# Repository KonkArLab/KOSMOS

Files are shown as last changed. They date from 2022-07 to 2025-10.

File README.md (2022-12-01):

# KOSMOS
An underwater observation tool

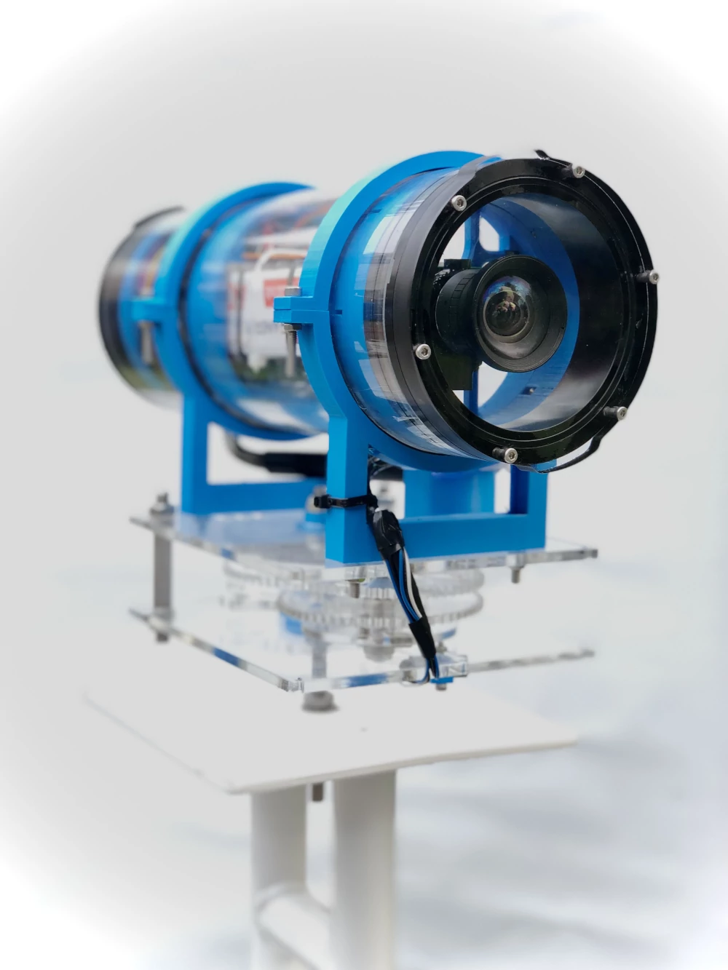
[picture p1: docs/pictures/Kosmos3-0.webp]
Kosmos
 

Cette œuvre est mise à disposition selon les termes de la [Licence Creative Commons Attribution - Pas d’Utilisation Commerciale - Partage dans les Mêmes Conditions 4.0 International.](https://creativecommons.org/licenses/by-nc-sa/4.0/) L'auteur à mentionner est Konk Ar Lab et Ifremer

Le KOSMOS est un programme de sciences participatives née du partenariat atypique
entre une institution scientifique, l’Ifremer, et un Tiers Lieu, le Konk Ar Lab, Fablab de
Concarneau. Cette caméra d’observation de la faune et de la flore sous marine côtière a
permis de réunir autour d’un projet commun, acteurs de la recherche scientifique et de la
société civile.

La fabrication du KOSMOS au Konk Ar Lab est un formidable exemple d’intelligence
collective. Bénévoles et scientifiques collaborent main dans la main afin de concevoir cet
outil en s’assurant qu’il soit reproductible par tous, peu coûteux et scientifiquement
viable, c’est à dire répondant aux exigences du protocole scientifique STAVIRO déjà validé pour l’observation
et le suivi des écosystèmes côtiers.

Ce sont ces trois enjeux qui ont motivé Dominique Pelletier, directrice de recherche
Écologie et Modèles pour l’Halieutique (EMH), à se tourner vers le Konk Ar Lab. En effet,
Dominique a d’ores et déjà développé deux caméras utilisées à travers le monde : le
STAVIRO et le MICADO. Cependant, leur mode de fabrication est limitant et ne permet
pas à tout acteur ou potentiel utilisateur (institution scientifique, parc naturel marin, citoyen) de s’emparer du
projet alors même que les besoins d’évaluation et de suivi sont croissants. Le KOSMOS
offre donc une solution à ce qui semblait être une impasse.

L’Ifremer s’est tourné vers le FabLab de Concarneau en sa qualité de lieu de facilitation
sociale par le numérique. Le Konk Ar Lab, implanté sur le territoire de Concarneau
Cornouailles Agglomération (CCA), est un lieu réunissant tout type de publics locaux
autour de projets numériques et techniques venus de divers horizons. Ce projet est donc
un moyen innovant de partager ses connaissances tant sur des aspects techniques,
mécaniques que biologiques ou écologiques.

Découvrir, partager, sensibiliser sont les thèmes centraux du projet KOSMOS. Un
programme de sciences participatives visant à réunir plaisanciers et scientifiques autour
de l’utilisation de la caméra en mer, verra le jour en 2023. L’objectif est de permettre à tout
un chacun de collecter des vidéos lors de sorties en mer et de les analyser. En offrant
ainsi de nouvelles données aux scientifiques, les observateurs développent ou
approfondissent leur connaissance du milieu côtier et offrent la possibilité de suivre son
évolution sur le long terme.

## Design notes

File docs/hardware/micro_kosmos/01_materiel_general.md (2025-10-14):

icon:material/hammer-screwdriver
# Matériel général

???+ Warning

    Tous les liens vers les sites fournisseurs sont mis à titre indicatif.  
    **Dans le but d'une démarche low tech privilégier la récupération plutôt que l'achat.**

    Certains composants tel que les vis peuvent être modifiés et ne dépendes que de ce que vous avez déjà et de ce dont vous avez besoin.
    Il faut aussi noter que certaines vis sont comprises dans certains kits, dans le tableau ci-dessous vous trouverez toutes les vis nécessaire y compris celles intégrées dans les kits proposés.

    Pour essayer de réduire les imports de produit venant de l'autre bout du monde. Nous avons réaliser un sourcing en essayant de faire attention à ce que les produits soient fabriqués et vendus en Europe. Ce n'est malheureusement pas le cas pour tous. Concernant la visserire nous avons référencer le fabriquant et fournisseur TID Inox, il réalise des ventes à l'unité et est spécialisé dans les commande pour le dIY. Ces prix ne sont intéressant que pour l'achat de petite quantité.

???+ note

    Pour désigner les spécificités d'une vis on utilise des lettres. Ici la lettre M signifie que la vis à un filetage métrique (ISO). Le chiffre qui suit le M correspond au diamètre en mm. La valeur d'après correspond à la longueur du filetage de la vis.

indice substituabilité :  
- :red_circle: : composant non modifiable  
- :orange_circle: : certains paramètres du composant non modifiables  
- :green_circle: : composant modifiable  

## Electronique :
| Partie | Visuel | Référence | Quantité | Dénomination | Usage | Substituabilité | Tips/Conseil |
|---|---|---|---|---|---|---|---|
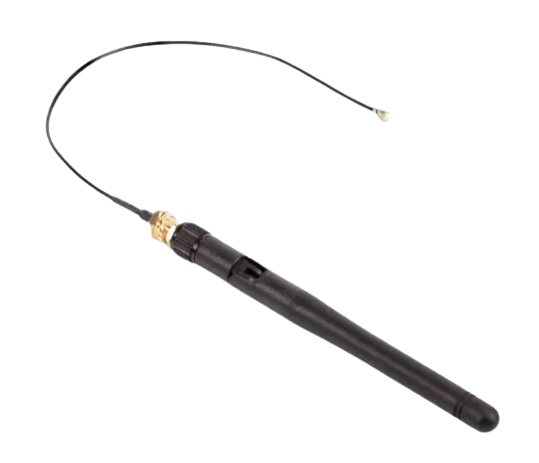
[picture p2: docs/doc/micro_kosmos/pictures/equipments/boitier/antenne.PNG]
antenne
|Boitier Electronique| |[Raspberry  SC0480](https://www.kubii.com/fr/modules-de-reseaux/3087-kit-antenne-officielle-raspberry-pi-3272496303287.html) | 1| Antenne |Permet d'augmenter la portée du signal |<blockquote> :red_circle: </blockquote><br> | |
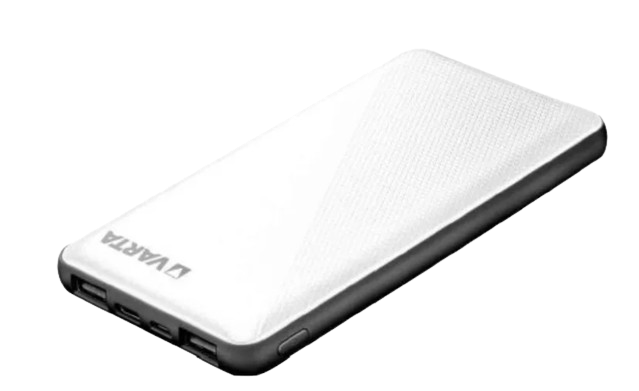
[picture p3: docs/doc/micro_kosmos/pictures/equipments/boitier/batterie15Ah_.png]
batterie
|Boitier Electronique| |[Varta 57977 101 111](https://fr.rs-online.com/web/p/batteries-externes/2309825?gb=s) | 1| batterie 15Ah |Alimente la raspberry |<blockquote> :green_circle: </blockquote><br> | |
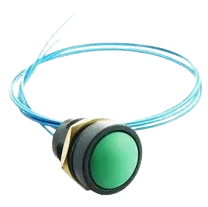
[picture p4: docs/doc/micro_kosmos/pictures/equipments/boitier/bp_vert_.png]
bp
|Boitier Electronique| |[ITW SWITCHES 49-59113](https://fr.farnell.com/itw-switches/49-59113/commutateur-rond-vert/dp/734093?ost=734093) | 1| bouton poussoir vert |"" |<blockquote> :green_circle: </blockquote><br> | |
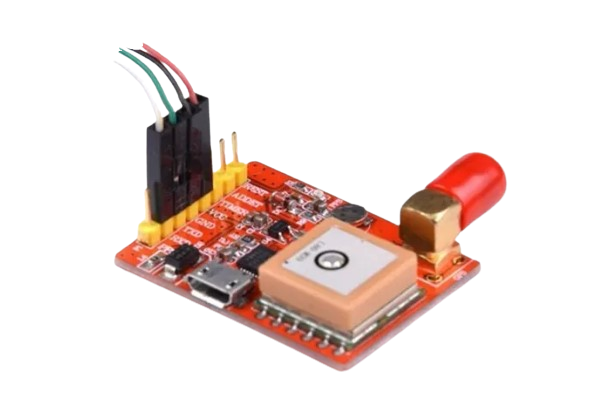
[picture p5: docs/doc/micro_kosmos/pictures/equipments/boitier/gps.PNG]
carte_gps
|Boitier Electronique| |[Raspberry RA168](https://www.kubii.com/fr/modules-de-reseaux/1922-module-gps-pour-raspberry-pi-kubii-3272496007888.html) | 1| carte gps |"" |<blockquote> :red_circle: </blockquote><br> | |
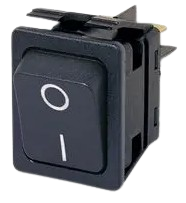
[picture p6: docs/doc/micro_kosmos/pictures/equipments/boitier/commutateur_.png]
commutateur
|Boitier Electronique| |[ARCOLECTRIC (BULGIN LIMITED) C6050ALAAC](https://fr.farnell.com/arcolectric/c6050alaac/commutateur-a-bascule-dpst-noir/dp/7674155)| 1| commutateur + cache étanche |Permet d'allumer et d'éteindre le système |<blockquote> :orange_circle: intérupteur avec auto maintient </blockquote><br> | |
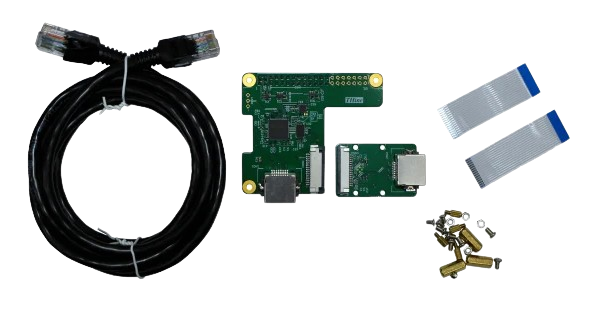
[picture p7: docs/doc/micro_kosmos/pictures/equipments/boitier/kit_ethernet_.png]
kit_ethernet
|Boitier Electronique| |[THine Solutions, Inc. THSER101](https://fr.rs-online.com/web/p/hat-et-complements-raspberry-pi/2206246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) | 1| kit d'extension ethernet |"Permettra à la camera et à la Raspberry de communiquer ensemble" |<blockquote> :red_circle: </blockquote><br> | |
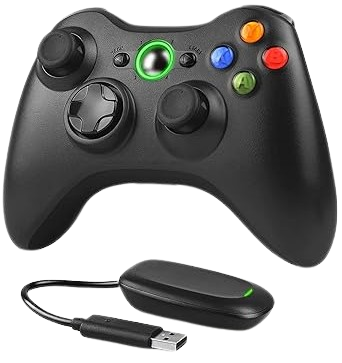
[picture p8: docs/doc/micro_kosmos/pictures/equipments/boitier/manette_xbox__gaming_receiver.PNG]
manette_Xbox
|Boitier Electronique| |[gaming_receiver](https://www.amazon.fr/Dhaose-Contr%C3%B4leur-Vibration-Bluetooth-Ergonomique/dp/B08JGMFRGC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) | 1| Manette Xbox + Wireless gaming receiver |Permet de controller kosmos (mouement, camera)  Permet de faire le lien avec la manète de Xbox et la crte raspberry |<blockquote> :red_circle: </blockquote><br> | |
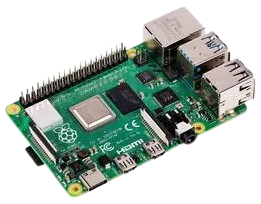
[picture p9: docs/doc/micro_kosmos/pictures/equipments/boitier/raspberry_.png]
raspberry
|Boitier Electronique| |[RASPBERRY-PI RPI4-MODBP-4GB](https://fr.farnell.com/raspberry-pi/rpi4-modbp-4gb/raspberry-pi-4-model-b-4gb/dp/3051887?st=rpi4) | 1| raspberry PI4 4GB |Contient le programme de fonctionnement du µkosmos |<blockquote> :red_circle: </blockquote><br> | |
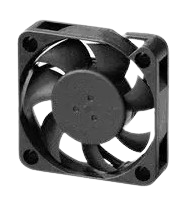
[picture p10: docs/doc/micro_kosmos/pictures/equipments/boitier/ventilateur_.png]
ventilateur
|Boitier Electronique| |[MULTICOMP MC002684](https://fr.farnell.com/multicomp/mc002684/ventilateur-40x40x10mm-5vdc/dp/3050784) | 1| ventilateur 5V |Permet de refroidir le système |<blockquote> :orange_circle: _5V_ </blockquote><br> | |
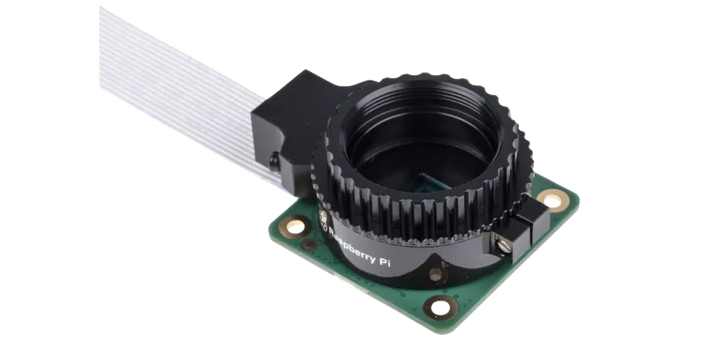
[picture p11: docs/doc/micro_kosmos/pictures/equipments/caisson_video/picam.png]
PiCam
|Caisson vidéo| |[Raspberry Pi SC0261](https://fr.rs-online.com/web/p/cameras-pour-raspberry-pi/2012852?gb=s) | 1| Camera raspberry Pi (Pi Cam) |Camera compatible avec la carte Rasberry Pi |<blockquote> :red_circle: </blockquote><br> | |
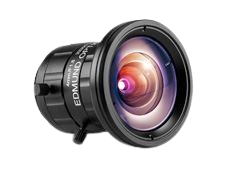
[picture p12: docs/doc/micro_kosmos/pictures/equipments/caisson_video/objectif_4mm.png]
objectif_4mm
|Caisson vidéo| |[TECHSPEC Objectif à distance focale fixe série UC 4mm](https://www.edmundoptics.fr/p/4mm-uc-series-fixed-focal-length-lens/2966/)  | 1| Objectif 4mm |Permet d'améliorer les performance de la Pi Cam |<blockquote> :red_circle: </blockquote><br> | |
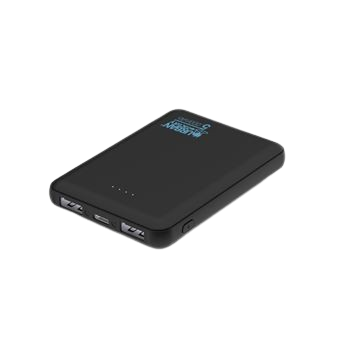
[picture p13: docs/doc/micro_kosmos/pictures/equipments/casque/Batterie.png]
batterie 5000
|Casque| |[Urban Factory UPB05UF](https://www.fnac.com/Batterie-externe-Urban-Factory-UPB05UF-Juicee-Max-Powerbank-5000-mAh-Noir/a16416729/w-4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) | 1| Batterie 500mAh |Alimente l'écran du casque de VR |<blockquote> :green_circle: </blockquote><br> | |
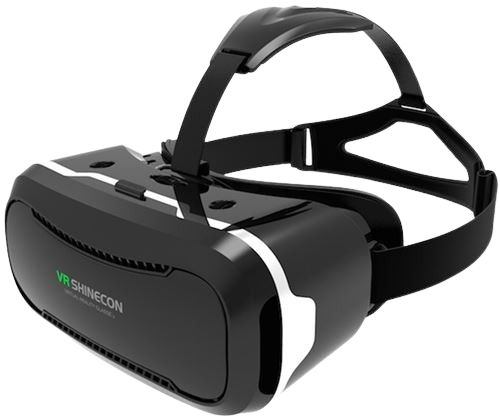
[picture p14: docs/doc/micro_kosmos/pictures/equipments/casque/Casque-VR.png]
casque VR
|Casque| |[EAN 3002637644654](https://www.fnac.com/mp33894226/Casque-VR-pour-Smartphone-Realite-Virtuelle-Lunette-Jeux-Reglage-Universel/w-4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) | 1| Casque de réalité virtuelle |permet de visualiser les image de la caméra |<blockquote> :green_circle: </blockquote><br> |Vous pouvez utiliser un simple écran, mais avec le soleil dehors les écrans sont souvent illisibles. Le casque permet de voir correctement les images; |

## Câble :
|Partie| Visuel | Référence | Quantité | Dénomination | Usage | Substituabilité | Tips/Conseil |
|---|---|---|---|---|---|---|---|
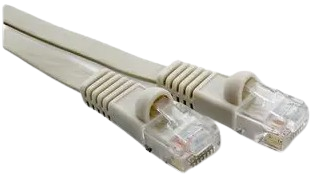
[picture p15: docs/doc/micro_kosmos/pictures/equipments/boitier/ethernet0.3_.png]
eternet0.3
|Boitier Electronique| |[VIDEK 2966-0.3F](https://fr.farnell.com/videk/2966-0-3f/lead-flat-cat6-utp-beige-0-3m/dp/1515103?ost=1515103)  | 1|ethernet 0.3m | Relie carte ethernet au raccord ethernet_externe |<blockquote> :orange_circle: _connectique ethernet_ </blockquote> <br> | |
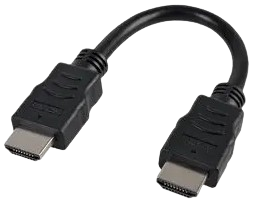
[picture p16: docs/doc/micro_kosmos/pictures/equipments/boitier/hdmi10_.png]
hdmi10
|Boitier Electronique| |[PRO SIGNAL PSG91337](https://fr.farnell.com/pro-signal/psg91337/hdmi-lead-black-0-15m/dp/3400642?ost=3400642)| 1| rallonge HDMI 10cm | Relie la raspberry au bulgin HDMI |<blockquote> :orange_circle: _connectique hdmi_ </blockquote> <br> | |
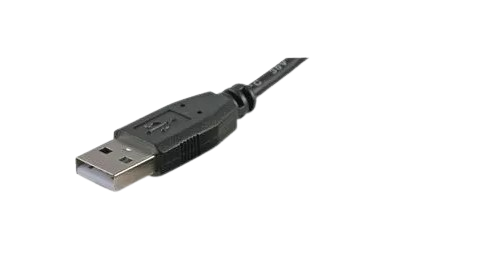
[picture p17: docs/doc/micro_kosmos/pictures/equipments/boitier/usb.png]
usb
|Boitier Electronique| |[KUB06861-NR](https://www.kubii.com/fr/alimentations/1501-1088-mini-cable-blanc-usb-micro-usb-kubii-3272496003491.html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) | 2|cable USB | Relie la batterie au commutateur <br><br> Relie le ventillateur à la carte |<blockquote> :orange_circle: _connectique usb_ </blockquote><br> |Récup <br><br> Seul le connecteur usb est important l'autre bout du cable sera coupé et relier à d'autre petit cable par une soudure |
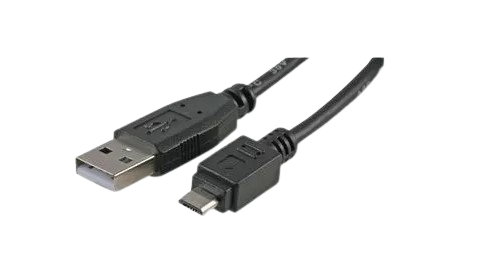
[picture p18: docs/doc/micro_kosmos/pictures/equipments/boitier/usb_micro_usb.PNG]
usb_micro_usb
|Boitier Electronique| |[KUB06861-NR](https://www.kubii.com/fr/alimentations/1501-1088-mini-cable-blanc-usb-micro-usb-kubii-3272496003491.html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) | 1|cable micro USB vers USB | Relie la raspberry à la carte gps |<blockquote> :orange_circle: _connectique usb et micro usb_ </blockquote><br> |Récup |
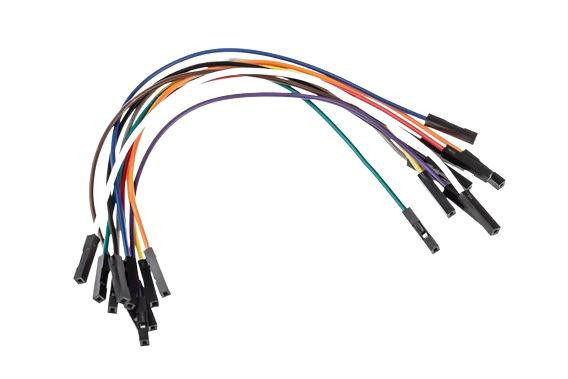
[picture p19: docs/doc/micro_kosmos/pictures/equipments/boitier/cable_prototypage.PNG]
cable_prototypage
|Boitier Electronique| |[JW008FF_DEL](https://www.kubii.com/fr/fils-cables-adaptateurs/1592-1424-kit-fils-cables-jumper-40-200-mm-3272496311220.html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) | 2|cable de prototypage | Relie des pins de la carte aux cables du bouton poussoir  |<blockquote> :green_circle: </blockquote><br> |Récup |
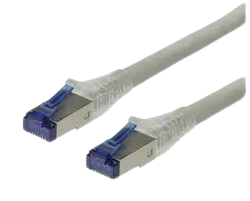
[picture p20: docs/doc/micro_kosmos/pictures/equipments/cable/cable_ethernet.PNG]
cable_ethernet
|Câble| |[ROLINE 	21.15.0871](https://fr.farnell.com/roline/21-15-0871/cordon-de-brassage-rj45-m-m-30m/dp/3003054?ost=21.15.0871) | 1| cable ethernet 15m |Permet "" |<blockquote> :orange_circle: _ethernet_ </blockquote><br> | |
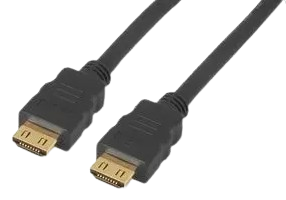
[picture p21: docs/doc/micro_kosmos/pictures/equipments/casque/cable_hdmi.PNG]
cable_hdmi
|Casque|  |[MIGRIP-HDMI-5](https://fr.farnell.com/clever-little-box/migrip-hdmi-5/cable-hdmi-male-male-verrouillage/dp/2373729) | 1|câble hdmi | Relie le casque au boitier électronique |<blockquote> :orange_circle: _connectique hdmi_</blockquote><br> | |
|Casque|usb_micro_usb  |[KUB06861-NR](https://www.kubii.com/fr/alimentations/1501-1088-mini-cable-blanc-usb-micro-usb-kubii-3272496003491.html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) | 1|câble micro usb - USB | Relie l'écran à la batterie |<blockquote> :orange_circle: _connectique usb et micro usb_</blockquote><br> | |

## Connecteur :
|Partie| Visuel | Référence | Quantité | Dénomination | Usage | Substituabilité | Tips/Conseil |
|---|---|---|---|---|---|---|---|
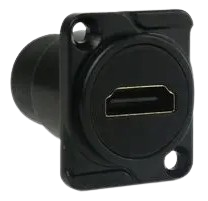
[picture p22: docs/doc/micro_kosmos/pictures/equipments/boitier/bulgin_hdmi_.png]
HDMI femelle/femelle
|Boitier Electronique| |[AMPHENOL AUDIO AC-HDMI-RRB](https://fr.farnell.com/amphenol/ac-hdmi-rrb/adaptateur-hdmi-type-d-fem-fem/dp/2951361?ost=ac-hdmi-rrb) | 1| HDMI femelle/femelle | Permet de connecter la raspberry au casque de Réalité Virtuelle (VR)|<blockquote> :orange_circle: _hdmi vers hdmi_ </blockquote><br> | |
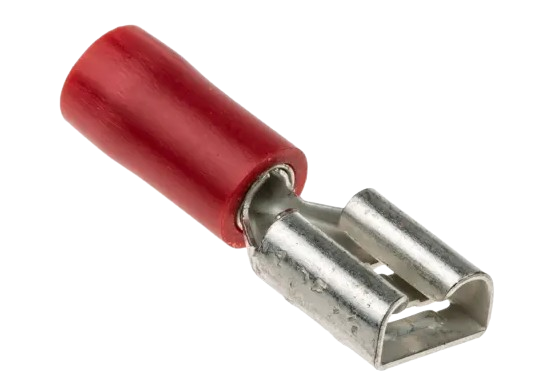
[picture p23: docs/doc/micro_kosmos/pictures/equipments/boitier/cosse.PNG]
cosse
|Boitier Electronique| |[RS PRO 534-339](https://fr.rs-online.com/web/p/cosses-faston/0534339?gb=s) | 4|connecteur cosse | Fait le lien entre les pins du commutateur et les câbles | <blockquote> :green_circle: </blockquote><br> | Les connecteurs cosses sont optionnel. Vous pouvez simplement réaliser des soudures entre les pins et les câbles |
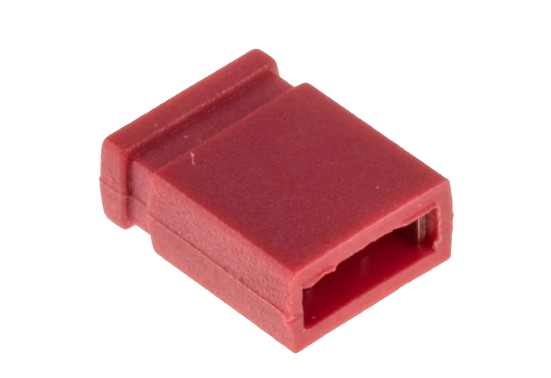
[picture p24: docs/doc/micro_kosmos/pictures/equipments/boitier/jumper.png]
jumper
|Boitier Electronique| |[jumper](https://fr.rs-online.com/web/p/cavaliers-et-shunts/2518531) | 1|jumper | Fait le lien entre deux pins de la carte ethernet pour chager le mode de fonctionnement |<blockquote> :green_circle: </blockquote><br> |Peut être remplacer par un câble de prototypage femelle/femelle |
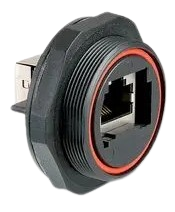
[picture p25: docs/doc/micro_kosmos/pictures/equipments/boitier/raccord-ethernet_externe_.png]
ethernet femelle/femelle
|Boitier Electronique| |[BULGIN LIMITED PX0839/90](https://fr.farnell.com/bulgin/px0839-90/connecteur-coupleur-cat5e-horizontal/dp/1687567?ost=px0839%2F90) | 1| ethernet femelle/femelle | Permet de connecter la carte ethernet au cable ethernet externe |<blockquote> :orange_circle: _ethernet vers ethernet_ </blockquote><br> | |
|Câble|dummy cap |[COB-1003](https://www.bluetrailengineering.com/product-page/cobalt-series-dummy-cap) | 1|capuchon protection cable | Permet de protéger le cable lorsqu'il n'est pas utilisé | <blockquote> :red_circle: </blockquote><br> | |
|Câble|locking sleeve |[COB-1001](https://www.bluetrailengineering.com/product-page/low-profile-locking-sleeve) | 1|fermeture capuchon protection |Permet de protéger le cable lorsqu'il n'est pas utilisé | <blockquote> :red_circle: </blockquote><br> | |
|Câble|ethernet renforcé |[BULGIN LIMITED PX0834/B](https://fr.farnell.com/bulgin/px0834-b/connecteur-precable-rj45/dp/9667733?st=bulgin%20px0834/b) | 1| connecteur ethernet | | <blockquote> :red_circle: </blockquote><br> | |
|Caisson vidéo|kit terminaison |[COB-3180-SS](https://bluerov-solutions.com/produkt/cobalt-series-cable-termination-kit-regular/) | 1|8 pin terminaison kit |Protège le connecteur lorsque le cable n'est pas branché  Une partie du kit est utiliser sur la cable |<blockquote> :red_circle: </blockquote><br> | |
|Caisson vidéo|8pin |[COB-1180-R1](https://www.bluetrailengineering.com/product-page/cobalt-series-bulkhead-connector) | 1| Connecteur 8 pin |Permet de faire le lien avec le "cable" et la carte de la PiCam |<blockquote> :red_circle: </blockquote><br> | |

## Mécanique :
|Partie| Visuel | Référence | Quantité | Dénomination | Usage | Substituabilité | Tips/Conseil |
|---|---|---|---|---|---|---|---|
|Boitier ELectroniquqe|boitier |[MULTICOMP PRO G3008](https://fr.farnell.com/multicomp/g3008/boitier-abs-240x160x90mm-ip65/dp/1526644?st=boitier%20ip65%20240%20mm)| 1| boitier 240 * 160 * 90 |Abrite les élément électroniques |<blockquote> :red_circle: </blockquote><br> | |
| | | 4| pied |Permet d'avoir la boite à plat |<blockquote> :green_circle: </blockquote><br> |Récup |
|Caisson vidéo|flange_cap |[BR-100276-002](https://bluerobotics.com/store/watertight-enclosures/locking-series/wte-end-cap-vp/) | 1| 2'' Flange Cap Aluminium 2 * M10 hole |Ferme le bas du tube, les deux ouverture permettrons de mettre la valve de pression et le connecteur 8pin |<blockquote> :red_circle: </blockquote><br> | |
|Caisson vidéo|oRing_flange |[BR-100628-998](https://bluerobotics.com/store/watertight-enclosures/2-series/wte-flange-vp/) | 1| 2'' O-Ring Flange |Ferme le haut du tube |<blockquote> :red_circle: </blockquote><br> | |
|Caisson vidéo|transparent_cap |[BR-100094](https://bluerobotics.com/store/watertight-enclosures/2-series/wte-end-cap-vp/) | 1| 2'' End Cap Acrylic |S'assemble sur O-Ring Flange pour fermer le haut du tube |<blockquote> :red_circle: </blockquote><br> | |
|Caisson vidéo|tube_etanche |[BR-100534-100](https://bluerobotics.com/store/watertight-enclosures/locking-series/wte-locking-tube-r1-vp/) | 1| tube étanche diametre: 50mm  longueur: 100mm  + 2 socles |Abrite l'installation de la camera |<blockquote> :red_circle: </blockquote><br> | |
|Caisson vidéo|connecteur pression |[BR-100804](https://bluerobotics.com/store/cables-connectors/penetrators/vent-asm-r1/) | 1| valve de pression |"Permet de purger le dispositif" |<blockquote> :red_circle: </blockquote><br> | |
|Trépied|plaque |[RS PRO 178-239](https://fr.rs-online.com/web/p/feuilles-metalliques/0178239?gb=s) | 1| plaque métalique 30mm*100mm | protège le socle supérieur pour fixer l'anneau d'attache |<blockquote> :green_circle: </blockquote><br> | |
|Trépied|plomb |[CAPERLAN 8655063](https://www.decathlon.fr/p/plomb-maquereau-long-peche-en-mer/_/R-p-335078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) | 3| plomb maquereau 600g | Ajoute du poids pour que le système coule et reste stable au fond de l'eau |<blockquote> :green_circle: </blockquote><br> | |
|Trépied|tube_alu |[3232630508800](https://www.mr-bricolage.fr/tube-rond-aluminium-16x1mm-1m-brut-cqfd.html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) | 2m| tube alu 16*1mm | Permettra de réaliser les pieds |<blockquote> :green_circle: </blockquote><br> | |

## Impression 3D :
|Partie| Visuel | Référence | Quantité | Dénomination | Usage |Substituabilité | Tips/Conseil |
|---|---:|---|---|---|---|---|---|
|Caisson vidéo|support |[support_carte](../../hardware/micro_kosmos/3Dprint_files/caisson_video/Support_carte_caisson.stl)| 1| support carte |Permet de fixer la carte ethernet |<blockquote> :red_circle: </blockquote><br> | |
|Casque|support_top_batterie |[support_top_batterie](../../hardware/micro_kosmos/3Dprint_files/casque/Support_batterie_BOT.stl)| 1| Support supérieur batterie |Partie haute de la boite dans laquelle la batterie sera maintenue |<blockquote> :red_circle: </blockquote><br> | |
|Casque|support_boy_batterie |[support_bot_batterie](../../hardware/micro_kosmos/3Dprint_files/casque/Support_batterie_TOP.stl)| 1| Support inférieur batterie |Partie basse de la boite dans laquelle la batterie sera maintenue |<blockquote> :red_circle: </blockquote><br> | |
|Casque|support_ecran |[support_ecran](../../hardware/micro_kosmos/3Dprint_files/casque/Support_ecran.stl)| 1|Support de l'écran |boite dans laquelle l'ecran sera maintenue |<blockquote> :red_circle: </blockquote><br> | |
|Trépied| Trepied_inf |[Trepied_SocleInferieur](../../hardware/micro_kosmos/3Dprint_files/trepied/Trepied_SocleInferieur.stl) | 1| partie basse |Piece dans laquel seront fixer les pieds |<blockquote> :red_circle: </blockquote><br> | |
|Trépied| Trepied_sup |[Trepied_SocleSupérieur](../../hardware/micro_kosmos/3Dprint_files/trepied/Trepied_SocleSupérieur.stl) | 1| partie haute |Piece qui permettra d'attacher l'anneau d'accroche |<blockquote> :red_circle: </blockquote><br> | |
|Trépied| Collier_inf |[Trepied_CollierInférieur](../../hardware/micro_kosmos/3Dprint_files/trepied/Trepied_CollierInférieur.stl) | 2| Ber* |Piece inférieur de maintient du tube étanche |<blockquote> :red_circle: </blockquote><br> | |
|Trépied| Collier_sup |[Trepied_CollierSupérieur](../../hardware/micro_kosmos/3Dprint_files/trepied/Trepied_CollierSupérieur.stl) | 2| fermeture du Ber |Piece suppérieur de maintient du tube étanche |<blockquote> :red_circle: </blockquote><br> | |

## Visserie :
|Partie| Visuel | Référence | Quantité | Dénomination | Usage | Substituabilité | Tips/Conseil |
|---|---|---|---|---|---|---|---|
|Boitier Electronique|ecrou_m3 |[RS PRO 189-563](https://fr.rs-online.com/web/p/ecrous-hexagonaux/0189563) | 6|écrou M3 |Permet fixer le bulgin hdmi et  le ventilateur |<blockquote> :green_circle: </blockquote><br> | |
|Boitier Electronique|vis_m2.5_5mm |[RS PRO 908-7649](https://fr.rs-online.com/web/p/vis-a-metaux/9087649) | 3|vis M2.5 * 5 mm |Permet de fixer la carte Ethernet avec la carte Raspberry |<blockquote> :orange_circle: _M2.5_ </blockquote><br> |Récup |
|Boitier Electronique|vis_m2.5_6mm |[RS PRO 526-928](https://fr.rs-online.com/web/p/vis-a-metaux/0526928) | 4|vis M2.5 * 6 mm |Permet de fixer la carte raspberry au boitier |<blockquote> :orange_circle: _M2.5_ </blockquote><br> | |
|Boitier Electronique|vis_m3_8mm |[RS PRO 914-1942](https://fr.rs-online.com/web/p/vis-a-metaux/9141942) | 2|vis M3 * 8 mm |Permet de fixer le bulgin hdmi |<blockquote>:green_circle:</blockquote><br> | |
|Boitier Electronique|vis_m3_16mm |[RS PRO 560-619](https://fr.rs-online.com/web/p/vis-a-metaux/0560619) | 4|vis M3 * 16 mm |Permet de fixer le ventilateur |<blockquote>:green_circle: </blockquote><br> | |
|Boitier Electronique|vis_m4_16mm |[RS PRO 190-513](https://fr.rs-online.com/web/p/vis-a-metaux/0190513) | 6|vis M4 * 16 mm |Permet la fermeture du boitier |<blockquote> :orange_circle: _M4_ </blockquote><br> | |
|Boitier Electronique|entretoise_filetee_15 |[RS PRO 184-286](https://fr.rs-online.com/web/p/entretoises-filetees/1842896) | 4|entretoise filetée M2.5 * 15 mm |Permet de surelever la carte raspberry |<blockquote> :orange_circle: _M2.5_ </blockquote><br> | |
|Boitier Electronique|entretoise_filetee_6  |[RS PRO 184-3014](https://fr.rs-online.com/web/p/entretoises-filetees/1843014) | 4|entretoise filetée  M2.5 * 6 mm |Permet de surelever la carte ethernet |<blockquote> :orange_circle: _M2.5_ </blockquote><br> | |
|Cable|manille |[RS PRO 124-4849](https://fr.rs-online.com/web/p/manilles/1244849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,+Stockage+et+manutention-_-1244849&matchtype=&pla-2260779340447&gad_source=1&gclid=EAIaIQobChMI7YCP0uXQhAMVzj8GAB0ZgAvmEAQYASABEgLiavD_BwE&gclsrc=aw.ds) | 3| manille |Permet d'accrocher un bout et de tirer sur le dispositif sans détériorier le cable et le connecteur | <blockquote> :green_circle: </blockquote><br> | |
|Caisson vidéo|ecrou_m1.6 |[RS PRO 179-5726](https://fr.rs-online.com/web/p/ecrous-hexagonaux/1795726) | 4|écrou M1.6 | |<blockquote> :red_circle: </blockquote><br> | |
|Caisson vidéo|ecrou_m3 |[RS PRO 189-563](https://fr.rs-online.com/web/p/ecrous-hexagonaux/0189563) | 12|écrou M3 |Permet d'assembler la carte ethernet, son support et la pi cam  |<blockquote> :red_circle: </blockquote><br> | |
|Caisson vidéo|vis_m1.6_10mm |[RS PRO 179-5696](https://fr.rs-online.com/web/p/vis-a-metaux/1795696) | 4|vis M1.6 * 10mm |Permet de fixer la carte ethernet à son support | <blockquote> :red_circle: </blockquote><br> | |
|Caisson vidéo|vis_m3_40 |[RS PRO 914-1652](https://fr.rs-online.com/web/p/vis-a-metaux/9141652) | 4|vis M3 * 40mm |Permet de fixer la Pi Cam au flange cap du tube |<blockquote> :red_circle: </blockquote><br> | |
|Casque| ecrou_m2 |RS PRO 248-4551 | 9|écrou M2 | | |
|Casque| vis_m2_4mm |[RS PRO 914-1624](https://fr.rs-online.com/web/p/vis-a-metaux/9141624) | 4|vis M2*4mm |Fixer l'ecran du casque à son support |<blockquote> :green_circle: </blockquote><br> | Récup  |
|Casque| vis_m2_6mm|[RS PRO 526-906](https://fr.rs-online.com/web/p/vis-a-metaux/0526906) | 5|vis M2*6mm |Fixer le boitier de la batterie au casque |<blockquote> :green_circle: </blockquote><br> | Récup |
|Casque|vis_m2_8mm|[RS PRO 914-1475](https://fr.rs-online.com/web/p/vis-a-metaux/9141475) | 4|vis M2*8mm |Fixer le couvercle du boitier de la batterie |<blockquote> :green_circle: </blockquote><br> | Récup |
|Trépied|anneau_m10 |[RS PRO 124-4841](https://fr.rs-online.com/web/p/anneaux-de-levage/1244841?gb=s) | 1| anneau d'accroche M10 A4 |Permet d'attacher un bout au micro kosmos |<blockquote> :green_circle: </blockquote><br> | |
|Trépied|clou |[RS PRO 177-6994](https://fr.rs-online.com/web/p/clous/1776994) | 3| clou |Permetra de crer une butée pour le socle inférieur |<blockquote> :green_circle: </blockquote><br> |peuvent être remplacé  par n'impourte quelle tige temps qu'elle est déformable |
|Trépied|ecrou_m4 |[RS PRO 521-872](https://fr.rs-online.com/web/p/ecrous-hexagonaux/0189579) | 6| écrou M4 | |<blockquote> :green_circle: </blockquote><br> | |
|Trépied|ecrou_m6 |[RS PRO 189-591](https://fr.rs-online.com/web/p/ecrous-hexagonaux/0189591) | 10| écrou M6 | |<blockquote> :green_circle: </blockquote><br> | |
|Trépied|ecrou_frein |[RS PRO 767-832](https://fr.rs-online.com/web/p/ecrous-hexagonaux/0767832) | 8| écrou frein  M6 |Evite au montage de se déserrer |<blockquote> :green_circle: </blockquote><br> |peuvent etre remplacé par un montage écrou contre écrou (auquel cas il faut ajouter 6 écrous M6) |
|Trépied|ecrou_oreilles_m6  |[RS PRO 521-872](https://fr.rs-online.com/web/p/ecrous-a-oreilles/0521872) | 12| écrou oreille M6 |Ecrou placée en bout des tiges filetées |<blockquote> :green_circle: </blockquote><br> | |
|Trépied| | | 1| fil de fer |"réduira le mouvement des pieds" |<blockquote> :green_circle: </blockquote><br> | |
|Trépied|rondelle_m6 |[RS PRO 189-658](https://fr.rs-online.com/web/p/rondelles/0189658) | 24| rondelle M6 | |<blockquote> :green_circle: </blockquote><br> | |
|Trépied|tige filetée |[RS PRO 530-321](https://fr.rs-online.com/web/p/tiges-filetees/0530321?gb=s) | 1m50| tige filletée M6 | Permet de faire le lien entre le socle inférieur et supérieur |<blockquote> :green_circle: </blockquote><br> | |
|Trépied|vis_m4_20mm |[RS PRO 187-1279](https://fr.rs-online.com/web/p/vis-a-six-pans/1871279) | 4| vis M4 * 20mm |Permet d'assembler les partie inférieur et supérieur du support du caisson vidéo |<blockquote> :green_circle: </blockquote><br> | |
|Trépied|vis_m4_35mm |[RS PRO 124-7349](https://fr.rs-online.com/web/p/vis-a-six-pans/1247349) | 2| vis M4 * 35mm |Permet de fixer le support du caisson vidéo au socle supérieur du trépied |<blockquote> :green_circle: </blockquote><br> | |
|Trépied|vis_m6_40mm |[RS PRO 187-1459](https://fr.rs-online.com/web/p/vis-a-six-pans/1871459) | 3| vis M6 * 40mm |Permet de fixer les plombs sur les pieds |<blockquote> :green_circle: </blockquote><br> | |
|Trépied|vis_m10_40mm |[RS PRO 190-383](https://fr.rs-online.com/web/p/vis-a-tete-hexagonale/0190383) | 1| vis M10 * 40mm |Permet de fixer l'anneau d'accroche |<blockquote> :green_circle: </blockquote><br> | |

## Consommable :
|Partie| Visuel | Référence | Quantité | Dénomination | Usage | Substituabilité | Tips/Conseil |
|---|---|---|---|---|---|---|---|
|Boitier Electronique| | | 10cm| gaine thermo retractable |"fait le liaison entre les différents câbles assemblés" |<blockquote> :red_circle: </blockquote><br> |Récup |
|Boitier Electronique| | | 10cm| velcro |Permet de maintenir les composants en place et de pouvoir les enlever facilement si besoin |<blockquote> :green_circle: </blockquote><br> |Récup  <br><br>  Le velcro est optionnel et peut être remplacer par un autre moyen de fixation |
|Câble|gaine dyneema |[]() | 1|gaine dyneema |Permet de créer des points d'accroche | <blockquote> :red_circle: </blockquote><br> | |
|Câble|gaine thermo |[RS PRO 700-4535](https://fr.rs-online.com/web/p/gaines-thermoretractables/7004535?gb=s) | 1|gaine thermo 6mm |Protège les connexions entre les câbles | <blockquote> :red_circle: </blockquote><br> | |
|Câble|![scotch]() |[scotch]() | 1|scotch |Protège les connexions entre les câbles |<blockquote> :green_circle: </blockquote><br> | |
|Casque|mousse_ruban |[RS-PRO 619-1786](https://fr.rs-online.com/web/p/rubans-mousse/6191786)| 1|Mousse ruban |Permet de maintenir certaines pièces et évite de les abimer |<blockquote> :green_circle: </blockquote><br> | |
|Trépied|mousse_ruban |[RS-PRO 619-1786](https://fr.rs-online.com/web/p/rubans-mousse/6191786) | 1| mousse en ruban |Permet d'avoir un contact parfait avec le tube plexy|<blockquote> :green_circle: </blockquote><br> | Peut être remplacer par un morceau de neoprene que l'on colle |
|Trépied|serre cable |[RS PRO 233-465](https://fr.rs-online.com/web/p/serre-cables/0233465?gb=s) | 3|serre cable 150mm  | Maintient les plombs maquereaux |<blockquote> :green_circle: </blockquote><br> | |

## Outils :
| Visuel | Référence | Quantité | Dénomination | Usage | Substituabilité | Tips/Conseil |
|---|---|---|---|---|---|---|
|||||||

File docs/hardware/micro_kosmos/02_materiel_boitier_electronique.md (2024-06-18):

# Materiel Boitier Electronique

## Electronique:
| Visuel | Référence | Quantité | Dénomination | Usage |Substituabilité | Tips/Conseil |
|---:|---|---|---|---|---|---|
|antenne |[Raspberry  SC0480](https://www.kubii.com/fr/modules-de-reseaux/3087-kit-antenne-officielle-raspberry-pi-3272496303287.html) | 1| Antenne |Permet d'augmenter la portée du signal |<blockquote> :red_circle: </blockquote><br> | |
|batterie |[Varta 57977 101 111](https://fr.rs-online.com/web/p/batteries-externes/2309825?gb=s) | 1| batterie 15Ah |Alimente la raspberry |<blockquote> :green_circle: </blockquote><br> | |
|bp |[ITW SWITCHES 49-59113](https://fr.farnell.com/itw-switches/49-59113/commutateur-rond-vert/dp/734093?ost=734093) | 1| bouton poussoir vert |"" |<blockquote> :green_circle: </blockquote><br> | |
|carte_gps |[Raspberry RA168](https://www.kubii.com/fr/modules-de-reseaux/1922-module-gps-pour-raspberry-pi-kubii-3272496007888.html) | 1| carte gps |"" |<blockquote> :red_circle: </blockquote><br> | |
|commutateur |[ARCOLECTRIC (BULGIN LIMITED) C6050ALAAC](https://fr.farnell.com/arcolectric/c6050alaac/commutateur-a-bascule-dpst-noir/dp/7674155)| 1| commutateur + cache étanche |Permet d'allumer et d'éteindre le système |<blockquote> :orange_circle: intérupteur avec auto maintient </blockquote><br> | |
|kit_ethernet |[THine Solutions, Inc. THSER101](https://fr.rs-online.com/web/p/hat-et-complements-raspberry-pi/2206246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) | 1| kit d'extension ethernet |"Permettra à la camera et à la Raspberry de communiquer ensemble" |<blockquote> :red_circle: </blockquote><br> | |
|manette_Xbox |[gaming_receiver](https://www.amazon.fr/Dhaose-Contr%C3%B4leur-Vibration-Bluetooth-Ergonomique/dp/B08JGMFRGC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) | 1| Manette Xbox + Wireless gaming receiver |Permet de controller kosmos (mouement, camera)  Permet de faire le lien avec la manète de Xbox et la crte raspberry |<blockquote> :red_circle: </blockquote><br> | |
|raspberry |[RASPBERRY-PI RPI4-MODBP-4GB](https://fr.farnell.com/raspberry-pi/rpi4-modbp-4gb/raspberry-pi-4-model-b-4gb/dp/3051887?st=rpi4) | 1| raspberry PI4 4GB |Contient le programme de fonctionnement du µkosmos |<blockquote> :red_circle: </blockquote><br> | |
|ventilateur |[MULTICOMP MC002684](https://fr.farnell.com/multicomp/mc002684/ventilateur-40x40x10mm-5vdc/dp/3050784) | 1| ventilateur 5V |Permet de refroidir le système |<blockquote> :orange_circle: _5V_ </blockquote><br> | |

## Cable:
| Visuel | Référence | Quantité | Dénomination | Usage | Substituabilité | Tips/Conseil |
|---:|---|---|---|---|---|---|
|eternet0.3 |[VIDEK 2966-0.3F](https://fr.farnell.com/videk/2966-0-3f/lead-flat-cat6-utp-beige-0-3m/dp/1515103?ost=1515103)  | 1|ethernet 0.3m | Relie carte ethernet au raccord ethernet_externe |<blockquote> :orange_circle: _connectique ethernet_ </blockquote> <br> | |
|hdmi10 |[PRO SIGNAL PSG91337](https://fr.farnell.com/pro-signal/psg91337/hdmi-lead-black-0-15m/dp/3400642?ost=3400642)| 1| rallonge HDMI 10cm | Relie la raspberry au bulgin HDMI |<blockquote> :orange_circle: _connectique hdmi_ </blockquote> <br> | |
|usb |[KUB06861-NR](https://www.kubii.com/fr/alimentations/1501-1088-mini-cable-blanc-usb-micro-usb-kubii-3272496003491.html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) | 2|cable USB | Relie la batterie au commutateur <br><br> Relie le ventillateur à la carte |<blockquote> :orange_circle: _connectique usb_ </blockquote><br> |Récup <br><br> Seul le connecteur usb est important l'autre bout du cable sera coupé et relier à d'autre petit cable par une soudure |
|usb_micro_usb |[KUB06861-NR](https://www.kubii.com/fr/alimentations/1501-1088-mini-cable-blanc-usb-micro-usb-kubii-3272496003491.html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) | 1|cable micro USB vers USB | Relie la raspberry à la carte gps |<blockquote> :orange_circle: _connectique usb et micro usb_ </blockquote><br> |Récup |
|cable_prototypage |[JW008FF_DEL](https://www.kubii.com/fr/fils-cables-adaptateurs/1592-1424-kit-fils-cables-jumper-40-200-mm-3272496311220.html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) | 2|cable de prototypage | Relie des pins de la carte aux cables du bouton poussoir  |<blockquote> :green_circle: </blockquote><br> |Récup |

## Connecteur:
| Visuel | Référence | Quantité | Dénomination | Usage | Substituabilité | Tips/Conseil |
|---:|---|---|---|---|---|---|
|HDMI femelle/femelle |[AMPHENOL AUDIO AC-HDMI-RRB](https://fr.farnell.com/amphenol/ac-hdmi-rrb/adaptateur-hdmi-type-d-fem-fem/dp/2951361?ost=ac-hdmi-rrb) | 1| HDMI femelle/femelle | Permet de connecter la raspberry au casque de Réalité Virtuelle (VR)|<blockquote> :orange_circle: _hdmi vers hdmi_ </blockquote><br> | |
|cosse |[RS PRO 534-339](https://fr.rs-online.com/web/p/cosses-faston/0534339?gb=s) | 4|connecteur cosse | Fait le lien entre les pins du commutateur et les câbles | <blockquote> :green_circle: </blockquote><br> | Les connecteurs cosses sont optionnel. Vous pouvez simplement réaliser des soudures entre les pins et les câbles |
|jumper |[jumper](https://fr.rs-online.com/web/p/cavaliers-et-shunts/2518531) | 1|jumper | Fait le lien entre deux pins de la carte ethernet pour chager le mode de fonctionnement |<blockquote> :green_circle: </blockquote><br> |Peut être remplacer par un câble de prototypage femelle/femelle |
|ethernet femelle/femelle |[BULGIN LIMITED PX0839/90](https://fr.farnell.com/bulgin/px0839-90/connecteur-coupleur-cat5e-horizontal/dp/1687567?ost=px0839%2F90) | 1| ethernet femelle/femelle | Permet de connecter la carte ethernet au cable ethernet externe |<blockquote> :orange_circle: _ethernet vers ethernet_ </blockquote><br> | |

## Mécanique:
| Visuel | Référence | Quantité | Dénomination | Usage |Substituabilité | Tips/Conseil |
|---:|---|---|---|---|---|---|
|boitier |[MULTICOMP PRO G3008](https://fr.farnell.com/multicomp/g3008/boitier-abs-240x160x90mm-ip65/dp/1526644?st=boitier%20ip65%20240%20mm)| 1| boitier 240 * 160 * 90 |Abrite les élément électroniques |<blockquote> :red_circle: </blockquote><br> | |
| | | 4| pied |Permet d'avoir la boite à plat |<blockquote> :green_circle: </blockquote><br> |Récup |

## Visserie:
| Visuel | Référence | Quantité | Dénomination | Usage | Substituabilité | Tips/Conseil |
|---|---|---|---|---|---|---|
|ecrou_m3 |[RS PRO 189-563](https://fr.rs-online.com/web/p/ecrous-hexagonaux/0189563) | 6|écrou M3 |Permet fixer le bulgin hdmi et  le ventilateur |<blockquote> :green_circle: </blockquote><br> | |
|vis_m2.5_5mm |[RS PRO 908-7649](https://fr.rs-online.com/web/p/vis-a-metaux/9087649) | 3|vis M2.5 * 5 mm |Permet de fixer la carte Ethernet avec la carte Raspberry |<blockquote> :orange_circle: _M2.5_ </blockquote><br> |Récup |
|vis_m2.5_6mm |[RS PRO 526-928](https://fr.rs-online.com/web/p/vis-a-metaux/0526928) | 4|vis M2.5 * 6 mm |Permet de fixer la carte raspberry au boitier |<blockquote> :orange_circle: _M2.5_ </blockquote><br> | |
|vis_m3_8mm |[RS PRO 914-1942](https://fr.rs-online.com/web/p/vis-a-metaux/9141942) | 2|vis M3 * 8 mm |Permet de fixer le bulgin hdmi |<blockquote>:green_circle:</blockquote><br> | |
|vis_m3_16mm |[RS PRO 560-619](https://fr.rs-online.com/web/p/vis-a-metaux/0560619) | 4|vis M3 * 16 mm |Permet de fixer le ventilateur |<blockquote>:green_circle: </blockquote><br> | |
|vis_m4_16mm |[RS PRO 190-513](https://fr.rs-online.com/web/p/vis-a-metaux/0190513) | 6|vis M4 * 16 mm |Permet la fermeture du boitier |<blockquote> :orange_circle: _M4_ </blockquote><br> | |
|entretoise_filetee_15 |[RS PRO 184-286](https://fr.rs-online.com/web/p/entretoises-filetees/1842896) | 4|entretoise filetée M2.5 * 15 mm |Permet de surelever la carte raspberry |<blockquote> :orange_circle: _M2.5_ </blockquote><br> | |
|entretoise_filetee_6  |[RS PRO 184-3014](https://fr.rs-online.com/web/p/entretoises-filetees/1843014) | 4|entretoise filetée  M2.5 * 6 mm |Permet de surelever la carte ethernet |<blockquote> :orange_circle: _M2.5_ </blockquote><br> | |

## Consommable:
| Visuel | Référence | Quantité | Dénomination | Usage |Substituabilité | Tips/Conseil |
|---:|---|---|---|---|---|---|
| | | 10cm| gaine thermo retractable |"fait le liaison entre les différents câbles assemblés" |<blockquote> :red_circle: </blockquote><br> |Récup |
| | | 10cm| velcro |Permet de maintenir les composants en place et de pouvoir les enlever facilement si besoin |<blockquote> :green_circle: </blockquote><br> |Récup  <br><br>  Le velcro est optionnel et peut être remplacer par un autre moyen de fixation |

## Outils:
- Tourne vis (Tête différentes en fonction des vis utilisées)
- Perçeuse
- Couronne perçeuse (permet de réaliser les trous pour les connecteurs)
- kit de soudure
- pistolet chauffant ou briquet
- cuteur

(Les images proviennent des sites fournisseurs)

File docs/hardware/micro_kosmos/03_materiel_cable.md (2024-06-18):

# Matériel Cable

## Cable:
| Visuel | Référence | Quantité | Dénomination | Usage |Substituabilité | Tips/Conseil |
|---:|---|---|---|---|---|---|
|cable_ethernet |[ROLINE 	21.15.0871](https://fr.farnell.com/roline/21-15-0871/cordon-de-brassage-rj45-m-m-30m/dp/3003054?ost=21.15.0871) | 1| cable ethernet 15m |Permet "" |<blockquote> :orange_circle: _ethernet_ </blockquote><br> | |

## Connecteur:
| Visuel | Référence | Quantité | Dénomination | Usage |Substituabilité | Tips/Conseil |
|---:|---|---|---|---|---|---|
|dummy cap |[COB-1003](https://www.bluetrailengineering.com/product-page/cobalt-series-dummy-cap) | 1|capuchon protection cable | Permet de protéger le cable lorsqu'il n'est pas utilisé | <blockquote> :red_circle: </blockquote><br> | |
|locking sleeve |[COB-1001](https://www.bluetrailengineering.com/product-page/low-profile-locking-sleeve) | 1|fermeture capuchon protection |Permet de protéger le cable lorsqu'il n'est pas utilisé | <blockquote> :red_circle: </blockquote><br> | |
|ethernet renforcé |[BULGIN LIMITED PX0834/B](https://fr.farnell.com/bulgin/px0834-b/connecteur-precable-rj45/dp/9667733?st=bulgin%20px0834/b) | 1| connecteur ethernet | | <blockquote> :red_circle: </blockquote><br> | |

## Visserie:
| Visuel | Référence | Quantité | Dénomination | Usage |Substituabilité | Tips/Conseil |
|---:|---|---|---|---|---|---|
|manille |[RS PRO 124-4849](https://fr.rs-online.com/web/p/manilles/1244849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,+Stockage+et+manutention-_-1244849&matchtype=&pla-2260779340447&gad_source=1&gclid=EAIaIQobChMI7YCP0uXQhAMVzj8GAB0ZgAvmEAQYASABEgLiavD_BwE&gclsrc=aw.ds) | 3| manille |Permet d'accrocher un bout et de tirer sur le dispositif sans détériorier le cable et le connecteur | <blockquote> :green_circle: </blockquote><br> | |

## Consommable :
| Visuel | Référence | Quantité | Dénomination | Usage |Substituabilité | Tips/Conseil |
|---:|---|---|---|---|---|---|
|gaine dyneema |[]() | 1|gaine dyneema |Permet de créer des points d'accroche | <blockquote> :red_circle: </blockquote><br> | |
|gaine thermo |[RS PRO 700-4535](https://fr.rs-online.com/web/p/gaines-thermoretractables/7004535?gb=s) | 1|gaine thermo 6mm |Protège les connexions entre les câbles | <blockquote> :red_circle: </blockquote><br> | |
|![scotch]() |[scotch]() | 1|scotch |Protège les connexions entre les câbles |<blockquote> :green_circle: </blockquote><br> | |

## Outils
| Visuel | Référence | Quantité | Dénomination | Usage |Substituabilité | Tips/Conseil |
|---:|---|---|---|---|---|---|
|![kit sertissage]() |[kit sertissage]() | 1|kit sertissage câble ethernet |Permet d'assembler le connecteur sur le câble ethernet | <blockquote> :red_circle: </blockquote><br> | |

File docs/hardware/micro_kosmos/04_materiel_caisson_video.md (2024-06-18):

# Materiel caisson vidéo

## Electronique:
| Visuel | Référence | Quantité | Dénomination | Usage |Substituabilité | Tips/Conseil |
|---:|---|---|---|---|---|---|
|PiCam |[Raspberry Pi SC0261](https://fr.rs-online.com/web/p/cameras-pour-raspberry-pi/2012852?gb=s) | 1| Camera raspberry Pi (Pi Cam) |Camera compatible avec la carte Rasberry Pi |<blockquote> :red_circle: </blockquote><br> | |
|objectif_4mm |[TECHSPEC Objectif à distance focale fixe série UC 4mm](https://www.edmundoptics.fr/p/4mm-uc-series-fixed-focal-length-lens/2966/)  | 1| Objectif 4mm |Permet d'améliorer les performance de la Pi Cam |<blockquote> :red_circle: </blockquote><br> | |

## Connecteur:
| Visuel | Référence | Quantité | Dénomination | Usage |Substituabilité | Tips/Conseil |
|---:|---|---|---|---|---|---|
|kit terminaison |[COB-3180-SS](https://bluerov-solutions.com/produkt/cobalt-series-cable-termination-kit-regular/) | 1|8 pin terminaison kit |Protège le connecteur lorsque le cable n'est pas branché  Une partie du kit est utiliser sur la cable |<blockquote> :red_circle: </blockquote><br> | |
|8pin |[COB-1180-R1](https://www.bluetrailengineering.com/product-page/cobalt-series-bulkhead-connector) | 1| Connecteur 8 pin |Permet de faire le lien avec le "cable" et la carte de la PiCam |<blockquote> :red_circle: </blockquote><br> | |

## Mécanique:
| Visuel | Référence | Quantité | Dénomination | Usage |Substituabilité | Tips/Conseil |
|---:|---|---|---|---|---|---|
|flange_cap |[BR-100276-002](https://bluerobotics.com/store/watertight-enclosures/locking-series/wte-end-cap-vp/) | 1| 2'' Flange Cap Aluminium 2 * M10 hole |Ferme le bas du tube, les deux ouverture permettrons de mettre la valve de pression et le connecteur 8pin |<blockquote> :red_circle: </blockquote><br> | |
|oRing_flange |[BR-100628-998](https://bluerobotics.com/store/watertight-enclosures/2-series/wte-flange-vp/) | 1| 2'' O-Ring Flange |Ferme le haut du tube |<blockquote> :red_circle: </blockquote><br> | |
|transparent_cap |[BR-100094](https://bluerobotics.com/store/watertight-enclosures/2-series/wte-end-cap-vp/) | 1| 2'' End Cap Acrylic |S'assemble sur O-Ring Flange pour fermer le haut du tube |<blockquote> :red_circle: </blockquote><br> | |
|tube_etanche |[BR-100534-100](https://bluerobotics.com/store/watertight-enclosures/locking-series/wte-locking-tube-r1-vp/) | 1| tube étanche diametre: 50mm  longueur: 100mm  + 2 socles |Abrite l'installation de la camera |<blockquote> :red_circle: </blockquote><br> | |
|connecteur pression |[BR-100804](https://bluerobotics.com/store/cables-connectors/penetrators/vent-asm-r1/) | 1| valve de pression |"Permet de purger le dispositif" |<blockquote> :red_circle: </blockquote><br> | |

## Impresion 3D:
| Visuel | Référence | Quantité | Dénomination | Usage |Substituabilité | Tips/Conseil |
|---:|---|---|---|---|---|---|
|support |[support_carte](../../hardware/micro_kosmos/3Dprint_files/caisson_video/Support_carte_caisson.stl)| 1| support carte |Permet de fixer la carte ethernet |<blockquote> :red_circle: </blockquote><br> | |

## Visserie:
| Visuel | Référence | Quantité | Dénomination | Usage |Substituabilité | Tips/Conseil |
|---:|---|---|---|---|---|---|
|ecrou_m1.6 |[RS PRO 179-5726](https://fr.rs-online.com/web/p/ecrous-hexagonaux/1795726) | 4|écrou M1.6 | |<blockquote> :red_circle: </blockquote><br> | |
|ecrou_m3 |[RS PRO 189-563](https://fr.rs-online.com/web/p/ecrous-hexagonaux/0189563) | 12|écrou M3 |Permet d'assembler la carte ethernet, son support et la pi cam  |<blockquote> :red_circle: </blockquote><br> | |
|vis_m1.6_10mm |[RS PRO 179-5696](https://fr.rs-online.com/web/p/vis-a-metaux/1795696) | 4|vis M1.6 * 10mm |Permet de fixer la carte ethernet à son support | <blockquote> :red_circle: </blockquote><br> | |
|vis_m3_40 |[RS PRO 914-1652](https://fr.rs-online.com/web/p/vis-a-metaux/9141652) | 4|vis M3 * 40mm |Permet de fixer la Pi Cam au flange cap du tube |<blockquote> :red_circle: </blockquote><br> | |

(Les images proviennent des sites constructeurs)

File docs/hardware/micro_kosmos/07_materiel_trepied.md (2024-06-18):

# Materiel Trépied

## Mécanique:
| Visuel | Référence | Quantité | Dénomination | Usage |Substituabilité | Tips/Conseil |
|---:|---|---|---|---|---|---|
|plaque |[RS PRO 178-239](https://fr.rs-online.com/web/p/feuilles-metalliques/0178239?gb=s) | 1| plaque métalique 30mm*100mm | protège le socle supérieur pour fixer l'anneau d'attache |<blockquote> :green_circle: </blockquote><br> | |
|plomb |[CAPERLAN 8655063](https://www.decathlon.fr/p/plomb-maquereau-long-peche-en-mer/_/R-p-335078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) | 3| plomb maquereau 600g | Ajoute du poids pour que le système coule et reste stable au fond de l'eau |<blockquote> :green_circle: </blockquote><br> | |
|tube_alu |[3232630508800](https://www.mr-bricolage.fr/tube-rond-aluminium-16x1mm-1m-brut-cqfd.html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) | 2m| tube alu 16*1mm | Permettra de réaliser les pieds |<blockquote> :green_circle: </blockquote><br> | |

## Impression 3D:
| Visuel | Référence | Quantité | Dénomination | Usage |Substituabilité | Tips/Conseil |
|---:|---|---|---|---|---|---|
| Trepied_inf |[Trepied_SocleInferieur](../../hardware/micro_kosmos/3Dprint_files/trepied/Trepied_SocleInferieur.stl) | 1| partie basse |Piece dans laquel seront fixer les pieds |<blockquote> :red_circle: </blockquote><br> | |
| Trepied_sup |[Trepied_SocleSupérieur](../../hardware/micro_kosmos/3Dprint_files/trepied/Trepied_SocleSupérieur.stl) | 1| partie haute |Piece qui permettra d'attacher l'anneau d'accroche |<blockquote> :red_circle: </blockquote><br> | |
| Collier_inf |[Trepied_CollierInférieur](../../hardware/micro_kosmos/3Dprint_files/trepied/Trepied_CollierInférieur.stl) | 2| Ber* |Piece inférieur de maintient du tube étanche |<blockquote> :red_circle: </blockquote><br> | |
| Collier_sup |[Trepied_CollierSupérieur](../../hardware/micro_kosmos/3Dprint_files/trepied/Trepied_CollierSupérieur.stl) | 2| fermeture du Ber |Piece suppérieur de maintient du tube étanche |<blockquote> :red_circle: </blockquote><br> | |
*Ber : correspont en marine à la charpente qui maintient un bateau en traveaux 

## Visserie:
| Visuel | Référence | Quantité | Dénomination | Usage |Substituabilité | Tips/Conseil |
|---:|---|---|---|---|---|---|
|anneau_m10 |[RS PRO 124-4841](https://fr.rs-online.com/web/p/anneaux-de-levage/1244841?gb=s) | 1| anneau d'accroche M10 A4 |Permet d'attacher un bout au micro kosmos |<blockquote> :green_circle: </blockquote><br> | |
|clou |[RS PRO 177-6994](https://fr.rs-online.com/web/p/clous/1776994) | 3| clou |Permetra de crer une butée pour le socle inférieur |<blockquote> :green_circle: </blockquote><br> |peuvent être remplacé  par n'impourte quelle tige temps qu'elle est déformable |
|ecrou_m4 |[RS PRO 521-872](https://fr.rs-online.com/web/p/ecrous-hexagonaux/0189579) | 6| écrou M4 | |<blockquote> :green_circle: </blockquote><br> | |
|ecrou_m6 |[RS PRO 189-591](https://fr.rs-online.com/web/p/ecrous-hexagonaux/0189591) | 10| écrou M6 | |<blockquote> :green_circle: </blockquote><br> | |
|ecrou_frein |[RS PRO 767-832](https://fr.rs-online.com/web/p/ecrous-hexagonaux/0767832) | 8| écrou frein  M6 |Evite au montage de se déserrer |<blockquote> :green_circle: </blockquote><br> |peuvent etre remplacé par un montage écrou contre écrou (auquel cas il faut ajouter 6 écrous M6) |
|ecrou_oreilles_m6  |[RS PRO 521-872](https://fr.rs-online.com/web/p/ecrous-a-oreilles/0521872) | 12| écrou oreille M6 |Ecrou placée en bout des tiges filetées |<blockquote> :green_circle: </blockquote><br> | |
| | | 1| fil de fer |"réduira le mouvement des pieds" |<blockquote> :green_circle: </blockquote><br> | |
|rondelle_m6 |[RS PRO 189-658](https://fr.rs-online.com/web/p/rondelles/0189658) | 24| rondelle M6 | |<blockquote> :green_circle: </blockquote><br> | |
|tige filetée |[RS PRO 530-321](https://fr.rs-online.com/web/p/tiges-filetees/0530321?gb=s) | 1m50| tige filletée M6 | Permet de faire le lien entre le socle inférieur et supérieur |<blockquote> :green_circle: </blockquote><br> | |
|vis_m4_20mm |[RS PRO 187-1279](https://fr.rs-online.com/web/p/vis-a-six-pans/1871279) | 4| vis M4 * 20mm |Permet d'assembler les partie inférieur et supérieur du support du caisson vidéo |<blockquote> :green_circle: </blockquote><br> | |
|vis_m4_35mm |[RS PRO 124-7349](https://fr.rs-online.com/web/p/vis-a-six-pans/1247349) | 2| vis M4 * 35mm |Permet de fixer le support du caisson vidéo au socle supérieur du trépied |<blockquote> :green_circle: </blockquote><br> | |
|vis_m6_40mm |[RS PRO 187-1459](https://fr.rs-online.com/web/p/vis-a-six-pans/1871459) | 3| vis M6 * 40mm |Permet de fixer les plombs sur les pieds |<blockquote> :green_circle: </blockquote><br> | |
|vis_m10_40mm |[RS PRO 190-383](https://fr.rs-online.com/web/p/vis-a-tete-hexagonale/0190383) | 1| vis M10 * 40mm |Permet de fixer l'anneau d'accroche |<blockquote> :green_circle: </blockquote><br> | |

## Consommable:
| Visuel | Référence | Quantité | Dénomination | Usage |Substituabilité | Tips/Conseil |
|---:|---|---|---|---|---|---|
|mousse_ruban |[RS-PRO 619-1786](https://fr.rs-online.com/web/p/rubans-mousse/6191786) | 1| mousse en ruban |Permet d'avoir un contact parfait avec le tube plexy|<blockquote> :green_circle: </blockquote><br> | Peut être remplacer par un morceau de neoprene que l'on colle |
|serre cable |[RS PRO 233-465](https://fr.rs-online.com/web/p/serre-cables/0233465?gb=s) | 3|serre cable 150mm  | Maintient les plombs maquereaux |<blockquote> :green_circle: </blockquote><br> | |

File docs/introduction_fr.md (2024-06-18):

icon:material/application-brackets-outline
# Introduction

La présente documentation cherche à permettre à des personnes où des groupes de s'approprier la méthode d'observation participative de la biodiversité sous-marine. Elle cherche à détailler les étapes d'un tel projet allant de la fabrication d'un ou plusieurs systèmes jusqu'au traitement des images en passant par le déploiement et les usages en mer. 

## 1/ Détail de la présente documentation 

La présente documentation est mise en page par [read the doc](https://readthedocs.org/) et hébergé sur [GitHub](https://github.com/). 
Si vous êtes un utilisateur, pour suivre simplement la fabrication nous vous recommandons de rester sur la version read the doc. Si vous souhaitez nous aider et contribuer au projet, rendez-vous sur github après avoir lu la partie de la documentation qui traite de la contribution. 

## 2/ Prérequis informatiques
Toute la documentation du KOSMOS est réalisée dès que cela est possible avec des outils numériques et informatiques libres. Pour pouvoir suivre et éditer cette documentation, il est nécéssaire d'avoir à disposition :

 - Pour suivre les installations et la gestion des données : Un ordinateur sur un OS Unix (Linux, Ubuntu...) ;
 - Pour utiliser la nomenclature : [Libre office](https://doc.ubuntu-fr.org/libreoffice) ;
 - Pour progammer la découpe des engrenages avec la CNC : Se créer un compte sur le logiciel en ligne [Easel](https://www.inventables.com/technologies/easel) ;
 - Pour éditer la documentation : Editeur de texte classique ([gedit](https://doc.ubuntu-fr.org/gedit)) ou pour markdown ([Ghostwriter](https://ghostwriter.kde.org/)) ;
 - Si besoin de modifier les modèles 3D ou visuels : [Fusion 360 (Autodesk) (sur windows ou mac uniquement)la version gratuite pour un usage personnelle suffit](https://www.autodesk.fr/products/fusion-360/personal) ;
 - Pour modifier le dessin du circuit imprimé : [Kicad](https://www.kicad.org/download/ubuntu/);
 - Pour installer la Raspberry pi : [Raspberry pi Imager](https://www.raspberrypi.com/software/) ;
 - Pour les graphismes et le dessin vectoriel nous utilisons [Inkscape](https://doc.ubuntu-fr.org/inkscape) ;

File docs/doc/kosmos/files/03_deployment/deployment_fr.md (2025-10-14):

icon:material/waves
# Déploiement de Kosmos

## 1- Démarage

## 2- Remise en route
Cette partie explique les étapes de remise en route du système KOSMOS après un temps d'unitilisation.

### 2.1- Mise à jour du software
### Vérification de l'OS
- Vérifier la version de l'OS sur la carte SD de la Raspeberry Pi.
La dernière version de l'OS est Debian 12, (si la version est différente de la dernière version, réinstaller l'OS)
- Taper dans un terminal
```
cat /ect/os-release
```

### Vérification du programme
- Vérifier ensuite que le code est à jour
Toujours dans le terminal, vérifier que vous êtes bien sur la branche `dev_stereo` et récupérer la dernière version du code
```
git checkout dev_stereo //Vérifier la branche sur laquelle on se trouve
git pull //Récupérer la dernière version du code
```
- Vérifier que les dossiers CSV et Vidéo de la clé USB sont bien vides pour ne pas avoir de porblème de stockage

### 2.2- Vérification de la partie hardware
### Vérification des engrenages moteur
- Ouvrer le caisson des engrenages du moteur
- Faire tourner les engrenages manuellement pour s'assurer que rien ne bloque

### Mise au point de la caméra

???+ Note

        Pour être optimal, les réglages doivent s'effectuer dans une atmosphère lumineuse

- La première étape consiste à oter le filtre IR présent sur le capteur de la picam afin de maximiser le nombre de photons incidents. Pour cela on peut suivre le [guide](https://www.raspberrypi.com/documentation/accessories/camera.html#filter-removal) proposé par Raspberry.
- Cette étape réalisée, on nettoiera toutes les surfaces avec un chiffon microfibre puis on remontera l'objectif Edmund sur le capteur. Ré-assembler enfin ce module optique sur le système.
- Pour faire la mise au point de la caméra, le système ne sera pas placé dans le caisson. On branchera par ailleurs un écran à la Raspberry pour visualiser ce que filme la caméra.
- Une fois l'écran branché, on allumera le système et on attendra que le système KOSMOS soit en STAND BY.
- Dans l'interface WEB, modifier le paramètre `05_SYSTEM_shutdown` pour le mettre à 0 et effectuer un `Reboot`. Aller ensuite dans l'onglet `Camera` et éteindre arrêter le système KOSMOS en appuyant sur `Shutdown`. (Cette manipulation permet d'arrêter le script KOSMOS sans éteindre la Rpi. La caméra peut ainsi être utilisée.)
- Dans le terminal, taper ```rpicam-hello --timeout 0 ``` Cette instruction permet d'afficher le preview. Pour le quitter il suffira de taper ```Ctrl + C ```
- Ouvrir à fond l'objectif (le petit point blanc devant 1.8) pour avoir une profondeur de champ minimale. Réaliser le focus sur l'infini (par exemple sur les feuilles d'un arbre au loin) avec la bague puis la bloquer solidement. Fermer enfin l'objectif, le petit point blanc sur 6, pour augmenter la profondeur de champ. Bloquer la bague d'ouverture dans cette position. Vérifier que le focus est toujours bon (le fait de serrer les bagues peut parfois les faire bouger.)
- Sortir du preview puis redémarrer la Raspberry Pi. Le soft kosmos va se remettre en route. Dans l'interface web, remettre le paramètre  `05_SYSTEM_shutdown` sur 1. Effectuer un `Reboot` puis éteindre le système avec un `Shutdown`.

### Lubrification des joints

???+ Warning

        Cette étape est indispensable et est à réaliser avec soin, elle assure l'étanchéité du système

- Déviser les connecteurs des caps  
  joints
- Vérifier qu'il n'y ait pas de cheveux sur vos joints  
- Graisser chaque joint (la couche de graisse doit être fine et homogène)  
  graisse
- Reviser les connecteurs sans oublier les joints  
  joints_valve
- Serrer pour assurer l'étanchéité  
  serrage_exte
  serrage_inte

- Déviser les caps des extrémitées (hublot transparent, et caps noir)
- Répéter les opérations ci dessus  
  joint_top

- Enlever les joints autour des "entretoises"
- Répéter les opérations ci dessus  
  joint_entretoise

### Encapsulation
- Fermer le caisson de kosmos  
   

### Vérification du fonctionnement géneral de Kosmos
- Démarrer la caméra
- Connectez vous à l'interface web (10.42.0.1)
- Vérifier les paramètres dans l'onglet config:
   - 00_system_mode :
   - 01_system_record_button_gpio :
   - 02_system_stop_button_gpio :
   - 03_system_led_b :
   - 04_system_led_r :
   - 05_system_shutdown :
   - 06_system_moteur :
   - 10_motor_esc_gpio :
   - 11_motor_power_gpio :
   - 12_motor_button_gpio :
   - 13_motor_vitesse_min : 
   - 14_motor_vitesse_favorite : 
   - 15_motor_pause_time : 
   - 20_csv_step_time : 
   - 21_csc_file_name : 
   - 30_picam_file_name : 
   - 31_picam_resolution_x : 
   - 32_picam_resolution_y : 
   - 33_picam_preview :
   - 34_picam_framérate : 
   - 35_picam_record_time :
   - 36_picam_conversion_mp4 :
   - 37_picam_awb :
     
- Vérifier avec le live que la caméra est positionnée de façon à ce que l'image soit droite
- Démarer une vidéo
- Observer si le moteur tourne correctement
- Arreter la video et vérifier que l'enregistrement c'est bien passé (création d'un fichier cvs et conversion du fichier vidéo h264 en mp4)

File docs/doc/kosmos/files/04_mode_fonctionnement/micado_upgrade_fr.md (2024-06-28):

icon:fontawesome/regular/hourglass-half
# Upgrade au mode Automatique

## 1/ Principe

Le principe du mode MICADO est de pouvoir laisser le KOSMOS en position pendant plusieurs jours. L'objectif n'est pas de le faire tourner pendant toute la durée d'immersion comme pour le mode STAVIRO. Le but du mode MICADO est d'activer le système sur des horaires bien précis rentré par l'utilisateur auparavant et de faire tourner le KOSMOS pendant une durée rentrée au préalable par l'utilisateur ( en général 15 minutes ).  Ce système permet de faire plusieurs prélèvements de vidéos au même endroit sur des plages horaires précises sans à avoir à remonter le KOSMOS entre chaque prise.
Pour réaliser ceci, nous utilisons une carte Adafruit Trinket 1501 reliée à un module RTC. Celle-ci permettra de contrôler l’alimentation du système grâce à un relais. Elle allumera la carte RaspBerry sur les plages horaires rentréesconso par l’utilisateur. Nous sommes obligé d'utiliser une carte auxiliaire car le mode veille de la carte Raspberry consomme énormément. Le gros avantage de cette carte est sa très faible consommation.
Un autre avantage de cette carte est sa toute petite taille : elle mesure 31mm x 15.5mm x 5mm. Elle dispose des ports I2C nécessaires pout être connectée au module RTC et d’une sortie GPIO permettant de contrôler le relais.

## 2/ Réalisation

Pour commencer, un relai brancher en série sur l'alimentation 5v de la raspberry. Ce relai sera piloté par l'arduino. 
Voici le montage entre le module RTC, l’Adafruit et le relais :

MU2-1

La carte Adafruit est assez particulière à programmer. Elle n'est pas 100% compatible avec l'IDE Arduino : Il faut donc opérer quelques astuces. Nous avons rencontré quelques difficultés pour la programmer ; programmer avec Arduino, lancer le téléversement. Vous retrouverez un TUTO très détaillé de ces étapes dans "docs/files/micado_upgrade/TUTO ADAFRUIT 1501.pdf" du git.

A l'emplacement "/docs/files/micado_upgrade" se trouve aussi le code Arduino expliqué permettant de programmer la carte Adafruit sur des plages horaires précises. Ces horaires devant être rentrer par l'utilisateur.

Une fois ces horaires rentrer, l'utilsateur n'a qu'à activer l'alimentation du KOSMOS et le poser au fond. Le KOSMOS va ainsi filmer pendant une période définie par l'utilisateur aux mêmes heures pendant quelques jours. Cela permettra d'avoir une analyse plus étendue d'un même endroit.

## 3/ Notes et pistes d'évolution
 - Cette documentation est une relique et date de l'été 2021. Il constitue une réflexion de base pour construire le mode MICADO final. 
 - Noter que ce système permet d'économiser de l'énergie. En effet, la raspberry même en veille peu consommer 500mA. 
 - Le mode MICADO est déjà activé au software KOSMOS. Il doit démarrer le process immédiatement après démarrage. Pour passer en mode MICADO modifier le variable correspondante dans le fichier "kosmos_config.ini" se trouvant sur la clé usb.

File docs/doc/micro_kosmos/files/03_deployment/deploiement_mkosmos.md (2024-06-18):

icon:material/waves
# Déploiement de µKosmos
    
## 1- Démarage
- Vérifier le position du jumper (mode VR ou mode écran)
- Brancher et Allumer les batteries
- Appuyer sur l'intérupteur du boitier
- Allumer la manette de Xbox
- Appuyer sur le bouton central pour connecter la manette au gaming receiver

## 2- Fonctionnement de la manette de Xbox
#### Vidéo  

- **`Start`** : démarage de la caméra
- **`Back`**: Extinction de la caméra
- **`Guide`**: arrêt du script

#### Réglage AWB  

- **`A`** + :material-arrow-up-down: : Augmente ou diminue le canal rouge
- **`A`** + :octicons-arrow-both-16: : Augmente ou diminue le canal bleu
- **`RightBumper`** : Ajuste automatiquement les canaux rgb (red, green, blue)
- **`LeftBumper`** : Quitte l'auto ajustement
- **`RightTrigger`** : Retour aux gains de référence

#### Réglage de la luminosité et de la saturation 

-  **`X`** + :material-arrow-up-down: : Augmente ou diminue la luminosité
-  **`X`** + :octicons-arrow-both-16:  : Augmente ou diminue le contrast
- **`RightTrigger`** : Retour à luminosité et contraste de référence

#### Réglage compensation de l'exposition, affichage TpsPose, AnalogGain, DigitalGain 

- **`B`** + :material-arrow-up-down: : Augmente ou diminue l'exposition (attention ce n'est pas instantané)
- **`RightTrigger`** : Retour à la référence
- **`LeftTrigger`** : Capture une image
- **`LeftBumper`** : Analyse histo et ratio R/G et B/G (effectué sur la dernière image prise)

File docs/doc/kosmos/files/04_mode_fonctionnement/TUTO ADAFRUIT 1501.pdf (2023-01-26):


TUTO pour se servir de la ADAFRUIT TRINKET 5V :

1) Installer les drivers nécessaire :
- Télécharger l’exécutable d’installation : https://learn.adafruit.com/adafruit-arduino-ide-setup/windows-driver-installation
- Lancer l’exécutable :

Cliquez sur « I Agree ».

Cochez les deux drivers à installer comme ci-dessus.
Cliquez sur installez.
Les drivers sont installés !
Désormais on peut voir dans le « Gestionnaire des périphériques » notre Adafruit :


- Lancez ensuite l’IDE Arduino :
- Allez dans « Fichier > Préférence » :

Ajoutez dans « URL de gestionnaire de cartes supplémentaires » l’URL pour ajouter les cartes Adafruit : https://www.adafruit.com/package_adafruit_index.json
- Cliquez sur « OK »
- Sélectionnez la bonne carte :

- Sélectionnez le bon programmateur :


- Branchez la carte Adafruit au PC :

Lorsque vous téléversez le programme assurez vous que la LED rouge est bien en mode pulsation.

Pour ce faire il suffit d’appuyer sur le bouton poussoir juste avant de téléverser.

Vous pouvez faire un essais avec un programmes très simple pour faire clignoter la LED rouge toutes les 0.5 secondes :


int led = 1; // blink 'digital' pin 1 - AKA the built in red LED

// the setup routine runs once when you press reset:

void setup() {

// initialize the digital pin as an output.

pinMode(led, OUTPUT);

}

// the loop routine runs over and over again forever:

void loop() {

digitalWrite(led, HIGH);

delay(500);

digitalWrite(led, LOW);

delay(500);

}

Si cela fonctionne, votre carte est donc opérationnelle !

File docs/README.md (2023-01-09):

# KOSMOS 3.0

PhotoKOSMOS30

Le KOSMOS est un programme de sciences participatives née du partenariat atypique
entre une institution scientifique, l’Ifremer, et un Tiers Lieu, le Konk Ar Lab, Fablab de
Concarneau. Cette caméra d’observation de la faune et de la flore sous marine côtière a
permis de réunir autour d’un projet commun, acteurs de la recherche scientifique et de la
société civile.

La fabrication du KOSMOS au Konk Ar Lab est un formidable exemple d’intelligence
collective. Bénévoles et scientifiques collaborent main dans la main afin de concevoir cet
outil en s’assurant qu’il soit reproductible par tous, peu coûteux et scientifiquement
viable, c’est à dire répondant au protocole scientifique déjà en vigueur pour l’observation
et le suivi des écosystèmes côtiers.

Ce sont ces trois enjeux qui ont motivé Dominique Pelletier, directrice de recherche
Écologie et Modèles pour l’Halieutique (EMH), à se tourner vers le Konk Ar Lab. En effet,
Dominique a d’ores et déjà développé deux caméras utilisées à travers le monde : le
STAVIRO et le MICADO. Cependant, leur mode de fabrication est limitant et ne permet
pas à tout acteur (institution scientifique, parc naturel marin, citoyen) de s’emparer du
projet alors même que nos besoins d’évaluation et de suivis sont croissant. Le KOSMOS
offre donc une solution non négligeable a ce qui semblait être une impasse.

L’Ifremer s’est tourné vers le FabLab de Concarneau en sa qualité de lieu de facilitation
sociale par le numérique. Le Konk Ar Lab, implanté sur le territoire de Concarneau
Cornouailles Agglomération (CCA), est un lieu réunissant tout type de publics locaux
autour de projets numériques et techniques venus de divers horizons. Ce projet est donc
un moyen innovant de partager ses connaissances tant sur des aspects techniques,
mécaniques que biologiques ou écologiques.

Découvrir, partager, sensibiliser sont les thèmes centraux du projet KOSMOS. Un
programme de sciences participatives visant à réunir plaisanciers et scientifiques autour
de l’utilisation de la caméra en mer, verra le jour en 2023. L’objectif est de permettre à tout un chacun de collecter des vidéos lors de sorties en mer et de les analyser. En offrant ainsi de nouvelles données aux scientifiques, les observateurs développent ou approfondissent leur connaissances du milieu côtier et offrent la possibilité de suivre son évolution sur le long terme.

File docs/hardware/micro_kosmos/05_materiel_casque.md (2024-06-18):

# Materiel Casque

## Electronique:
| Visuel | Référence | Quantité | Dénomination | Usage |Substituabilité | Tips/Conseil |
|---:|---|---|---|---|---|---|
|batterie 5000 |[Urban Factory UPB05UF](https://www.fnac.com/Batterie-externe-Urban-Factory-UPB05UF-Juicee-Max-Powerbank-5000-mAh-Noir/a16416729/w-4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) | 1| Batterie 500mAh |Alimente l'écran du casque de VR |<blockquote> :green_circle: </blockquote><br> | |
|casque VR |[EAN 3002637644654](https://www.fnac.com/mp33894226/Casque-VR-pour-Smartphone-Realite-Virtuelle-Lunette-Jeux-Reglage-Universel/w-4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) | 1| Casque de réalité virtuelle |permet de visualiser les image de la caméra |<blockquote> :green_circle: </blockquote><br> |Vous pouvez utiliser un simple écran, mais avec le soleil dehors les écrans sont souvent illisibles. Le casque permet de voir correctement les images; |

## Cable:
| Visuel | Référence | Quantité | Dénomination | Usage |Substituabilité | Tips/Conseil |
|---:|---|---|---|---|---|---|
| cable_hdmi |[MIGRIP-HDMI-5](https://fr.farnell.com/clever-little-box/migrip-hdmi-5/cable-hdmi-male-male-verrouillage/dp/2373729) | 1|câble hdmi | Relie le casque au boitier électronique |<blockquote> :orange_circle: _connectique hdmi_</blockquote><br> | |
|usb_micro_usb  |[KUB06861-NR](https://www.kubii.com/fr/alimentations/1501-1088-mini-cable-blanc-usb-micro-usb-kubii-3272496003491.html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) | 1|câble micro usb - USB | Relie l'écran à la batterie |<blockquote> :orange_circle: _connectique usb et micro usb_</blockquote><br> | |

## Impresion 3D:
| Visuel | Référence | Quantité | Dénomination | Usage |Substituabilité | Tips/Conseil |
|---:|---|---|---|---|---|---|
|support_top_batterie |[support_top_batterie](../../hardware/micro_kosmos/3Dprint_files/casque/Support_batterie_BOT.stl)| 1| Support supérieur batterie |Partie haute de la boite dans laquelle la batterie sera maintenue |<blockquote> :red_circle: </blockquote><br> | |
|support_boy_batterie |[support_bot_batterie](../../hardware/micro_kosmos/3Dprint_files/casque/Support_batterie_TOP.stl)| 1| Support inférieur batterie |Partie basse de la boite dans laquelle la batterie sera maintenue |<blockquote> :red_circle: </blockquote><br> | |
|support_ecran |[support_ecran](../../hardware/micro_kosmos/3Dprint_files/casque/Support_ecran.stl)| 1|Support de l'écran |boite dans laquelle l'ecran sera maintenue |<blockquote> :red_circle: </blockquote><br> | |

## Visserie:
| Visuel | Référence | Quantité | Dénomination | Usage |Substituabilité | Tips/Conseil |
|---:|---|---|---|---|---|---|
| ecrou_m2 |RS PRO 248-4551 | 9|écrou M2 | | |
| vis_m2_4mm |[RS PRO 914-1624](https://fr.rs-online.com/web/p/vis-a-metaux/9141624) | 4|vis M2*4mm |Fixer l'ecran du casque à son support |<blockquote> :green_circle: </blockquote><br> | Récup  |
| vis_m2_6mm|[RS PRO 526-906](https://fr.rs-online.com/web/p/vis-a-metaux/0526906) | 5|vis M2*6mm |Fixer le boitier de la batterie au casque |<blockquote> :green_circle: </blockquote><br> | Récup |
|vis_m2_8mm|[RS PRO 914-1475](https://fr.rs-online.com/web/p/vis-a-metaux/9141475) | 4|vis M2*8mm |Fixer le couvercle du boitier de la batterie |<blockquote> :green_circle: </blockquote><br> | Récup |

## Consommable:
| Visuel | Référence | Quantité | Dénomination | Usage |Substituabilité | Tips/Conseil |
|---:|---|---|---|---|---|---|
|mousse_ruban |[RS-PRO 619-1786](https://fr.rs-online.com/web/p/rubans-mousse/6191786)| 1|Mousse ruban |Permet de maintenir certaines pièces et évite de les abimer |<blockquote> :green_circle: </blockquote><br> | |

(Les images proviennent des sites fournisseurs)

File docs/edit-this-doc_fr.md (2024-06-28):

icon:material/application-edit-outline
# Éditer cette documentation

## 1/ Introduction
|||
|-|-|
|Cette documentation est mise en page par ReadTheDocs.org et [lisible à l'adresse ci attaché](https://kosmos30.readthedocs.io). En aucun cas, cette adresse permet d'éditer la documentation.|ED1-1|
|Afin de pouvoir contribuer à cette documentation, vous pouvez contribuer directement au [repository GitHub](https://github.com/KonkArLab/KOSMOS).|ED1-2|

C'est sur GitHub que sont déposés les fichiers sources. On y retrouve l'arborescence suivante : 

 - **docs :** Est le dossier qui contient les documents qui pourront être affichés sur le read the doc. Dans ce dossier sont entreposés :

   - A la racine les fichiers marckdown qui sont les textes de la documentation. Pour chaque onglet sur read the doc nous ajouterons un fichier séparé avec un titre en Anglais sans espaces terminé par "_fr" pour la version française ou "_en" pour le version anglaise. L'extention sera toujours ".md".
   - Le dossier "pictures" : Qui contient plusieurs dossiers dont chacun porte un nom en rapport avec le fichier marckdown auquel il se rapporte. Ainsi pour un fichier de doccumentation "test1_fr.md" on prendra le soin d'entreposer les images dans un dossier "/docs/pictures/test1".

 - **Hardware :** Qui est le dossier qui contient les fichiers d'impressions 3D, de découpe laser...  

Avant de faire une proposition de contribution, il est bienvenue d'éditer le repository depuis votre compte en effectuant un forke de la présente documentation. Une fois que vous aurez une version prête à être publiée il suffira de faire une pull request au "main project" soit celui du konkarlab/KOSMOS.
C'est un administrateur KOSMOS qui étudiera votre proposition pour en intégrer tout ou partie sur le projet. 

## 2/ Édition (généralités)

### 2.1 Écriture en Marckdown
Le Marckdown est un langage de mise en forme de texte très simplifié. On peut éditer un fichier ".md" directement via gitHub ou en local de son ordinateur avec n'importe quel éditeur de texte. Cependant nous recommandons [Ghostwriter](https://wereturtle.github.io/ghostwriter/) qui présente l'avantage proposer une vue en direct du rendu (aperçu HTML).

[Pour ce qui est de la syntaxe, consulter ce guide](https://www.markdownguide.org/basic-syntax/)

### 2.2 Ajout et mise à jour d'une image

#### 2.2.1 Ajout
Les images que l'on souhaite faire apparaître dans la documentation ne doivent pas être collées dans le document. 

 - Créer un nouveau dossier du même nom que la documentation dans "/docs/pictures/" en créant un fichier vide que l'on suprimera par la suite.
 - Importer les images désirées que l'on aura préalablement réduites en taille chacune en dessous de 200Ko et renommées de manière à être facilement identifiables. 
 - On pourra par la suite supprimer le fichier vide qui nous aura servi à créer le dossier.
 - Dans le fichier de documentation corespondant à la ligne où l'on souhaite faire apparaître l'image, ajouter la ligne suivante : 
 ```Legende_Image``` 

#### 2.2.2 Mise à jour 
Pour mettre à jour une image, il suffit de supprimer du git l'image en question et d'uploader la nouvelle image en prenant soin de renommer cette nouvelle image avec le nom exact de l'ancienne. 

## 3/ Édition du dépôt en locale (Intermédiaire)
Cette méthode permet de cloner l'archive disponible sur github sur un disque dure. Ainsi on pourra facilement modifier les différents fichiers mais aussi l'arborescence sans nécéssiter de connexion internet mais surtout cela va permettre de préparer une version qui pourra par la suite faire l'objet d'un pull request. 
Toute la démarche décrite ci-dessous est valable uniquement pour un usage depuis un ordinateur sous Linux. Il existe nécéssairement des équvalent pour les autres OS mais que je nous ne connaissons pas).

### 2.1 Installer Git et préparer le terrain
 - Sur votre disque dure, définir l'espace où sera stocké le dépôt. Sachez qu'un dépôt GitHub peut peser jusq'à 500Mo. De préférence définir un dossier vide. **Attention* A ce qu'aucun dossier ou sous-dossier du chemin ne comporte de caractères spéciaux ou d'espaces. Remplacer tous les espaces par des underscore "_". 
 - Ouvrir un terminal ('Ctrl + Alt + t' sur Unbuntu).
 - Dans le cas où le paquet "git" n'est pas déjà installé sur votre PC, lancez l'installation de git :  ```sudo apt install git``` (Cette action nécessite une connexion internet).

### 2.2 Cloner le dépôt sur son disque dure
 - Ouvrir une page web avec le git que l'on souhaite cloner
 - Y copier le code "https" que l'on trouvera dans l'onglet déroulant "code" en haut à droite. Pas besoin de le chercher pour le repository KOSMOS, le lien est : https://github.com/KonkArLab/KOSMOS.git
 - Dans un terminal se diriger vers l'espace prévu pour coller le dépôt. Utiliser la commande ```cd puis_chemin/de_votre_dossier```
 - Cloner le dépôt git en utilisant la commande ```git clone https://github.com/KonkArLab/KOSMOS.git``` Prendre soin de remplacer l'url par celui du dépôt désiré si il est différent du notre. 
 - Le clonage va prendre quelques minutes et va coller tous les fichiers et l'arborescence dans votre répertoire.

### 2.3 Modifier le dépôt
 - Sur votre poste de travail, modifiez tous les fichiers nécessaires, déposer des fichiers, suprimez en...
 - Avant de commencer à travailler peut-être que le dépôt en ligne a été modifié depuis votre dernière mise à jour. Pour mettre à jour votre dépôt en local. Se positionner tout d'abord dans le dépôt ```cd NomduDepot``` Puis effectuer un "Pull" ```git pull```
 
### 2.4 Proposer des modifications
Si vous avez effectué des modifications, il peut-être utile de les proposer en modification au projet. Mais avant cela il peut-être utile de créer une nouvelle branche ou de faire cela depuis votre fork. 
 - Pour ajouter l'ensemble des fichiers à la liste des fichiers à commiter : ```git add *```
 - Commiter ```git commit -m "commentaire associé au commit" git@git.cru.fr:nom_projet.git nom_branche (par défaut master représentant la branche principale)```
 - Enfin pousser votre travail ```git push```

## Liens connexes
 - [Documentation Git](https://git-scm.com/about)
 - [Formation vidéo à Git](https://youtube.com/playlist?list=PLjwdMgw5TTLXuY5i7RW0QqGdW0NZntqiP)

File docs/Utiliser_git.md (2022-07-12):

## Formation Git 

### Initier un git

 - git init est une commande qui permet d'initier un git
 - A la base le dépôt est vide
 - Écrire des choses dans un fichier. (Modifier ce qui est dans le dossier de GIT)
 - git add permet d'indiquer une modification de sauvegarde. "Maintenant j'observe les fichiers à observer"

### Sauvegarder le Git
 - git commit : sauvegarder les modifications apportées. "Va aller dans les fichiers à observer et va enregistrer les modifications qui ont été faites"
 - Sauvegarder une version (git tag). Nomme un nom de commit en nom de version

### Travail en parallèle

 - git branch, sauvegarder plusieurs modifications à partir d'une version. 
 - git checkout pour changer de branche (ajouter argument branche ou master).
 - git merge : remettre le contenu d'une branche se remet dans la branche principale. La branche continue à exister 
 - On ne fait pas de commit sur la branche master (en général en informatique)
 - Chaque contributeur travail indépendamment sur une branche
 - le merge fait comme un commit (ce qui fait qu'il peut demander de résoudre des conflits)
 - Ce qui veut dire qu'il faut tout de même se coordonner et ne pas travailler sur le même fichier. 

### Préparer un répertoire en ligne

 - git remote configurer une destination à distance (remote) pour le git
 - git push envoie la version actuelle vers le répertoire distant. On peut faire cela par branche (se positionner (checkout) et pousser juste une branche)
 - git pull tirer ce qui est en ligne (mais il faut déjà un git en local)
 - git clone pour copier un répertoire sur un git en ligne
 
`

### Setup
 - git config --global user?name "[firstname lastname]"

### Liens connexes
 - les commandes de git : https://education.github.com/git-cheat-sheet-education.pdf

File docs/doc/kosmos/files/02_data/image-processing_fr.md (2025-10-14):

icon:material/image-sync
# Traitement des vidéos issues du système KOSMOS image kosmos

Le but de cet algorithme est d'améliorer les vidéos sous-marines en traitant la turbidité et en corrigeant les couleurs (en python) 

## I/ Prérequis 

Python : 
  Librairies: 
    - OpenCV
    - Numpy
    - Math
    - moviepy
    - Pathlib
    - Imageio 
    - OS
    - multiprocessing & concurrent.futures
    
 Pour installer les librairies, tapez dans la console spyder : pip install *nom de la librairie*
 
 Les besoins en ressources requis (à préciser)
 
## II/ Lancer l'algorithme 

L'arborescence de fichier doit se présenter comme celui-ci : 

Avec les vidéos à traiter dans le dossier "Videos" et les vidéos traitées dans le dossier "Videos traitées". Le dossier "Frames" contiendra toutes les images
des videos et ces images seront traitées directement dans ce dossier. ⚠️ Pensez à vérifier que les chemins des différents dossiers, présents dans le code, sont exacts.

- Processing.py : contient le code qui va traiter une vidéo/image avec les méthodes d’égalisation d’histogramme, de débrumage et le rétinex.

Dans le fichier python il y a une partie pour modifier certains paramètres (ligne 335): 

``` 
### PARAMETRES A RENSEIGNER ### 
filename_video = './Vidéos/kosmos_2022-07-19-19-09-16.mp4'

db_min = 13
db_s =44

fin_min = 13
fin_s= 54

method = "HE"

filename_video_a_traiter = "./Vidéos/video.mp4"
###############################
```
C'est ici que l'on rentre la durée (db_min, db_s, fin_min, fin_s) de la vidéo que l'on souhaite traiter avec un temps de début et de fin. 
Il est également possible de ne traiter qu'une frame en définissant fin_min et fin_s à 0. 

La variable "method" va indiquer quelle méthode de traitement on souhaite utiliser, il est possible de rentrer soit "HE" ou  "retinex" ou "UDCP".

## III/ Exemples d'une image traitée avec les deux méthodes

Image originale: 

 

Image traitée avec HE et le débrumage : 

 

Image traitée avec le rétinex : 

 

## Sources : Algorithmes/articles utilisés :
- Single Image Haze Removal Using Dark Channel Prior, Kaiming He, Jian Sun, and Xiaoou Tang", in CVPR 2009 
- Guided Image Filtering, Kaiming He, Jian Sun, and Xiaoou Tang", in ECCV 2010.
- Properties and Performance of a Center/Surround Retinex, Daniel J. Jobson, Zia-ur Rahman, 1997 
- A Retinex-Based Enhancing Approach for Single Underwater Image, Xueyang Fu, Peixian Zhuang, Yue Huang, Yinghao Liao, Xiao-Ping Zhang, Xinghao Ding, 2014 

## Auteur 

***Zoë DAHERON*** - *stage technique* - IFREMER

Permission is hereby granted, free of charge, to any person obtaining a copy of this software and associated documentation files (the "Software"), to deal in the Software without restriction, including without limitation the rights to use, copy, modify, merge, publish, distribute, sub license, and/or sell copies of the Software, and to permit persons to whom the Software is furnished to do so.

THE SOFTWARE IS PROVIDED "AS IS", WITHOUT WARRANTY OF ANY KIND, EXPRESS OR IMPLIED, INCLUDING BUT NOT LIMITED TO THE WARRANTIES OF MERCHANTABILITY, FITNESS FOR A PARTICULAR PURPOSE AND NON INFRINGEMENT. IN NO EVENT SHALL THE AUTHORS OR COPYRIGHT HOLDERS BE LIABLE FOR ANY CLAIM, DAMAGES OR OTHER LIABILITY, WHETHER IN AN ACTION OF CONTRACT, TORT OR OTHERWISE, ARISING FROM, OUT OF OR IN CONNECTION WITH THE SOFTWARE OR THE USE OR OTHER DEALINGS IN THE SOFTWARE.

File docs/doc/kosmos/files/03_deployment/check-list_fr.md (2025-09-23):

icon:fontawesome/solid/list-check

# Check-list PRÉPARATION

| **À faire** | **OK** |
|---|:--:|
| Recharger la batterie de la KOSMOS | |
| Vider la clé USB et l'initialiser avec les fichiers de config | |
| Vérifier la propreté du hublot de la caméra | |
| Vérifier que les deux joints des côtés ne sortent pas de leurs gorges et sont en contact continu avec la paroi du caisson | |
| Fermer le caisson caméra | |
| Faire un test d’étanchéité avec la pompe à vide | |
| Visser le bouchon d'étanchéité Vent | |
| Faire un test vidéo et de rotation | |
| Préparer les points d’échantillonnage et leurs points GPS | |

# Check-list MATÉRIEL

| **À prendre** | **Quantité** | **OK** |
|:---|:---:|:--:|
| Caméra KOSMOS montée sur son pied | x1 | |
| Bouchon d'étanchéité Vent | x1 | |
| Aimants de démarrage | x1 | |
| Plombs de plongée 1kg | x6 | |
| Mousquetons pour attacher les plombs | x6 | |
| Ligne de bout 5m ou 10m + petit flotteur à casier + bouée | x1 | |
| Lunette de calfat | x1 | |
| Gaffe | x1 | |
| Profondimètre de plongée ? | x1 | |
| Clé plate de 13 | x2 | |
| Serviettes & tissus microfibre pour essuyer et protéger les systèmes du soleil, et pour s’essuyer les mains | x1 | |
| Ardoise, feutre véléda, sopalin ou chiffon | x1 | |
| Cartes, feuilles de terrain vierge, feuilles terrain des jours précédents, plaque pour accrocher les feuilles, crayon, gomme, taille-crayon | x1 | |
| Bouteilles d’eau douce pour rinçage des systèmes  | x3 | |
| Si besoin, GPS avec ses 2 piles de rechange | x1 | |
| Crème solaire, chapeau, eau à boire, lunettes de soleil, appareil photos... | x1 | |

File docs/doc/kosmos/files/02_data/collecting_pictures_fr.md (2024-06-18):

icon:material/video-vintage
## 1/ Extraire les vidéos du KOSMOS. 

Toutes les données du KOSMOS sont stockés sur l'unique clé USB cnnecté à la Raspberry pi. On prendra soint de n'extraire cette clé que lorsque le KOSMOS est hors tension. A défaut cela pourait entrainer des problèmes de montage de la clé sur la raspberry et par conséquent entrainer une perte de données.

 - Pour accéder à la clés USB, ouvrir la flange côté cablage en dévissant le bouchon vent (appel d'air).
 - Extraire la clés USB puis l'insérer dans un ordinateur.
 - Se diriger dans le dossier vidéos de la clés USB. Copier tous les fichiers qui y sont stockés. Les archiver dans un dossier locale au choix.
 - Ces fichiers en ".h264" doivent rester Archivés dans un dossier différent de celui que l'on utilisera pour la manipulation. Attention les manipulations suivantes si elles conduisent à une erreur peuvent entrainer la perte de données. 
 - Une fois les données sauvés on pourra suprimer celles présentent dans la clés USB pour libérer le stokage du KOSMOS et ainsi éviter de mauvaises surprises au retour de campagnes en mer. 

## 2/ Transformation des viéos au format MP4
le format h264 des vidéos est exploitable, mais présente la difficulté de ne pas être borné ce qui rend difficile d'avancer la vidéos ou de revenir en arrière. Il est également impossible avec ce format de noter des times codes. Pour faciliter la lecture des nos vidéos nous allons donc les convertir en MP4. 
Pour y parvenir on utilisera une simple invit de commande linux. 
 - Ouvrir un terminal de commandes,
 - Se diriger dans le dossier où se trouvent les vidéos que l'on souhaite transformer en utilisant par exemple la commande : <pre>cd /Chemin/du/dossier</pre>
 - Utiliser la commande suivantes pour chaque fichier en remplaçant "input" et "output" par le nom du fichier en question. Veiller à bien conserver cependant les bonnes extentions à savoir ".h264" poyur l'input et ".mp4" pour l'output : <pre>ffmpeg -framerate 24 -i input.h264 -c copy output.mp4</pre>
 - Pour éviter de mélanger dans le même dossier les h264 et mp4 on pourra aussi créer un dossier différent pour l'entrée et la sortie. Dans ce cas spécifier le chemin directement à la commande ffmpeg vue ci-dessus. 

## Liens connexes
 - [Forum d'où vien la ligne de commande capable de faire la transformation H264 en MP4](https://askubuntu.com/questions/690015/how-can-i-convert-264-file-to-mp4)

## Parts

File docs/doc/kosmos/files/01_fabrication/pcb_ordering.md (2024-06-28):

icon:material/hand-coin
# Faire fabriquer un PCB

## 1/ A partir de notre archive (facile) 

 - [Télécharger l'archive des fichiers gerbers et de perçages](https://github.com/KonkArLab/KOSMOS/blob/main/hardware/electronics/kosmos_V4_PCB.zip)
 - Conserver cette archive sous format .zip
 - [Se rendre sur le site de euro circuit](https://www.eurocircuits.com/)
 - Se créer un compte sur le site d'euro circuit
 - Sur la page d'accueil, cliquer sur "Drop PCB Data Here"
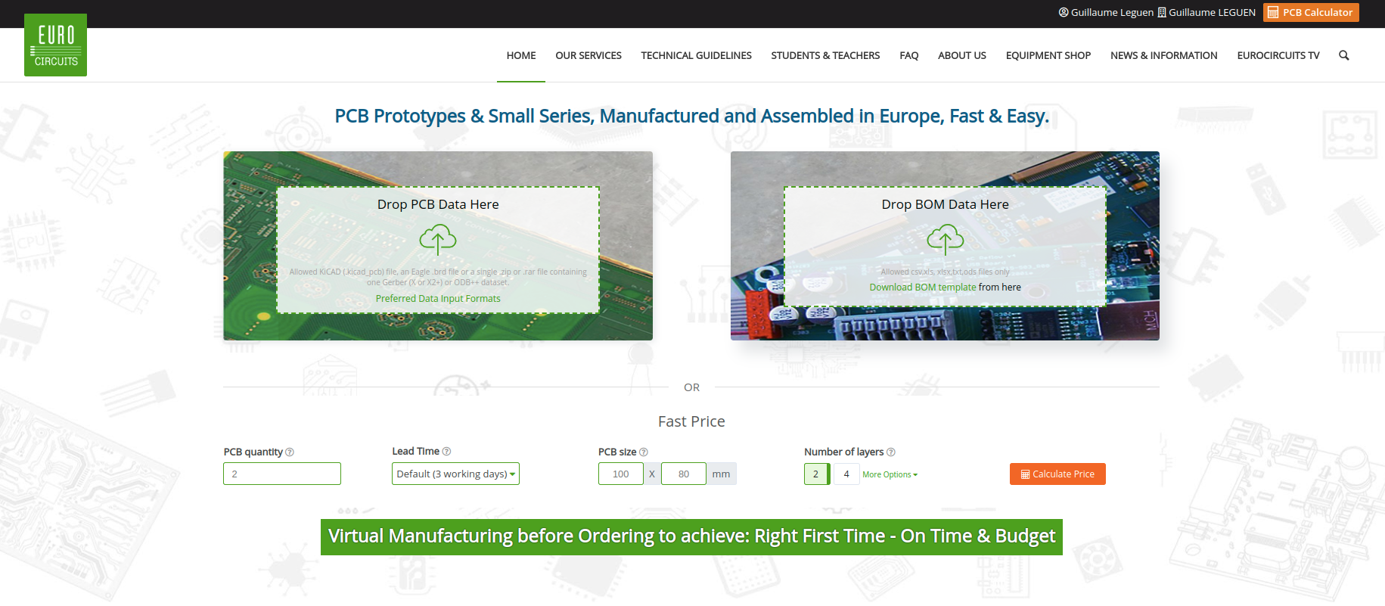
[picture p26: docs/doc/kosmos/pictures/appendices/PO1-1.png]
PO1-1


 - Une fenêtre d'exploration s'ouvre, sélectionner l'archive précédemment téléchargée. 
 - Passer les étapes d'assemblage. En effet, nous allons commander un PCB seul sans les composants soudés. 
 - Sélectionner "Basic analyse".
 - Puis entrer le nombre de PCB à commander. Il est recommandé d'en commander 10 minimum. En dessous le prix ne sera pas avantageux. 
 - Si tout s'est bien passé, le PCB devrait apparaître. Sous l'aperçu du PCB, vous pouvez lire si l'analyse basique a fonctionné. 
 - Les paramètres qui suivent sont renseignés automatiquement par la lecture des fichiers gerbers. Il est recommandé de ne pas modifier ces paramètres. Il est possible de changer la couleur du PCB dans l'onglet "Définition CI".
 - Sur la droite, on peut lire la coût de fabrication d'une unité ainsi que le coût total du projet. 
 - Cliquer sur le bouton orange (au sommet de la colonne de droite) "proceed to sommaire".
 - Une analyse plus posée va s'effectuer. Ceci prend généralement moins d'un quart d'heure.
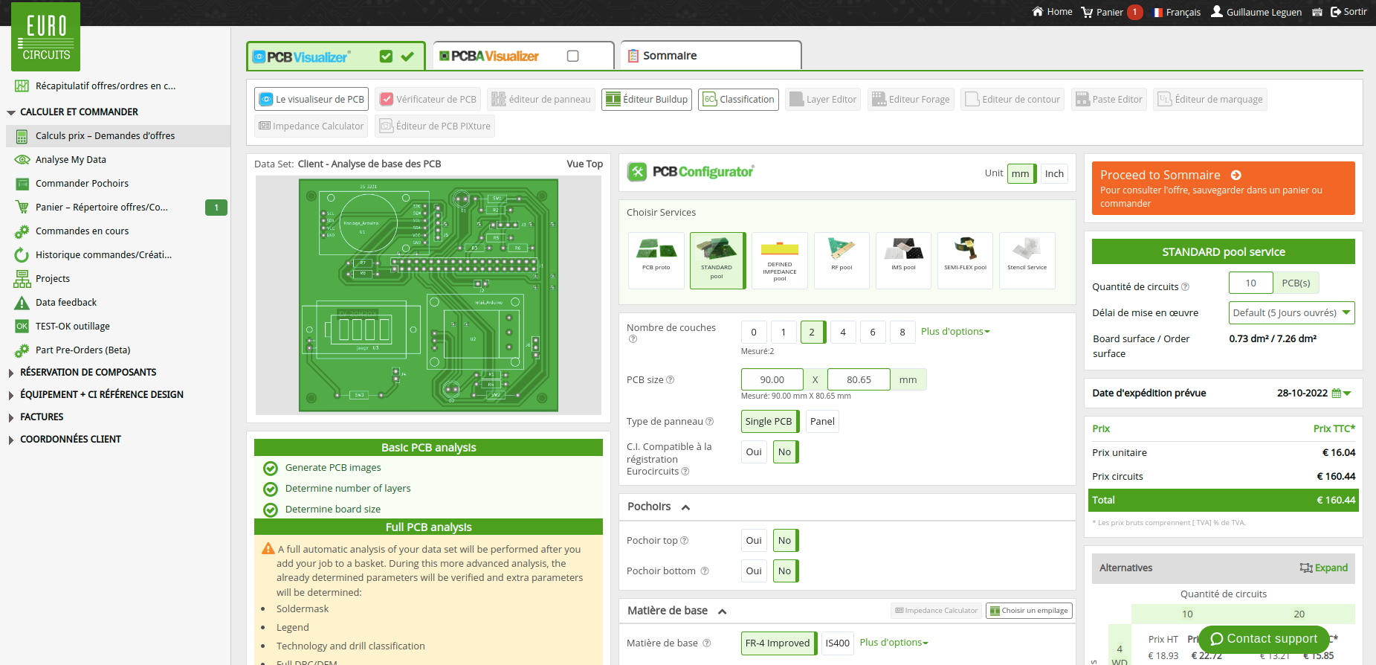
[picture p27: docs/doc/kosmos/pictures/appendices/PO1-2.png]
PO1-2


 - Si l'analyse est validée, procéder à la commande. 

**note :**
 - [Le site de nextPCB](https://www.nextpcb.com/) propose des fabrications gratuites de prototypes à hauteur de 10 exemplaires maximum par commande.

## 2/ Ou à partir des fichiers PCB (Expert)
Cette étape sera utile si vous avez besoin de modifier quelque-chose dans le tracé du PCB pour l'adapter. 

 - Télécharger les fichiers ".kicad_pcb" ".kicad_pro" et ".kicad_sch" présents depuis la racine du dépôt git en suivant le chemin suivant : /hardware/electronics/ .
 - Ouvrir ces fichiers au moyen du [logiciel kicad](https://www.kicad.org/).
 - Effectuer les modifications nécessaires. 
 - Générer les fichiers gerber (fichier ; Tracer), sélectionner les couches utiles. Cocher la vérification des plans de masses et "Utiliser extensions Gerber Protel". Diriger cet export dans un dossier de préférence vide.
 - Cliquer sur "Tracer". Le logiciel va créer plusieurs fichiers. 
 - Ne pas oublier depuis la même fenêtre de générer les fichiers de perçage en cliquant sur le bouton "Créer Fichiers de Perçages...".
 - Enfin compresser en .zip le dossier contenant les fichiers gerbers et le fichier de perçage. 
 - Le dossier ainsi compressé pourra être déposé sur euro cricuit ou next PCB (cf. chapitre précédent)

## Liens connexes 

 - Tutoriel YouTube pour exporter les fichiers gerber : https://youtu.be/I6-BzFYGuvg

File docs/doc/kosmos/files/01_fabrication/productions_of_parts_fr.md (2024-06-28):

icon:material/cube
## 1/ Impression des pièces en 3D

Imprimer toutes les pièces nécessaires en veillant à respecter les recommandations de remplissage des pièces extérieurs (cf. chapitre 1.2). [Les fichiers STL sont disponibles ici](https://github.com/KonkArLab/KOSMOS/tree/main/hardware/3Dprint_files/) .

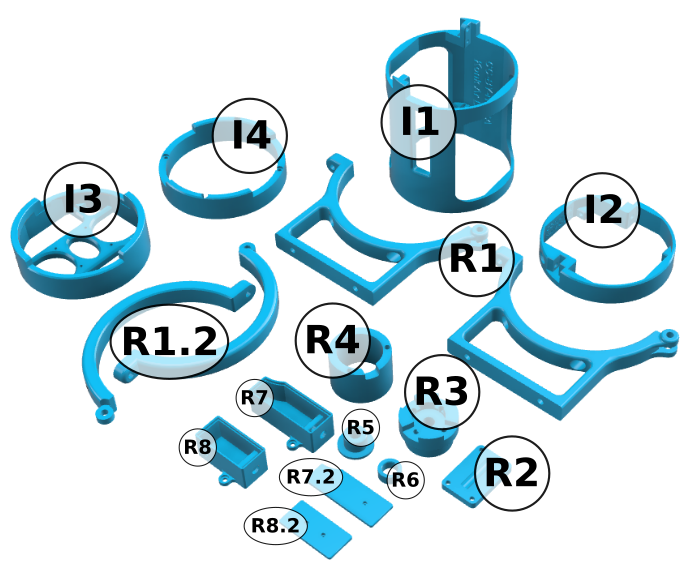
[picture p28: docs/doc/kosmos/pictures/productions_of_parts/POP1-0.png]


**1.1 Pour l'intérieur du caisson :**

Il n'y a pas d'obligation quand au matériau d'impression de ces pièces. Le PET est le matériau que nous avons utilisé du fait qu’il est très facilement accessible dans le commerce. Le PLA parait à écarter tant parfois il arrive au KOSMOS d'être stocké au soleil. La température si elle atteint 60° pourrait déformer des pièces en PLA. 

Le remplissage pourra être alvéolé de manière à économiser de la matière. Nous utilisons régulièrement un remplissage à 20% et une résolution de 0,2mm.

| Visuel |Référence|Quantité|Dénomination|Usage|Conseils d'impression|
|---|---|---|---|---|---|
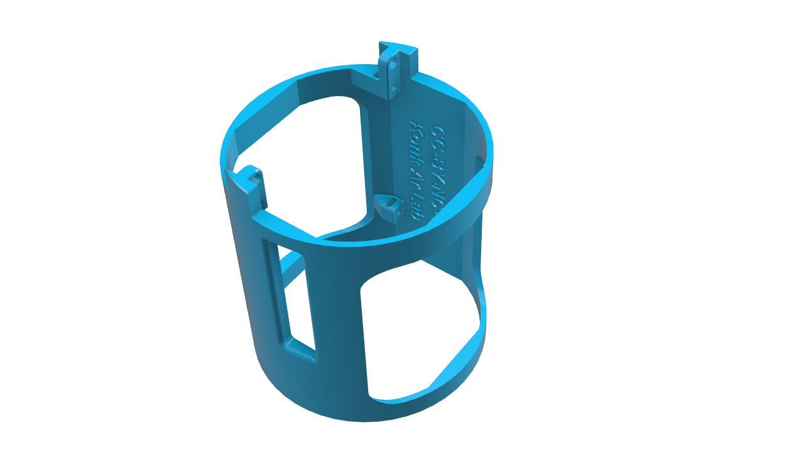
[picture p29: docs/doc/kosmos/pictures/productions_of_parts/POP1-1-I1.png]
POP1-1-I1
||[I1](https://github.com/KonkArLab/KOSMOS/tree/main/hardware/3Dprint_files/I1_KOSMOS_V3-0.stl)|1|Section de la raspberry|Cette pièce est la section qui s'insérera dans le tube étanche, c'est le support de la carte raspberry et de divers autres composants.|Positionner des générateurs de supports pour supporter la partie en porte à faux|
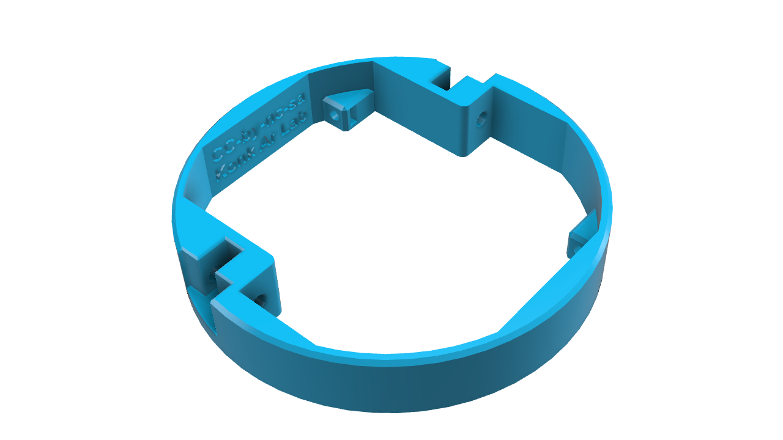
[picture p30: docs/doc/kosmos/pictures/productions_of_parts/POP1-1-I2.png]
POP1-1-I2
||[I2](https://github.com/KonkArLab/KOSMOS/tree/main/hardware/3Dprint_files/I2_KOSMOS_V3-0.stl)|1|Section batterie|I2 est la section qui va faire le lien entre la structure Raspberry et la plaque sur laquelle va se positionner les batteries|/|
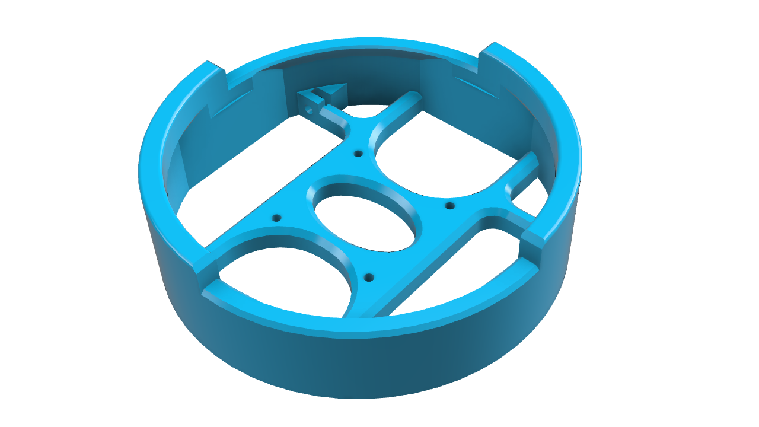
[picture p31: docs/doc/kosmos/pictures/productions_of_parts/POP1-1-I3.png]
POP1-1-I3
||[I3](https://github.com/KonkArLab/KOSMOS/tree/main/hardware/3Dprint_files/I3_KOSMOS_V3-0.stl)|1|Section de support de la caméra|Cette section s'insère dans le tube et vient admettre la caméra qui pour s'y visser|/|
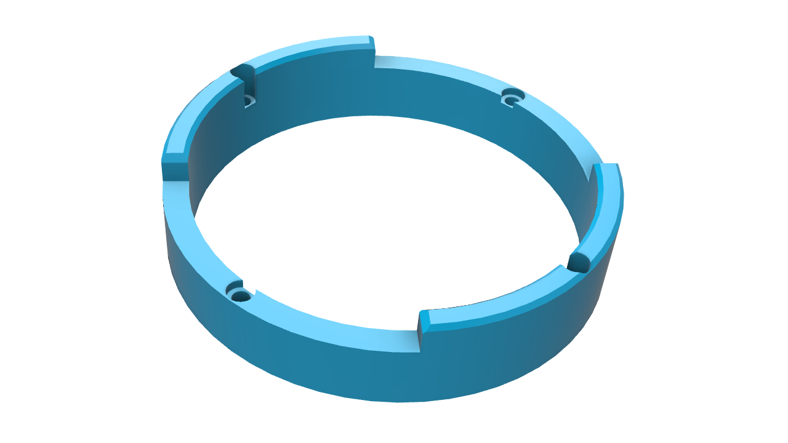
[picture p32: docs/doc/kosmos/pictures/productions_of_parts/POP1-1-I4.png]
POP1-1-I4
||[I4](https://github.com/KonkArLab/KOSMOS/tree/main/hardware/3Dprint_files/I4_KOSMOS_V3-0.stl)|1|Détrompeur|Fixé à la flange du hublot, il permettra de contraindre les structures internes en rotation et d'éviter que le KOSMOS ne puisse filmer de travers.|/|

**1.2 Pour l'extérieur du caisson :**

Toutes ces pièces doivent êtres impérativement imprimés en PET. En effet, cette matière est la plus résistante à l'eau de mer parmi les matériaux disponibles en impression 3D FDM. Si vous disposez d'autres technologies, ne pas hésiter à essayer et nous faire part du résultat. Cependant, nous savons que la résine par SLA ne convient pas pour une raison de dureté. Il peut-être intéressant également de travailler à un réducteur sans impression 3D à la fraiseuse uniquement pour rendre la plongée possible à de plus grandes profondeurs.

Nous recommandons un taux de remplissage des pièces qui ne soit pas inférieur à 30%. Toutes nos pièces destinées à l'extérieur du caisson ont un taux de remplissage à 100%.

| Visuel |Référence|Quantité|Dénomination|Usage|Conseils d'impression|
|---|---|---|---|---|---|
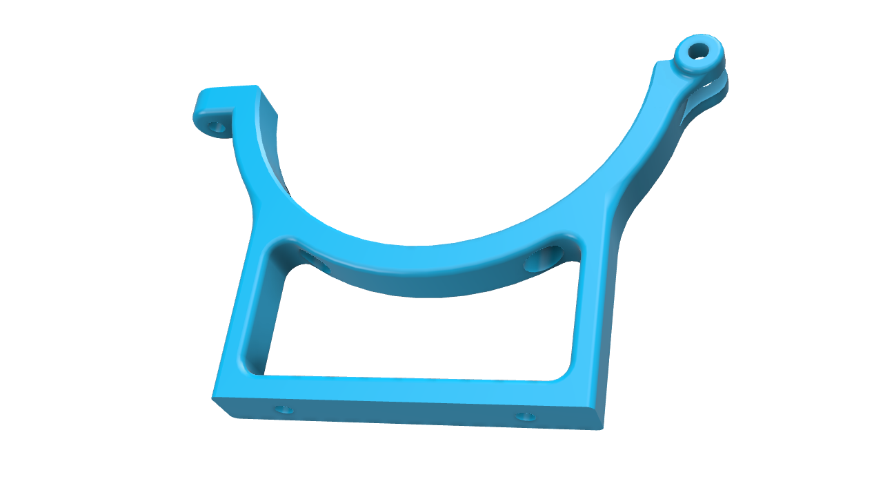
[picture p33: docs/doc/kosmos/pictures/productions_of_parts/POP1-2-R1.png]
POP1-2-R1
||[R1](https://github.com/KonkArLab/KOSMOS/tree/main/hardware/3Dprint_files/R1_KOSMOS_V3-0.stl)|2|Ber|Supporte le tube étanche. Il permet avec R1.2 de soutenir le tube|Positionner un générateur de support pour supporter la partie en porte à faux|
|POP1-2-R1-2|[R1.2](https://github.com/KonkArLab/KOSMOS/blob/main/hardware/3Dprint_files/R1-2_KOSMOS_V3-0.stl)|2|Fermeture du Ber|Levier pouvant se refermer sur R1 pour bloquer le tube étanche au moyen de vis.|Positionner un générateur de support pour supporter la partie en porte à faux|
|POP1-2-R2|[R2](https://github.com/KonkArLab/KOSMOS/tree/main/hardware/3Dprint_files/R2_KOSMOS_V3-0.stl)|1|Support du capteur de positionnement|Réceptacle du capteur de positionnement|/|
|POP1-2-R3|[R3](https://github.com/KonkArLab/KOSMOS/tree/main/hardware/3Dprint_files/R3_KOSMOS_V3-0.stl)|1|Embout de croix de Malte|Cette pièce reprend l'effort de la croix de Malte pour la retransmettre à l'arbre qui lui est solidaire au trèpied et donc au sol|Utiliser du support pour maintenir la périphérie en porte à faux ainsi que les alésages.|
|POP1-2-R4|[R4](https://github.com/KonkArLab/KOSMOS/tree/main/hardware/3Dprint_files/R4_KOSMOS_V3-0.stl)|1|Entretoise du moteur|Le moteur sera positionné dans ce tube. La hauteur de ce dernier peut-être à modifier pour faire coïncider parfaitement l'alignement du pignon moteur et du premier pignon méné.|/|
|POP1-2-R5|[R5](https://github.com/KonkArLab/KOSMOS/tree/main/hardware/3Dprint_files/R5_KOSMOS_V3-0.stl)|1|Bague d'arbre secondaire|R5 permet l'assemblage de l'arbre secondaire (contenant la croix de Malte) avec la boite du réducteur. Elle reprend le serrage de la croix de Malte sans contraindre le reste des pignons|/|
|POP1-2-R6|[R6](https://github.com/KonkArLab/KOSMOS/tree/main/hardware/3Dprint_files/R6_KOSMOS_V3-0.stl)|1|Entretoise d'abre primaire|Cette rondelle permet de contraindre les pignons de l'arbre primaire en translation. Sa hauteur doit être ajustée pour ne pas en empécher la rotation libre.|/|
|POP1-2-R7|[R7](https://github.com/KonkArLab/KOSMOS/tree/main/hardware/3Dprint_files/R7_KOSMOS_V3-0.stl)|1|Raccord de connectiques étanches du moteur|R7 est l'emplacement où l'on va connecter les câbles du moteur au câble noir cobalt. L'étanchéité sera effectuée en coulant de la résine dans le contenant.|/|
|POP1-2-R7-2|[R7.2](https://github.com/KonkArLab/KOSMOS/tree/main/hardware/3Dprint_files/R7-2_KOSMOS_V3-0.stl)|1|Couvercle pour le raccord de connectiques étanches du moteur|Permet de fermer R7|/|
|POP1-2-R8|[R8](https://github.com/KonkArLab/KOSMOS/tree/main/hardware/3Dprint_files/R8_KOSMOS_V3-0.stl)|1|Raccord de connectiques étanches du capteur de positionnement|R8 est l'emplacement où l'on va connecter les câbles du capteur ILS au câble noir cobalt. L'étanchéité sera effectuée en coulant de la résine dans le contenant.|/|
|POP1-2-R8-2|[R8.2](https://github.com/KonkArLab/KOSMOS/tree/main/hardware/3Dprint_files/R8-2_KOSMOS_V3-0.stl)|1|Couvercle pour le raccord de connectiques étanches du capteur de positionnement|Permet de fermer R8|/|

_Note  : Toutes les pièces devront être nettoyées de leurs supports et au cours du montage, elles nécessiteront peut-être d'être limées \(papier de verre ou lime à main\) afin de supprimer toutes traces de fils d'anges._

## 2/ Découpe des pièces planes au laser

Le KOSMOS est composé en plus de pièces imprimées en 3D et de visserie Inox de pièces à découper au laser dans des plaques de PMMA et de POM. Ainsi on peut immerger ces pièces dans l'eau sans craindre la pression. Les pièces de l'intérieur du caisson peuvent être aussi imprimées en 3D.  [Les trois fichiers vectoriels évoqués ci-dessous sont disponibles ici. ](https://github.com/KonkArLab/KOSMOS/tree/main/hardware/Laser_cut/)

**2.1 Pour l'intérieur du caisson :**

* [Télécharger le fichier de découpe](https://github.com/KonkArLab/KOSMOS/tree/main/hardware/Laser_cut/PMMA-5mm_A5_laser-cut.svg )
* Découper les pièces S1 S2 dans du PMMA de 5mm d'épaisseur \(prévoir l'équivalent de la surface d'une feuille A5\) ;

POP2-1

**2.2 Pour l'extérieur du caisson :**

Ces pièces constituent l'enveloppe du réducteur du KOSMOS. On peut les réaliser en PMMA 5mm si on veut voir à travers ou un autre plastique de 5mm comme des plaques de plastique recyclé.

* Il est nécéssaire de sélectionner une plaque de PMMA bien plane de 5mm d'épaisseur \(prévoir l'équivalent de la surface d'une feuille A3\) ;
* [Télécharger le fichier de découpes](https://github.com/KonkArLab/KOSMOS/tree/main/hardware/Laser_cut/PMMA-5mm_A3_Laser-cut.svg) pour lancer une découpe au laser ou à la fraiseuse numérique ;
* Toutes les pièces sont disposées ici de manière à rentrer dans un format A3 \(42\*29,7 cm\).

POP2-2

**2.3 Les pièces en mouvements \(engrenages...\) seront usinés de préférence en POM.**

Ces pièces sont les plus délicates à produire. Il est nécessaire de de s'armer de patience pour réaliser le plus proprement possible ces engrrnages à la fraiseuse à commande numérique dans un matériau comme le POM. Nous avons également fait l'essai avec du PMMA translucide. Ce dernier matériau à l'avantage de pouvoir s'usiner au laser. Ce qui n'est pas la cas du POM.

/!\ ATTENTION : Le POM ne peut être découpé au laser si cette dernière n'est équipé d'une hotte aspirante. Le gaz produit par le POM au passage d'un laser n'est autre que du formaldéhyde (formol). 

* Pour réaliser les découpes au laser, utiliser le fichier présent dans cette archive (hardware/laser_cut/A4_laser-cut.svg). 
* Pour usiner le POM ou un autre matrériau à la fraiseus numérique, utiliser le projet easel présent sur la plateforme inventables : https://www.inventables.com/projects/kosmos_gears

**Recommandatons**
* Il est nécessaire de sélectionner une plaque de POM bien plane de 5mm d'épaisseur ;
* Toutes les pièces sont disposées ici de manière à rentrer dans un format A4 \(21\*29,7 cm\) dans le fichier easel les pièces dépassent légérement de ce format ;
* Utiliser une fraise de 2mm à 2 dents adapté au plastique PP et POM ;
* Paramétrez les vitesses de progressions aux besoins de votre machine ;

POP2-3

## 3/ Fabrication du PCB
### 3.1 Stratégie pour le circuit

La fabrication du KOSMOS 3.0 requiert un circuit imprimé (ou PCB). Ce dernier permettra de relier à la carte raspberry les composants et capteurs utiles au fonctionnement. On y retrouvera notamment :
 - Des résistances pour les LED mais aussi pour l'I2C,
 - Les ILS,
 - Un voyant de niveau de batterie,
 - Une horloge (RTC) permettant de mettre la raspberry à l'heure à chaque démarrage,
 - Une série de connectiques qui permettront de se connecter aux alimentations mais aussi de raccorder les différents services. 

**Il existe trois possibilités pour obtenir le PCB (Le détail pour les deux premières méthodes sont disponibles dans les annexes):**

| **Méthode** | **Avantages** | **Inconvénients** | **coût totale** |
|---|---|---|---|
| **Fabrication maison** |  - Fabrication d'un seul PCB  - Droit à l'erreur  - Peu coûteux |  - Processus long  - Nombreuses erreurs possibles  - Nécessite du matériel spécifique |  - 10 à 30 € |
| **Commande à un prestataire spécialisé** |  - Qualité maximale  - Economie de temps à la fabrication et au perçage |  - Obligation de commande groupée (5 ou 10 min)  - Pas de droit à l'erreur |  - Environ 150 à 200€ pour une dizaine de circuits |
| **Commande au Konk Ar Lab** |  - Le circuit est issu d'une série testée et validée par l'équipe KOSMOS  |  - Pas de disponibilité certaine |  - Environ 20€ par circuit |

### 3.2 Soudure des composants
 - Souder deux résistances 100ohm sur R1 et R2
 - Souder 6 résistances de 1kohm sur R3,R4,R5,R6,R7,R8
 
POP3-1

 - Utiliser les chutes de pattes de résistances pour fabriquer les six ponts de masses.

POP3-2

 - Souder une LED Rouge sur D1 et une LED verte su D2. Attention à la polarité que l'on peut retrouver avec la forme de la LED.

 - Souder trois ils sur SW1, SW2 et SW3 ;

POP3-3

 - Souder le relai, le témoin de charge et le RTC aux emplacements prédéfinis ; 

POP3-4

 - Souder 40 broches dupponts ;

POP3-5
 
 - Souder deux connecteurs JST Male 2 broches sur J2 et J4 en veillant à respecter le sens visible sur les photos ci dessous. 
 - Souder un connecteur JST Male 4 broches  sur J3
 - Souder un connecteur JST Male 5 broches  sur J5

POP3-6

 - Souder une broches de 3 pins dupont coudés sur J6
 
POP3-7

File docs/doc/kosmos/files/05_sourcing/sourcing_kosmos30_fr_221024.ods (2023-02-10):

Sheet: NT_Aladecoupe
 | Note de traçabilité
 | Qui | Quand
Etabli |  | 09/02/23
Approuvé
1/ Objet de la demande
Nom du projet : | KOSMOS
Détail de la demande : | Fabrication de KOSMOS
Nombre de système fabriqué : | 4
2/ Demande
Fournisseur | - multiple -
Désignation | Reste à commander | Somme - Prix commande
Frais de ports | 1 | 16,58 €
Plaque de PMMA incolore 5mm 450* 350mm | 0 | 0,00 €
(vide) | (vide)
Total Résultat |  | 16,58 €

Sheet: NT_Acieraudetail
 | Note de traçabilité
 | Qui | Quand
Etabli |  | 09/02/23
Approuvé
1/ Objet de la demande
Nom du projet : | KOSMOS
Détail de la demande : | Fabrication de KOSMOS
Nombre de système fabriqué : | 4
2/ Demande
Fournisseur | - multiple -
Désignation | Reste à commander | Somme - Prix commande
Frais de ports | 1 | 13,14 €
Tube Inox A4 10mm*1 | 4 | 71,76 €
(vide) | (vide)
Total Résultat |  | 84,90 €

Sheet: NT_Amazon
 | Note de traçabilité
 | Qui | Quand
Etabli |  | 09/02/23
Approuvé
1/ Objet de la demande
Nom du projet : | KOSMOS
Détail de la demande : | Fabrication de KOSMOS
Nombre de système fabriqué : | 4
2/ Demande
Fournisseur | Amazon
Désignation | Reste à commander | Somme - Prix commande
Aimants néodymes carrée | 0 | 0,00 €
Convertisseur de tension de voiture 12v vers 5v | 0 | 0,00 €
Frais de ports | 1 | 0,00 €
Indicateur de niveau de batterie 3S | 0 | 0,00 €
Jeu de connecteurs banannes | 0 | 0,00 €
Jeu de gaines thermo-rétractable | 0 | 0,00 €
Jeu de rilsans | 0 | 0,00 €
Jeu de sertissage de connecteurs jst et dupont | 0 | 0,00 €
Kit de plots raspberry | 4 | 57,07 €
Moteur Brushless de F2838 | 0 | 0,00 €
Nappe Raspberry 40 broches | 4 | 29,44 €
Total Résultat |  | 86,51 €

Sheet: NT_Arianeplast
 | Note de traçabilité
 | Qui | Quand
Etabli |  | 09/02/23
Approuvé
1/ Objet de la demande
Nom du projet : | KOSMOS
Détail de la demande : | Fabrication de KOSMOS
Nombre de système fabriqué : | 4
2/ Demande
Fournisseur | - multiple -
Désignation | Reste à commander | Somme - Prix commande
Bobine de PETG pour imprimante 3D 1Kg | 0 | 0,00 €
Frais de ports | 1 | 10,00 €
(vide) | (vide)
Total Résultat |  | 10,00 €

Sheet: NT_Bricovis
 | Note de traçabilité
 | Qui | Quand
Etabli |  | 09/02/23
Approuvé
1/ Objet de la demande
Nom du projet : | KOSMOS
Détail de la demande : | Fabrication de KOSMOS
Nombre de système fabriqué : | 4
2/ Demande
Fournisseur | - multiple -
Désignation | Reste à commander | Somme - Prix commande
Ecrous freins M5 | 8 | 0,67 €
Ecrous freins M8 | 24 | 5,18 €
Ecrous M3 | 112 | 5,38 €
Ecrous M4 | 8 | 0,38 €
Ecrous M8 | 8 | 1,44 €
Frais de ports | 1 | 7,73 €
Rondelle M3 | 4 | 0,10 €
Rondelles M10*22mm | 16 | 3,07 €
Rondelles M2,5 | 32 | 0,77 €
Rondelles M8*18mm | 24 | 2,30 €
Rondelles M8*22mm | 4 | 0,62 €
Tige Inox M8 | 4 | 23,52 €
Vis TCHC M2,5*12mm | 36 | 5,18 €
Vis TCHC M2,5*18mm | 12 | 2,16 €
Vis TCHC M2,5*5mm | 16 | 1,73 €
Vis TCHC M2,5*6mm | 32 | 3,46 €
Vis TCHC M3*10mm | 24 | 2,02 €
Vis TCHC M3*14mm | 76 | 10,03 €
Vis TCHC M3*16mm | 8 | 0,86 €
Vis TCHC M3*18mm | 16 | 2,69 €
Vis TCHC M3*40mm | 12 | 2,30 €
Vis TCHC M3*5mm | 8 | 0,77 €
Vis TCHC M3*8mm | 24 | 2,02 €
Vis TCHC M4*30mm | 8 | 1,34 €
Vis TCHC M5*30mm | 8 | 2,11 €
Vis TF M3*20mm | 16 | 1,34 €
Vis TFHC M5*20mm | 16 | 2,69 €
Vis TH M5*20mm | 8 | 1,44 €
(vide) | (vide)
Total Résultat |  | 93,31 €

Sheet: NT_Conrad
 | Note de traçabilité
 | Qui | Quand
Etabli |  | 09/02/23
Approuvé
1/ Objet de la demande
Nom du projet : | KOSMOS
Détail de la demande : | Fabrication de KOSMOS
Nombre de système fabriqué : | 4
2/ Demande
Fournisseur | - multiple -
Désignation | Reste à commander | Somme - Prix commande
Carte micro SD 32Go | 0 | 0,00 €
Clé USB Ultra Fit 128Go | 0 | 0,00 €
Connecteurs XT60 femelle | 0 | 0,00 €
Connecteurs XT60 mâles | 0 | 0,00 €
Frais de ports | 1 | 9,59 €
ILS (contact reed) | 0 | 0,00 €
ILS (contact reed) étanche | 0 | 0,00 €
LED 5mm | 0 | 0,00 €
Module Relai Arduino | 0 | 0,00 €
Module RTC DS3231 | 0 | 0,00 €
Résistances 1kohm | 0 | 0,00 €
Résistances 220ohm | 0 | 0,00 €
(vide) | (vide)
Total Résultat |  | 9,59 €

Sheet: NT_Edmundoptics
 | Note de traçabilité
 | Qui | Quand
Etabli |  | 09/02/23
Approuvé
1/ Objet de la demande
Nom du projet : | KOSMOS
Détail de la demande : | Fabrication de KOSMOS
Nombre de système fabriqué : | 4
2/ Demande
Fournisseur | - multiple -
Désignation | Reste à commander | Somme - Prix commande
Frais de ports | 1 | 26,00 €
Objectif 4mm de focale | 0 | 0,00 €
(vide) | (vide)
Total Résultat |  | 26,00 €

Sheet: NT_Intermodel
 | Note de traçabilité
 | Qui | Quand
Etabli |  | 09/02/23
Approuvé
1/ Objet de la demande
Nom du projet : | KOSMOS
Détail de la demande : | Fabrication de KOSMOS
Nombre de système fabriqué : | 4
2/ Demande
Fournisseur | - multiple -
Désignation | Reste à commander | Somme - Prix commande
Batterie Lipo 3s | 0 | 0,00 €
Câbles silicone 14 AWG | 0 | 0,00 €
ESC BLHeli 30A | 0 | 0,00 €
Frais de ports | 1 | 6,75 €
Rallonge de charge de batterie Lipo 3S | 0 | 0,00 €
(vide) | (vide)
Total Résultat |  | 6,75 €

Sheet: NT_Kubii
 | Note de traçabilité
 | Qui | Quand
Etabli |  | 09/02/23
Approuvé
1/ Objet de la demande
Nom du projet : | KOSMOS
Détail de la demande : | Fabrication de KOSMOS
Nombre de système fabriqué : | 4
2/ Demande
Fournisseur | - multiple -
Désignation | Reste à commander | Somme - Prix commande
Caméra HQ officielle | 0 | 0,00 €
Frais de ports | 1 | 0,00 €
Nappe de caméra 30cm | 0 | 0,00 €
Raspberry Pi 4 | 0 | 0,00 €
(vide) | (vide)
Total Résultat |  | 0,00 €

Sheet: NT_Plastiquesurmesure
 | Note de traçabilité
 | Qui | Quand
Etabli |  | 09/02/23
Approuvé
1/ Objet de la demande
Nom du projet : | KOSMOS
Détail de la demande : | Fabrication de KOSMOS
Nombre de système fabriqué : | 4
2/ Demande
Fournisseur | - multiple -
Désignation | Reste à commander | Somme - Prix commande
Frais de ports | 1 | 10,00 €
Plaque de POM 5mm | 2 | 82,40 €
(vide) | (vide)
Total Résultat |  | 92,40 €

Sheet: NT_ROVexpert
 | Note de traçabilité
 | Qui | Quand
Etabli |  | 09/02/23
Approuvé
1/ Objet de la demande
Nom du projet : | KOSMOS
Détail de la demande : | Fabrication de KOSMOS
Nombre de système fabriqué : | 4
2/ Demande
Fournisseur | - multiple -
Désignation | Reste à commander | Somme - Prix commande
Bouchon de purge | 4 | 43,20 €
Bouton rotatif étanche | 4 | 96,00 €
Brides de tube 4’’ | 8 | 412,80 €
Capteur de pression Bar30 | 4 | 408,00 €
Connecteur câblé cobalt | 8 | 441,60 €
Connecteur de cloison Cobalt M0 | 8 | 441,60 €
Frais de ports | 1 | 25,00 €
Tape acrylique transparente 4’’ | 4 | 96,00 €
Tape Aluminium 5 trous 4’’ | 4 | 105,60 €
Tube acrylique 4’’ de 298mm de longueur | 4 | 1 036,80 €
(vide) | (vide)
Total Résultat |  | 3 106,60 €

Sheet: Liste_Materiel
 | Liste des éléments du KOSMOS 3.0
 | Dernière mise à jour : | 9 février 2023
 |  | Nombre de KOSMOS désirés | 4
Catégorie | Désignation | Détails | Qt / K | Qt | Fournisseur | Lien | Prix unitaire | Prix / K | Prix totale | Sous totaux par K | Sous totaux | Stocks | Reste à commander | Prix commande | Etat de la commande
Électronique | Caméra HQ officielle | S’assurer que la bague C-CS soit fourni avec | 1 | 4 | Kubii | https://www.kubii.fr/cameras-capteurs/2950-camera-hq-officielle-633696492738.html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 | 59,90 € | 59,90 € | 239,60 € |  |  | 4 | 0 | 0,00 € | A commander
 | Raspberry Pi 4 | Choisir la raspberry à 2Go de ram | 1 | 4 | Kubii | https://www.kubii.fr/cartes-raspberry-pi/2771-nouveau-raspberry-pi-4-modele-b-2gb-0765756931175.html | 69,90 € | 69,90 € | 279,60 € |  |  | 4 | 0 | 0,00 € | A commander
 | Nappe de caméra 30cm | La caméra a beau être livré avec une nappe, celle-ci reste un peu courte pour notre application | 1 | 4 | Kubii | https://www.kubii.fr/cables-adaptateurs-convertisseurs/432-nappe-cable-pour-raspberry-pi-camera-kubii-3272496001411.html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 | 0,96 € | 0,96 € | 3,84 € |  |  | 4 | 0 | 0,00 € | A commander
 | Carte micro SD 32Go | S’assurer que la vitesse d’écriture est à minima de 10 | 1 | 4 | Conrad | https://www.conrad.fr/fr/p/carte-microsdhc-sandisk-extreme-pro-32-gb-class-10-uhs-i-uhs-class-3-v30-video-speed-class-avec-adaptateur-sd-stand-1553728.html | 19,99 | 19,99 € | 79,96 € |  |  | 4 | 0 | 0,00 € | A commander
 | Clé USB Ultra Fit 128Go | Minimum 32Go, Attrention s’assurer qu’il s’agit d’une clé ultra fit | 1 | 4 | Conrad | https://www.conrad.fr/fr/p/sandisk-cruzer-ultra-fit-cle-usb-128-gb-noir-sdcz430-128g-g46-usb-3-1-gen-1-1650714.html | 41,39 | 41,39 € | 165,56 € |  |  | 4 | 0 | 0,00 € | A commander
 | Module RTC DS3231 |  | 1 | 4 | Conrad | https://www.conrad.fr/fr/p/whadda-wpm352-carte-de-developpement-1-pc-s-2481900.html | 9,49 | 9,49 € | 37,96 € |  |  | 4 | 0 | 0,00 € | A commander
 | Module Relai Arduino |  | 1 | 4 | Conrad | https://www.conrad.fr/fr/p/makerfactory-mf-6402384-module-relais-1-pc-s-convient-pour-kits-de-developpement-arduino-2134128.html | 3,97 € | 3,97 € | 15,88 € |  |  | 4 | 0 | 0,00 € | A commander
 | Indicateur de niveau de batterie 3S | S’assurer qe l’indicateur est dimensionné pour une batterie de 12v soit 3s en Lipo | 1 | 4 | Amazon | https://www.amazon.fr/TECNOIOT-Capacit%C3%A9-Indicateur-batteries-lithium-ion/dp/B09MS69PDJ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 | 16,84 € | 16,84 € | 67,36 € |  |  | 4 | 0 | 0,00 € | A commander
 | Résistances 220ohm |  | 2 | 8 | Conrad | https://www.conrad.fr/fr/p/resistance-a-couche-carbone-yageo-cfr25j220rh-220-sortie-axiale-0207-0-25-w-1-pc-s-1417693.html | 0,08 € | 0,16 € | 0,64 € |  |  | 8 | 0 | 0,00 € | A commander
 | Résistances 1kohm |  | 6 | 24 | Conrad | https://www.conrad.fr/fr/p/yageo-mf0207fte52-1k-resistance-a-couche-metallique-1-k-sortie-axiale-0207-0-6-w-1-1-pc-s-1417606.html | 0,14 € | 0,84 € | 3,36 € |  |  | 24 | 0 | 0,00 € | A commander
 | LED 5mm | On peut sélectionner 2 couleurs (1 verte et 1 rouge) Mais faire attention à la puissance pour la visibilité au soleil | 2 | 8 | Conrad | https://www.conrad.fr/fr/p/huiyuan-5034g3c-bua-b-led-vert-rond-5-mm-18000-mcd-15-20-ma-3-2-v-1526861.html | 0,94 € | 1,88 € | 7,52 € |  |  | 8 | 0 | 0,00 € | A commander
 | ILS (contact reed) |  | 3 | 12 | Conrad | https://www.conrad.fr/fr/p/contact-reed-hamlin-mdcg-4-mdcg-4-1-no-t-200-v-dc-0-5-a-10-w-1-pc-s-506217.html | 1,90 € | 5,70 € | 22,80 € |  |  | 12 | 0 | 0,00 € | A commander
 | ILS (contact reed) étanche |  | 1 | 4 | Conrad | https://www.conrad.fr/fr/p/contact-reed-hamlin-59025-3-t-02-a-59025-3-t-02-a-1-inverseur-rt-175-v-dc-0-25-a-5-w-1-pc-s-503645.html | 6,99 € | 6,99 € | 27,96 € |  |  | 4 | 0 | 0,00 € | A commander
 | Nappe Raspberry 40 broches |  | 1 | 4 | Amazon | https://www.amazon.fr/Diyeeni-Adaptateur-Flexible-qualit%C3%A9-Raspberry/dp/B07RSRCFHN | 7,36 € | 7,36 € | 29,44 € |  |  | 0 | 4 | 29,44 € | A commander
 | Objectif 4mm de focale |  | 1 | 4 | Edmund Optics | edmundoptics.fr/p/4mm-uc-series-fixed-focal-length-lens/2966/ | 220,00 € | 220,00 € | 880,00 € | 465,37 € | 1 861,48 € | 4 | 0 | 0,00 € | A commander
Connectiques et câbles | Jeu de sertissage de connecteurs jst et dupont |  | 1 | 4 | Amazon | https://www.amazon.fr/Preciva-Sertissage-Sertisseuse-Connecteurs-Connecteur/dp/B07QY7K5SW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 | 43,99 € | 43,99 € | 175,96 € |  |  | 4 | 0 | 0,00 € | A commander
 | Câbles silicone 14 AWG |  | 1 | 4 | Intermodel | https://www.intermodel.fr/rallonges-fils/2620-fil-silicone-14-awg-212mm-rougenoir-2x1m-intermodel-fil-prise-rallonge-a2pro-cable-fil-silicone-cable-silicone-s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 | 3,5 | 3,50 € | 14,00 € |  |  | 4 | 0 | 0,00 € | A commander
 | Connecteurs XT60 mâles |  | 2 | 8 | Conrad | https://www.conrad.fr/fr/p/reely-re-6586515-fiche-male-pour-batterie-xt60-3-5-mm-a-souder-1-pc-s-2195505.html | 1,34 | 2,68 € | 10,72 € |  |  | 8 | 0 | 0,00 € | A commander
 | Connecteurs XT60 femelle |  | 1 | 4 | Conrad | https://www.conrad.fr/fr/p/reely-re-6618948-prise-femelle-deluxe-pour-batterie-xt60h-3-5-mm-dore-e-a-souder-1-pc-s-2206316.html | 1,34 | 1,34 € | 5,36 € |  |  | 4 | 0 | 0,00 € | A commander
 | Jeu de gaines thermo-rétractable |  | 1 | 4 | Amazon | https://www.amazon.fr/LIBERRWAR-Gaine-Thermor%C3%A9tractable-Tailles-Ratio/dp/B076KL5K1V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 | 9,99 | 9,99 € | 39,96 € |  |  | 4 | 0 | 0,00 € | A commander
 | Jeu de connecteurs banannes |  | 1 | 4 | Amazon | https://www.amazon.fr/GTIWUNG-Connecteur-Remplacement-Connecteurs-Batterie/dp/B083FNTK5R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 | 17,99 | 17,99 € | 71,96 € | 79,49 € |  | 4 | 0 | 0,00 € | A commander
Energie | Batterie Lipo 3s | Pour une plus grande autonomie on peut prévoir de mettre jusqu’à 4 batterie dans un KOSMOS. Le cas échéant, il faudra prévoir un connecteur en parallèle. | 2 | 8 | Intermodel | https://www.intermodel.fr/accus-batteries/4366-accu-lipo-brainergy-2200mah-3s-30c-rc-plus-lipo-accu-mah-2200.html | 17,90 € | 35,80 € | 143,20 € |  |  | 8 | 0 | 0,00 € | A commander
 | Convertisseur de tension de voiture 12v vers 5v |  | 1 | 4 | Amazon | https://www.amazon.fr/riorand-voiture-Alimentation-convertisseur-module/dp/B00G890MIC | 16,43 € | 16,43 € | 65,72 € |  |  | 4 | 0 | 0,00 € | A commander
 | ESC BLHeli 30A | S’assurer qu’il convient à une batterie 3s | 2 | 8 | Intermodel | https://www.intermodel.fr/controleurs-variateurs/4848-esc-30a-blheli-emax-emax-controleur-6a-30a-emax-20a-12a-blheli-25a.html | 23,60 € | 47,20 € | 188,80 € |  |  | 8 | 0 | 0,00 € | A commander
 | Rallonge de charge de batterie Lipo 3S | Acheter autant de rallonge qu’il y aura de batteries | 1 | 4 | Intermodel | https://www.intermodel.fr/cordons-et-prises-de-charge/549-rallonge-pour-prise-equilibrage-3s-intermodel-rallonge-3s-rallonge-prise-equilibrage-3s.html | 1,10 € | 1,10 € | 4,40 € |  |  | 4 | 0 | 0,00 € | A commander
 | Moteur Brushless de F2838 | S’assurer qu’il soit vendu câblé | 1 | 4 | Amazon | https://www.amazon.fr/dp/B07ZXCQHLX?s=toys&sp_csd=d2lkZ2V0TmFtZT1zcF9kZXRhaWw | 52,37 € | 52,37 € | 209,48 € | 152,90 € | 611,60 € | 4 | 0 | 0,00 € | A commander
Etanchéité | Bouton rotatif étanche |  | 1 | 4 | Rov Expert | https://rov-expert.fr/blue-robotics/101-Interrupteur.html | 24,00 € | 24,00 € | 96,00 € |  |  | 0 | 4 | 96,00 € | A commander
 | Bouchon de purge |  | 1 | 4 | Rov Expert | https://rov-expert.fr/blue-robotics/38-aeration-et-bouchon.html | 10,80 € | 10,80 € | 43,20 € |  |  | 0 | 4 | 43,20 € | A commander
 | Capteur de pression Bar30 |  | 1 | 4 | Rov Expert | https://rov-expert.fr/blue-robotics/8-bar30-capteur-de-pression-haute-resolution-300m.html | 102,00 € | 102,00 € | 408,00 € |  |  | 0 | 4 | 408,00 € | A commander
 | Connecteur de cloison Cobalt M0 | Sélectionner le connecteur à 3 contacts | 2 | 8 | Rov Expert | https://rov-expert.fr/blue-trail-engineering/140-132-connecteur-de-cloison-cobalt-m10.html | 55,20 € | 110,40 € | 441,60 € |  |  | 0 | 8 | 441,60 € | A commander
 | Connecteur câblé cobalt | Sélectionner le connecteur à 3 contacts | 2 | 8 | Rov Expert | https://rov-expert.fr/blue-trail-engineering/141-136-connecteur-cobalt.html | 55,20 € | 110,40 € | 441,60 € |  |  | 0 | 8 | 441,60 € | A commander
 | Tape Aluminium 5 trous 4’’ | Cette pièce est généralement fournie avec 6 vis de bonne longueur | 1 | 4 | Rov Expert | https://rov-expert.fr/blue-robotics/4-6-tape-aluminium.html#/6-declinaison-5_trous_4_ | 26,40 € | 26,40 € | 105,60 € |  |  | 0 | 4 | 105,60 € | A commander
 | Tape acrylique transparente 4’’ | Cette pièce est généralement fournie avec 6 vis de bonne longueur | 1 | 4 | Rov Expert | https://rov-expert.fr/blue-robotics/30-tape-acrylique-transparente.html | 24,00 € | 24,00 € | 96,00 € |  |  | 0 | 4 | 96,00 € | A commander
 | Brides de tube 4’’ |  | 2 | 8 | Rov Expert | https://bluerobotics.com/store/watertight- | 51,60 € | 103,20 € | 412,80 € |  |  | 0 | 8 | 412,80 € | A commander
 | Tube acrylique 4’’ de 298mm de longueur |  | 1 | 4 | Rov Expert | enclosures/locking-series/wte-flange-vp/ | 259,20 € | 259,20 € | 1 036,80 € | 770,40 € | 3 081,60 € | 0 | 4 | 1 036,80 € | A commander
 |  |  |  |  |  | enclosures/locking-series/wte-locking-tube-
Visserie | Tube Inox A4 10mm*1 | s’assurer que le diamètre interne soit bien de 8mm au minimum. 1 mètre de longueur suffira | 1 | 4 | Acier au Détail | r1-vp/ | 17,94 € | 17,94 € | 71,76 € |  |  | 0 | 4 | 71,76 € | A commander
 | Tige Inox M8 |  | 1 | 4 | Bricovis | https://www.bricovis.fr/produit-tige-filetee-inox-a4-din-975-tigea4/#TIGE08A4 | 5,88 € | 5,88 € | 23,52 € |  |  | 0 | 4 | 23,52 € | A commander
 | Vis TCHC M2,5*5mm |  | 4 | 16 | Bricovis | https://www.bricovis.fr/produit-vis-a-tete-cylindrique-hexagonale-creuse-inox-a4-filetage-total-din-912-tchca4ef/ | 0,11 € | 0,43 € | 1,73 € |  |  | 0 | 16 | 1,73 € | A commander
 | Vis TCHC M2,5*6mm |  | 8 | 32 | Bricovis | https://www.bricovis.fr/produit-vis-a-tete-cylindrique-hexagonale-creuse-inox-a4-filetage-total-din-912-tchca4ef/ | 0,11 € | 0,86 € | 3,46 € |  |  | 0 | 32 | 3,46 € | A commander
 | Vis TCHC M2,5*12mm |  | 9 | 36 | Bricovis | https://www.bricovis.fr/produit-vis-a-tete-cylindrique-hexagonale-creuse-inox-a4-filetage-total-din-912-tchca4ef/ | 0,14 € | 1,30 € | 5,18 € |  |  | 0 | 36 | 5,18 € | A commander
 | Vis TCHC M2,5*18mm |  | 3 | 12 | Bricovis | https://www.bricovis.fr/produit-vis-a-tete-cylindrique-hexagonale-creuse-inox-a4-filetage-total-din-912-tchca4ef/ | 0,18 € | 0,54 € | 2,16 € |  |  | 0 | 12 | 2,16 € | A commander
 | Vis TCHC M3*5mm |  | 2 | 8 | Bricovis | https://www.bricovis.fr/produit-vis-a-tete-cylindrique-hexagonale-creuse-inox-a4-filetage-total-din-912-tchca4ef/ | 0,10 € | 0,19 € | 0,77 € |  |  | 0 | 8 | 0,77 € | A commander
 | Vis TCHC M3*8mm |  | 6 | 24 | Bricovis | https://www.bricovis.fr/produit-vis-a-tete-cylindrique-hexagonale-creuse-inox-a4-filetage-total-din-912-tchca4ef/ | 0,08 € | 0,50 € | 2,02 € |  |  | 0 | 24 | 2,02 € | A commander
 | Vis TCHC M3*10mm |  | 6 | 24 | Bricovis | https://www.bricovis.fr/produit-vis-a-tete-cylindrique-hexagonale-creuse-inox-a4-filetage-total-din-912-tchca4ef/ | 0,08 € | 0,50 € | 2,02 € |  |  | 0 | 24 | 2,02 € | A commander
 | Vis TCHC M3*14mm |  | 19 | 76 | Bricovis | https://www.bricovis.fr/produit-vis-a-tete-cylindrique-hexagonale-creuse-inox-a4-filetage-total-din-912-tchca4ef/ | 0,13 € | 2,51 € | 10,03 € |  |  | 0 | 76 | 10,03 € | A commander
 | Vis TCHC M3*16mm |  | 2 | 8 | Bricovis | https://www.bricovis.fr/produit-vis-a-tete-cylindrique-hexagonale-creuse-inox-a4-filetage-total-din-912-tchca4ef/ | 0,11 € | 0,22 € | 0,86 € |  |  | 0 | 8 | 0,86 € | A commander
 | Vis TCHC M3*18mm |  | 4 | 16 | Bricovis | https://www.bricovis.fr/produit-vis-a-tete-cylindrique-hexagonale-creuse-inox-a4-filetage-total-din-912-tchca4ef/ | 0,17 € | 0,67 € | 2,69 € |  |  | 0 | 16 | 2,69 € | A commander
 | Vis TCHC M3*40mm |  | 3 | 12 | Bricovis | https://www.bricovis.fr/produit-vis-a-tete-cylindrique-hexagonale-creuse-inox-a4-filetage-partiel-din-912-tchca4pf/ | 0,19 € | 0,58 € | 2,30 € |  |  | 0 | 12 | 2,30 € | A commander
 | Vis TCHC M4*30mm |  | 2 | 8 | Bricovis | https://www.bricovis.fr/produit-vis-a-tete-cylindrique-hexagonale-creuse-inox-a4-filetage-partiel-din-912-tchca4pf/ | 0,17 € | 0,34 € | 1,34 € |  |  | 0 | 8 | 1,34 € | A commander
 | Vis TCHC M5*30mm |  | 2 | 8 | Bricovis | https://www.bricovis.fr/produit-vis-a-tete-cylindrique-hexagonale-creuse-inox-a4-filetage-partiel-din-912-tchca4pf/ | 0,26 € | 0,53 € | 2,11 € |  |  | 0 | 8 | 2,11 € | A commander
 | Vis TF M3*20mm |  | 4 | 16 | Bricovis | https://www.bricovis.fr/produit-vis-a-tete-fraisee-inox-a4-din-963-tffa4/#TF03/020A4 | 0,08 € | 0,34 € | 1,34 € |  |  | 0 | 16 | 1,34 € | A commander
 | Vis TH M5*20mm |  | 2 | 8 | Bricovis | https://www.bricovis.fr/produit-vis-a-tete-hexagonale-inox-a4-filetage-total-din-933-tha4ef/ | 0,18 € | 0,36 € | 1,44 € |  |  | 0 | 8 | 1,44 € | A commander
 | Vis TFHC M5*20mm |  | 4 | 16 | Bricovis | https://www.bricovis.fr/produit-vis-a-tete-fraisee-hexagonale-creuse-filetage-total-inox-a4-din-7991-tfhca4/ | 0,17 € | 0,67 € | 2,69 € |  |  | 0 | 16 | 2,69 € | A commander
 | Ecrous M3 |  | 28 | 112 | Bricovis | https://www.bricovis.fr/produit-ecrou-hu-inox-a4-din-934-ecrhua4/#ECRHU03A4 | 0,05 € | 1,34 € | 5,38 € |  |  | 0 | 112 | 5,38 € | A commander
 | Ecrous freins M5 |  | 2 | 8 | Bricovis | https://www.bricovis.fr/produit-ecrou-nylstop-inox-a4-din-985-ecrnyla4/#ECRNYL05A4 | 0,08 € | 0,17 € | 0,67 € |  |  | 0 | 8 | 0,67 € | A commander
 | Ecrous M4 |  | 2 | 8 | Bricovis | https://www.bricovis.fr/produit-ecrou-hu-inox-a4-din-934-ecrhua4/#ECRHU04A4 | 0,05 € | 0,10 € | 0,38 € |  |  | 0 | 8 | 0,38 € | A commander
 | Ecrous M8 |  | 2 | 8 | Bricovis | https://www.bricovis.fr/produit-ecrou-hu-inox-a4-din-934-ecrhua4/#ECRHU08A4 | 0,18 € | 0,36 € | 1,44 € |  |  | 0 | 8 | 1,44 € | A commander
 | Ecrous freins M8 |  | 6 | 24 | Bricovis | https://www.bricovis.fr/produit-ecrou-nylstop-inox-a4-din-985-ecrnyla4/#ECRNYL08A4 | 0,22 € | 1,30 € | 5,18 € |  |  | 0 | 24 | 5,18 € | A commander
 | Rondelles M2,5 |  | 8 | 32 | Bricovis | https://www.bricovis.fr/produit-rondelle-m-inox-a4-nfe-25513-ronma4/#RONM02.5A4 | 0,02 € | 0,19 € | 0,77 € |  |  | 0 | 32 | 0,77 € | A commander
 | Rondelle M3 |  | 1 | 4 | Bricovis | https://www.bricovis.fr/produit-rondelle-m-inox-a4-nfe-25513-ronma4/#RONM03A4 | 0,02 € | 0,02 € | 0,10 € |  |  | 0 | 4 | 0,10 € | A commander
 | Rondelles M8*22mm |  | 1 | 4 | Bricovis | https://www.bricovis.fr/produit-rondelle-l-inox-a4-nfe-25513-ronla4/#RONL08A4 | 0,16 € | 0,16 € | 0,62 € |  |  | 0 | 4 | 0,62 € | A commander
 | Rondelles M8*18mm |  | 6 | 24 | Bricovis | https://www.bricovis.fr/produit-rondelle-m-inox-a4-nfe-25513-ronma4/#RONM08A4 | 0,10 € | 0,58 € | 2,30 € |  |  | 0 | 24 | 2,30 € | A commander
 | Rondelles M10*22mm |  | 4 | 16 | Bricovis | https://www.bricovis.fr/produit-rondelle-m-inox-a4-nfe-25513-ronma4/#RONM10A4 | 0,19 € | 0,77 € | 3,07 € |  |  | 0 | 16 | 3,07 € | A commander
 | Kit de plots raspberry |  | 1 | 4 | Amazon | https://www.amazon.fr/Geekworm-Raspberry-Installation-Hexagonale-Accessoires/dp/B07MN2GY6Y | 14,27 € | 14,27 € | 57,07 € | 53,60 € | 214,42 € | 0 | 4 | 57,07 € | A commander
Matériaux | Bobine de PETG pour imprimante 3D 1Kg | S’assurer que le diamètre et la marque convienne pour l’imprimante 3D qui sera utilisé. Choisir une couleur qui distinguera vos KOSMOS | 1 | 4 | Arianeplast | https://www.arianeplast.com/218-3d-filament-petg | 24,00 € | 24,00 € | 96,00 € |  |  | 4 | 0 | 0,00 € | A commander
 | Plaque de PMMA incolore 5mm 450* 350mm | Pour une découpe au laser, assurez-vous qu’il s’agit d’un matériau sans chlore. Choisir les dimensions convenants au plateau du laser. | 1 | 4 | A la decoupe | https://www.aladecoupe.com/fr/pmma-transparent-plexi/13-pmma-extrude-transparent-5-mm.html | 12,35 € | 12,35 € | 49,40 € |  |  | 4 | 0 | 0,00 € | A commander
 | Plaque de POM 5mm | Choisir les dimensions convenants au plateau du laser. | 1 | 4 | Plastique sur mesure | https://plastiquesurmesure.com/plaque-pom-sur-mesure-delrin/477-plaque-pom-delrin-blanc-opaque-satine-ep-5-mm.html | 41,20 € | 41,20 € | 164,80 € | 77,55 € | 310,20 € | 2 | 2 | 82,40 € | A commander
Autres | Jeu de rilsans | Divers rilsans pour des petites pièces | 1 | 4 | Amazon | https://www.amazon.fr/intervisio-Collier-Serrage-Colliers-Serre-Cable/dp/B0894YPC93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 | 7,95 € | 7,95 € | 31,80 € |  |  | 4 | 0 | 0,00 € | A commander
 | PCB | Le PCB sera a fabriquer soit même ou à commander à un fabriquant | 1 | 4 | Konk Ar Lab |  | 20,00 € | 20,00 € | 80,00 € |  |  | 4 | 0 | 0,00 € | A commander
 | Aimants néodymes carrée | S’assurer des dimensions : 10*10*4mm | 1 | 4 | Amazon | https://www.amazon.fr/Yizhet-Puissant-Bricolage-r%C3%A9frig%C3%A9rateur-10X10X4mm/dp/B07H2BVXDL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 | 12,46 € | 12,46 € | 49,84 € | 40,41 € | 161,64 € | 4 | 0 | 0,00 € | A commander
Frais de ports | Frais de ports |  | 1 | 1 | Amazon |  | 0 | 0,00 € | 0,00 € |  |  | 0 | 1 | 0,00 €
 | Frais de ports |  | 1 | 1 | Conrad |  | 9,59 | 9,59 € | 9,59 € |  |  | 0 | 1 | 9,59 €
 | Frais de ports |  | 1 | 1 | Bricovis |  | 7,73 | 7,73 € | 7,73 € |  |  | 0 | 1 | 7,73 €
 | Frais de ports |  | 1 | 1 | Konk Ar Lab |  | 0 | 0,00 € | 0,00 € |  |  | 0 | 1 | 0,00 €
 | Frais de ports |  | 1 | 1 | Plastique sur mesure |  | 10 | 10,00 € | 10,00 € |  |  | 0 | 1 | 10,00 €
 | Frais de ports |  | 1 | 1 | A la decoupe |  | 16,58 | 16,58 € | 16,58 € |  |  | 0 | 1 | 16,58 €
 | Frais de ports |  | 1 | 1 | Arianeplast |  | 10 | 10,00 € | 10,00 € |  |  | 0 | 1 | 10,00 €
 | Frais de ports |  | 1 | 1 | ROV expert |  | 25 | 25,00 € | 25,00 € |  |  | 0 | 1 | 25,00 €
 | Frais de ports |  | 1 | 1 | Intermodel |  | 6,75 | 6,75 € | 6,75 € |  |  | 0 | 1 | 6,75 €
 | Frais de ports |  | 1 | 1 | Edmund Optics |  | 26 | 26,00 € | 26,00 € |  |  | 0 | 1 | 26,00 €
 | Frais de ports |  | 1 | 1 | Kubii |  | 0 | 0,00 € | 0,00 € |  |  | 0 | 1 | 0,00 €
 | Frais de ports |  | 1 | 1 | Acier au Détail |  | 13,14 | 13,14 € | 13,14 € | 124,79 € | 124,79 € | 0 | 1 | 13,14 €
 |  |  |  |  |  |  |  | Total (Hors frais de ports) |  | 1 639,72 € | 6 240,94 €
 |  |  |  |  |  |  |  | Total (TTC) |  | 1 764,51 € | 6 365,73 € | Totale des commandes |  | 3 532,65 €
 |  |  |  |  | Etat
 |  |  |  |  | A commander
 |  |  |  |  | En attente de réception
 |  |  |  |  | Reçu
 |  |  |  |  | Colis perdu

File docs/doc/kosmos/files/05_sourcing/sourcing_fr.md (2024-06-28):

icon:fontawesome/solid/list
# Nomenclature / Le sourcing

Le sourcing est la première étape du projet et souvent la plus fastidieuse. Sourcer désigne le fait de rassembler tout ce qui sera nécéssaire pour fabriquer un KOSMOS. Ce projet demande des composants que l'on trouvera chez un grand-nombre de fournisseurs différents. De plus, ces fournisseurs peuvent différer en fonction du lieu et du moment où l'on va construire un KOSMOS.

**Attention :** Veiller à effectuer ce travail préparatoire bien avant la fabrication. En effet, certaines commandes peuvent avoir de long délais. Et cela sans compter le temps nécessaire pour le travail du sourcing lui-même. 

## 1. Présentation du fichier de sourcing

 - [Télécharger le fichier de sourcing](sourcing_kosmos30_fr_221024.ods), ou chercher dans le [dossier "doc/files/05_sourcing"]('../05_sourcing/') un tableur qui conviendrait d'avantage à votre région ou plus proche en temps de votre date d'achat. 
 - Ouvrir le fichier de sourcing au moyen d'un tableur. Ce fichier a été créé au moyen du logiciel libre [Libre office calc](https://fr.libreoffice.org/download/telecharger-libreoffice/) mais pourra très bien être ouvert par d'autres logiciels de tableurs.

 - Ce fichier se compose d'un onglet listant tous les composants et plusieurs autres onglets dont chacun permettra au moyen d'un tableau croisé dynamique de réaliser des notes de tracabilités (ceci permettra de faciliter le travail de validation par votre administration avant l'achat):

### 1.1 Détails du tableau "Liste des éléments du KOSMOS 3.0"

SG1-1

 - **Catégorie :** Catégorie de composants (ex : Electronique, Visserie...)
 - **Désignation :** Appellation du composant
 - **Détails :** Information complémentaire, souvent des détails auquel faire attention.
 - **Qt / K :** Quantité pour un KOSMOS,
 - **Qt :** Quantité nécessaire totale pour tous les KOSMOS que l'on souhaite fabriquer,
 - **Fournisseur :** Nom du fournisseur,
 - **Lien :** Lien d'achat,
 - **Prix unitaire :** Prix d'un seul composant,
 - **Prix /K :** Prix des composants de même nom pour un seul KOSMOS,
 - **Prix totale :** Prix des composants de même nom pour tous les KOSMOS que l'on souhaite fabriquer,
 - **Stocks :** Nombre de pièces déjà en stock,
 - **Reste à commander :** Nombre de pièces qu'il reste à commander,
 - **Prix commande :** Prix total de chacun des groupes de composants qu'il reste à commander,
 - **Etat de la commande :** Cette colonne permet de sélectionner l'état de l'approvisionnement pour chacun des composant listé. Il existe 4 états : "A commander", "En attente de réception", "Reçu" et "Colis perdu"

### 1.2 Détails d'une table "note de traçabilité"

SG1-2

 - Dans la seconde partie on pourra modifier au moyen d'un menu déroulant le nom du fournisseur. 
 - Le nombre de composants et les prix affichés correspondent aux quantités après déduction du stock (cf. 1.1 Détails...)
 - Noter que si la valeur renseignée dans la colonne "stocks" de la table "Liste_Materiel" est supérieure ou égale à la quantité totale nécéssaire, la quantité restante à acheter sera de 0. 

## 2. Utilisation du tableur pour sourcer

### 2.1 Mettre à jour les informations des composants

 - Se rendre dans l'onglet "Liste_Matériel"
 - Toutes les cases colorés en jaune sont à éditer en priorité : Changer le nombre de KOSMOS désirés et remplir la colonne des stocks (colonne"N"). Renseigner "0" si aucun composant en stock.
 - Consulter chaque lien un par un (colonne"H"), vérifier que le fournisseur convient, que le prix unitaire correspond bien à celui indiqué dans le tableau. Dans le cas contraire modifier la valeur dans la colonne "I".
 - Si le fournisseur ne distribue plus ce composant, ou que le fournisseur ne convient pas, chercher le composant ailleurs puis mettre à jour les colonnes "G" "H" et "I" avec les informations du nouveau fournisseur.
 - Surveiller ainsi ces éléments pour chacune des lignes de l'onglet "Liste_Materiel".

### 2.2 Actualiser les notes de traçabilités

 - Éditer l'entête et la partie "1/" comme désiré,
 - Pour mettre à jour la table croisée, cliquer droit sur "fournisseur" puis "actualiser",
 - Créer un onglet pour chaque fournisseur listé. 

## 3. Contribuer

Dans le cas où vous avez modifié le tableur avec des fournisseurs différents ce due au fait que vous ne résidez pas dans la même région ou pour toute autre raison, vos informations pourraient bénéficier par la suite à d'autres personnes.

**Pour contribuer**, déposez votre fichier dans le git à [l'emplacement suivant doc/files/05_sourcing]('../05_sourcing/').

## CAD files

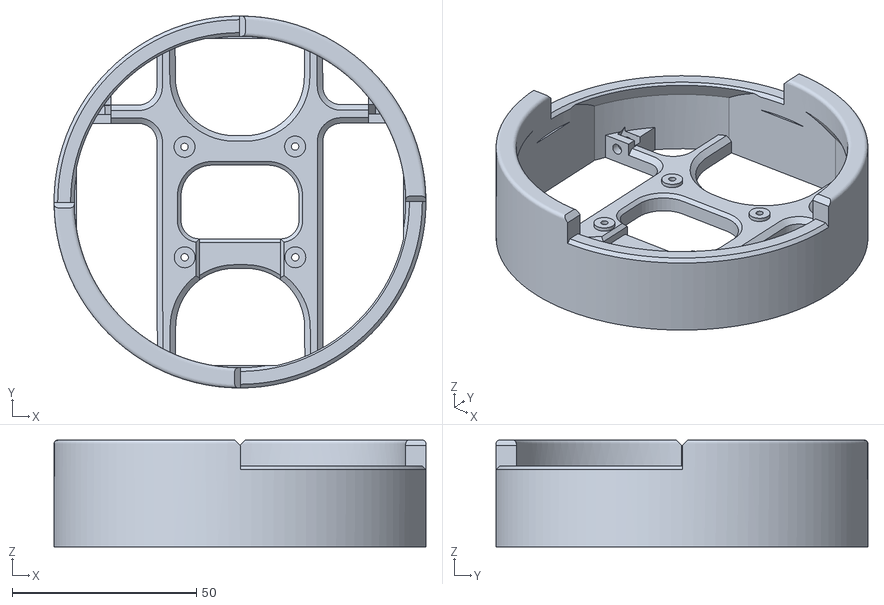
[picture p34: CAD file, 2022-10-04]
docs/hardware/kosmos/3Dprint_files/I3_KOSMOS_V3-0.stl
100.9 x 100.9 x 29.0

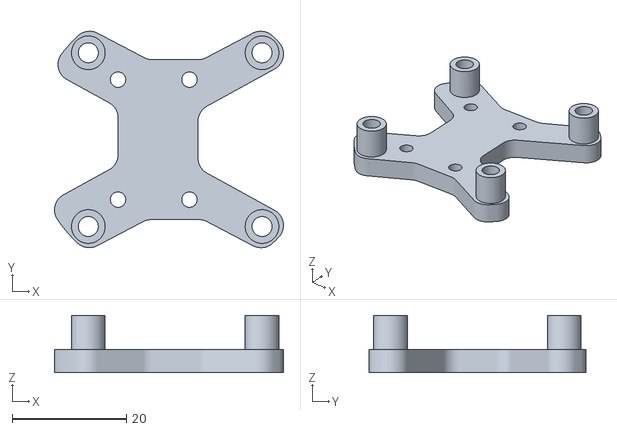
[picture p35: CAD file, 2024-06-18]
docs/hardware/micro_kosmos/3Dprint_files/caisson_video/Support_carte_caisson.stl
40.1 x 37.9 x 10.0

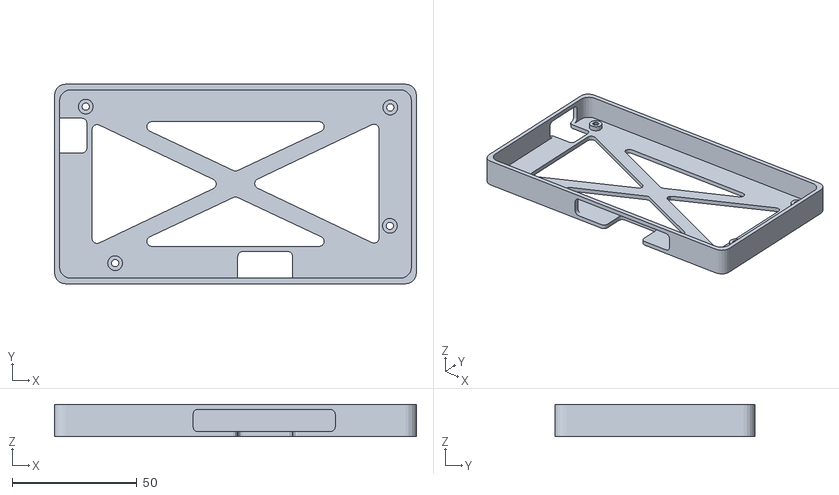
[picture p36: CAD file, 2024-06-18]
docs/hardware/micro_kosmos/3Dprint_files/casque/Support_ecran.stl
145.0 x 80.0 x 13.0

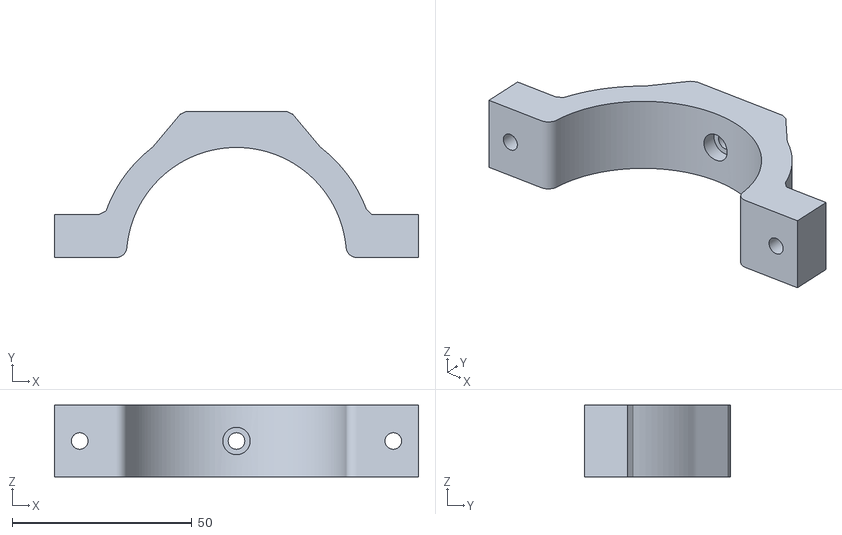
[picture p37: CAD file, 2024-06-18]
docs/hardware/micro_kosmos/3Dprint_files/trepied/Trepied_CollierSupérieur.stl
101.2 x 40.6 x 20.0

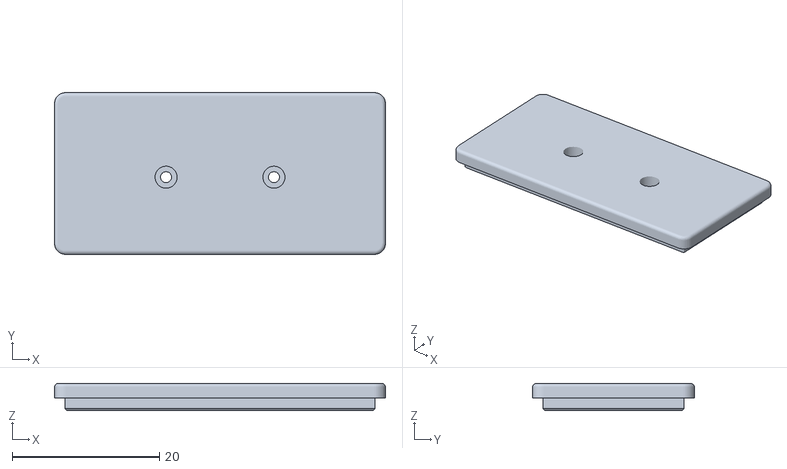
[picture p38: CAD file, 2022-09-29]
docs/hardware/kosmos/3Dprint_files/R8-2_KOSMOS_V3-0.stl
45.0 x 22.0 x 3.70

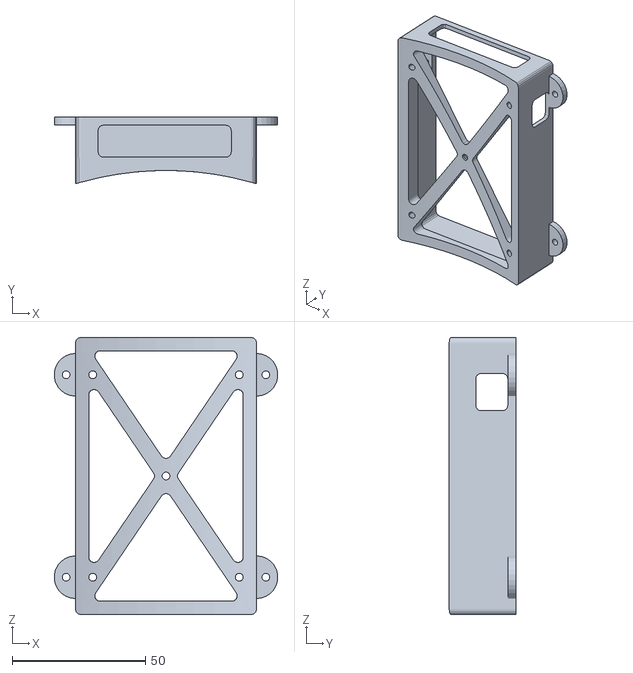
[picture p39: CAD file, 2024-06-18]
docs/hardware/micro_kosmos/3Dprint_files/casque/Support_batterie_BOT.stl
83.9 x 25.0 x 104.0

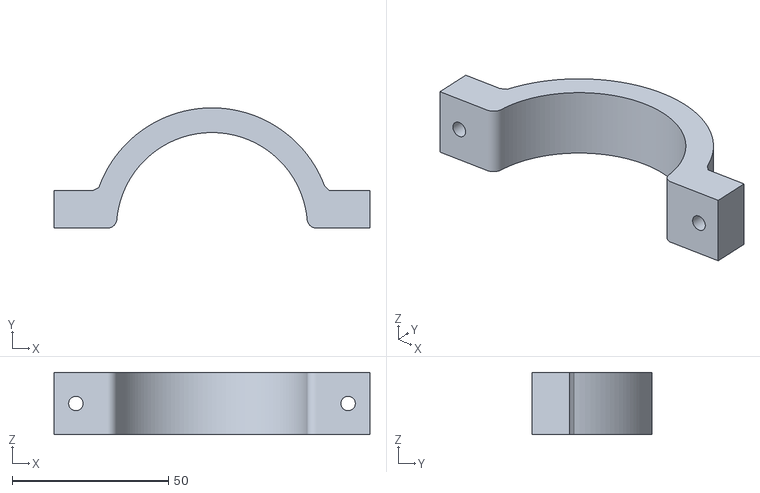
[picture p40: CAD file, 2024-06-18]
docs/hardware/micro_kosmos/3Dprint_files/trepied/Trepied_CollierInférieur.stl
101.2 x 38.5 x 20.0

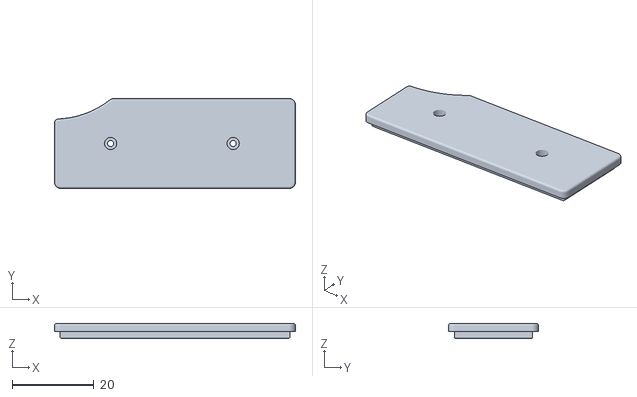
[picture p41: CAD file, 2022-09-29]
docs/hardware/kosmos/3Dprint_files/R7-2_KOSMOS_V3-0.stl
59.0 x 22.0 x 3.70

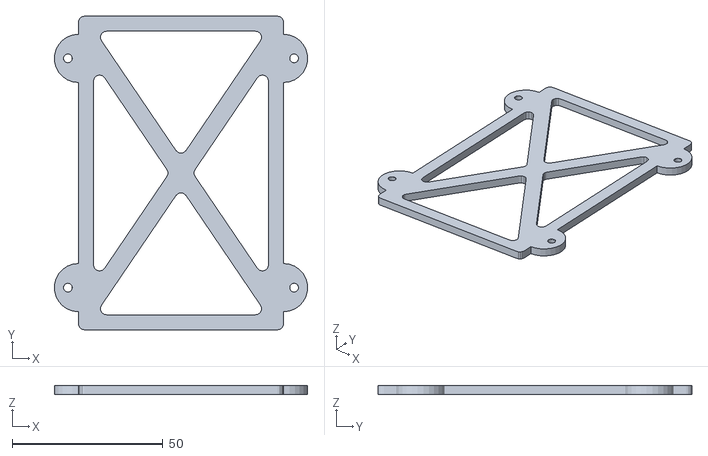
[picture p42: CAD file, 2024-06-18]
docs/hardware/micro_kosmos/3Dprint_files/casque/Support_batterie_TOP.stl
83.9 x 104.0 x 3.00

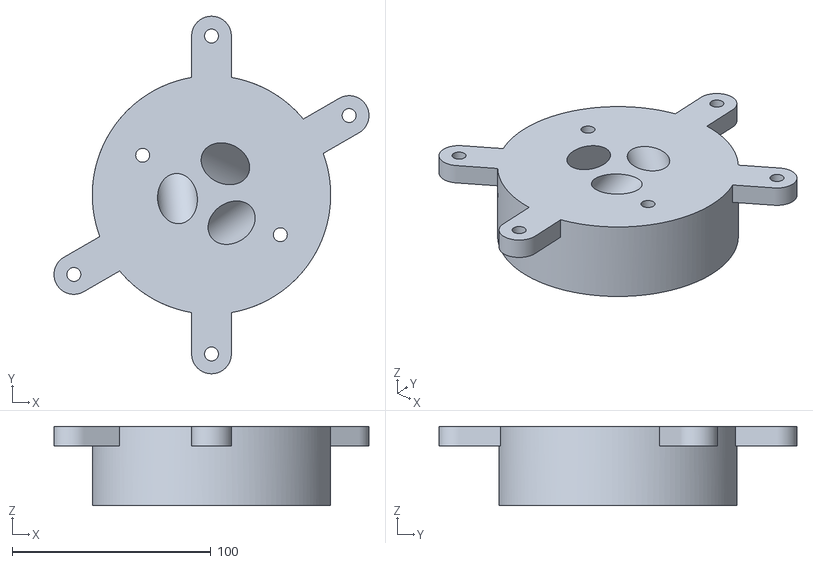
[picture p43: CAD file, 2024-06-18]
docs/hardware/micro_kosmos/3Dprint_files/trepied/Trepied_SocleInferieur.stl
158.6 x 180.0 x 40.0

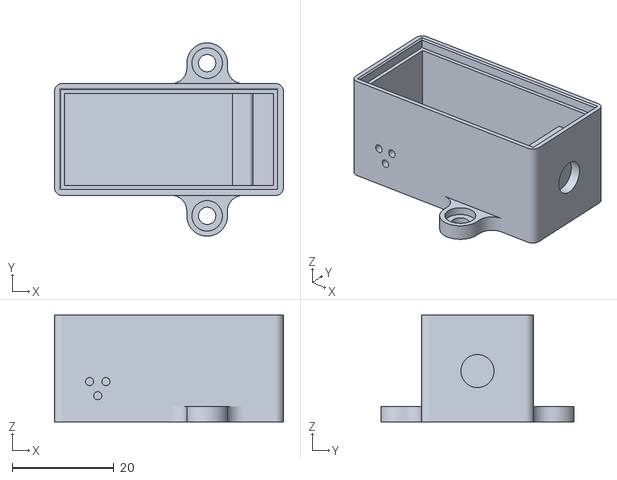
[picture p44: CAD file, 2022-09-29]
docs/hardware/kosmos/3Dprint_files/R8_KOSMOS_V3-0.stl
45.0 x 38.0 x 21.0

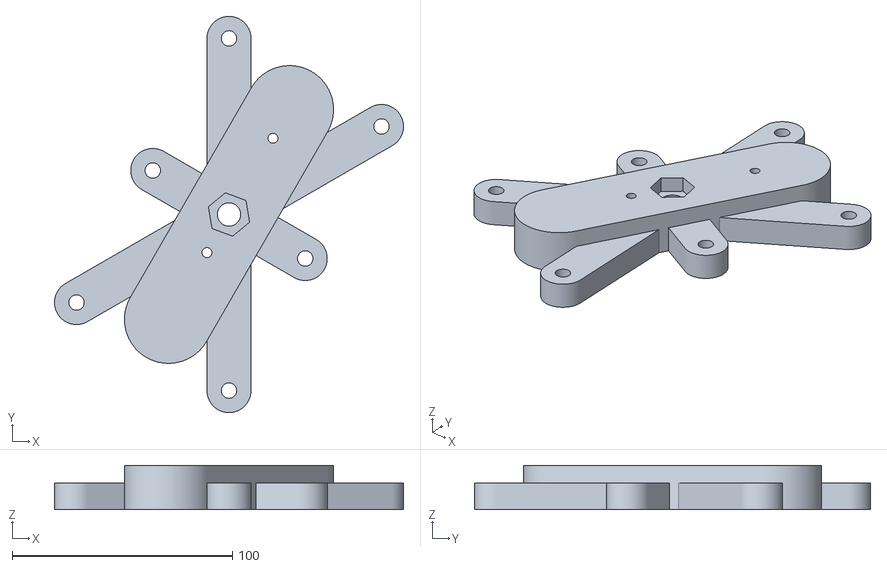
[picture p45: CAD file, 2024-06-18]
docs/hardware/micro_kosmos/3Dprint_files/trepied/Trepied_SocleSupérieur.stl
158.6 x 180.0 x 20.0

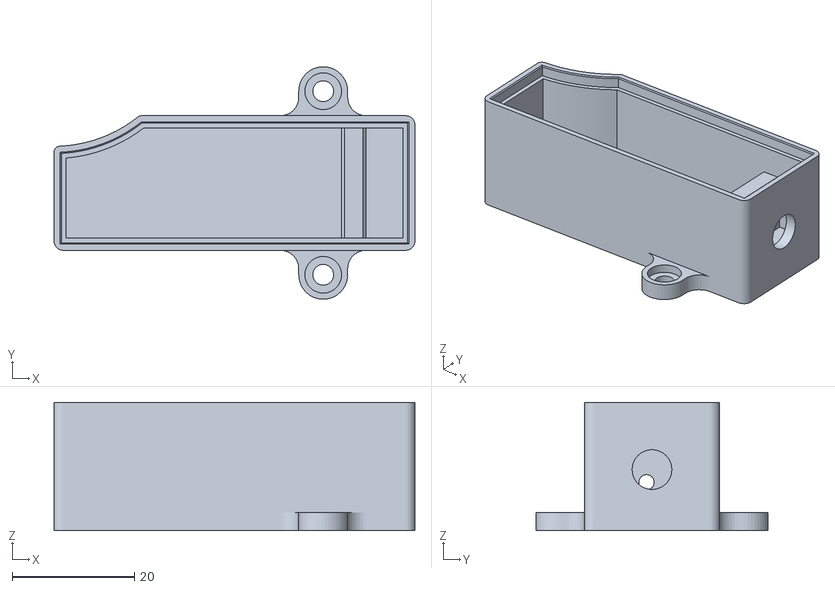
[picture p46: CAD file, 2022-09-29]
docs/hardware/kosmos/3Dprint_files/R7_KOSMOS_V3-0.stl
59.0 x 38.0 x 21.0

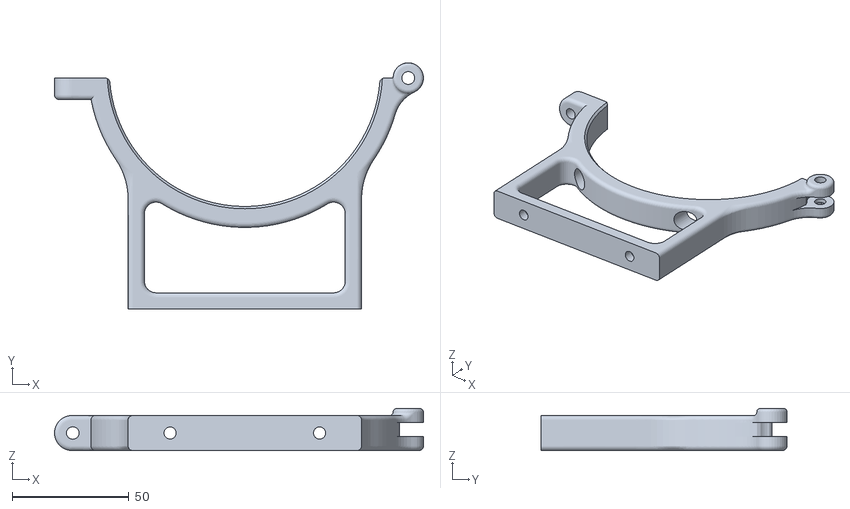
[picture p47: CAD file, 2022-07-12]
docs/hardware/kosmos/3Dprint_files/R1_KOSMOS_V3-0.stl
158.0 x 105.5 x 18.0

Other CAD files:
docs/hardware/kosmos/3Dprint_files/R3_KOSMOS_V3-0.stl
docs/hardware/kosmos/3Dprint_files/I2_KOSMOS_V3-0.stl
docs/hardware/kosmos/3Dprint_files/R6_KOSMOS_V3-0.stl
docs/hardware/kosmos/3Dprint_files/I4_KOSMOS_V3-0.stl
docs/hardware/kosmos/3Dmodels_editable/Assembly/Assemblage_ber_KOSMOS3-0.f3z
docs/hardware/kosmos/3Dmodels_editable/Assembly/Assemblage_croix_de_malte_KOSMOS3-0.f3z
docs/hardware/kosmos/3Dmodels_editable/Assembly/Assemblage_moteur_KOSMOS3-0.f3z
docs/hardware/kosmos/3Dmodels_editable/Inside/Structure_batterie_KOSMOS3-0.f3d
docs/hardware/kosmos/3Dmodels_editable/Inside/Structure_camera_KOSMOS3-0.f3d
docs/hardware/kosmos/3Dmodels_editable/Inside/Structure_hublot_KOSMOS3-0.f3d
docs/hardware/kosmos/3Dmodels_editable/Inside/Structure_raspberry_KOSMOS3-0.f3d
docs/hardware/kosmos/3Dmodels_editable/Inside/Support_batteries_PCB_KOSMOS3-0.f3d
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

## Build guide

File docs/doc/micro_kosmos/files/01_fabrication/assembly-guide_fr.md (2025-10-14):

icon:material/cog
## 1. Assemblage du boitier électronique

### Etape 1 - Réalisation les raccordements entre les câbles et les connecteurs

??? Matériel

    [Matériel boitier électronique](../../../../hardware/micro_kosmos/02_materiel_boitier_electronique.md)

#### Relier un câble USB à un câble micro USB en passant par le commutateur 

???+ info

    Ce câble fera le lien entre la batterie et la Raspberry et permetta d'alimenter la carte. Le commutateur permet de couper le courant sans débrancher les câbles.

- couper le câble USB à une trentaine de centimètre du branchement USB  
- enfiler la gaine thermo sur le câble (elle sera chauffée à la fin)  
- utiliser les connecteurs cosses pour faire le lien entre les pins du commutateur et le câble USB, brancher le fil noir et le fil rouge  
- chauffer la gaine thermo pour recouvrir tous les fils  
- répéter les mêmes étapes avec le câble micro USB et le commutateur  

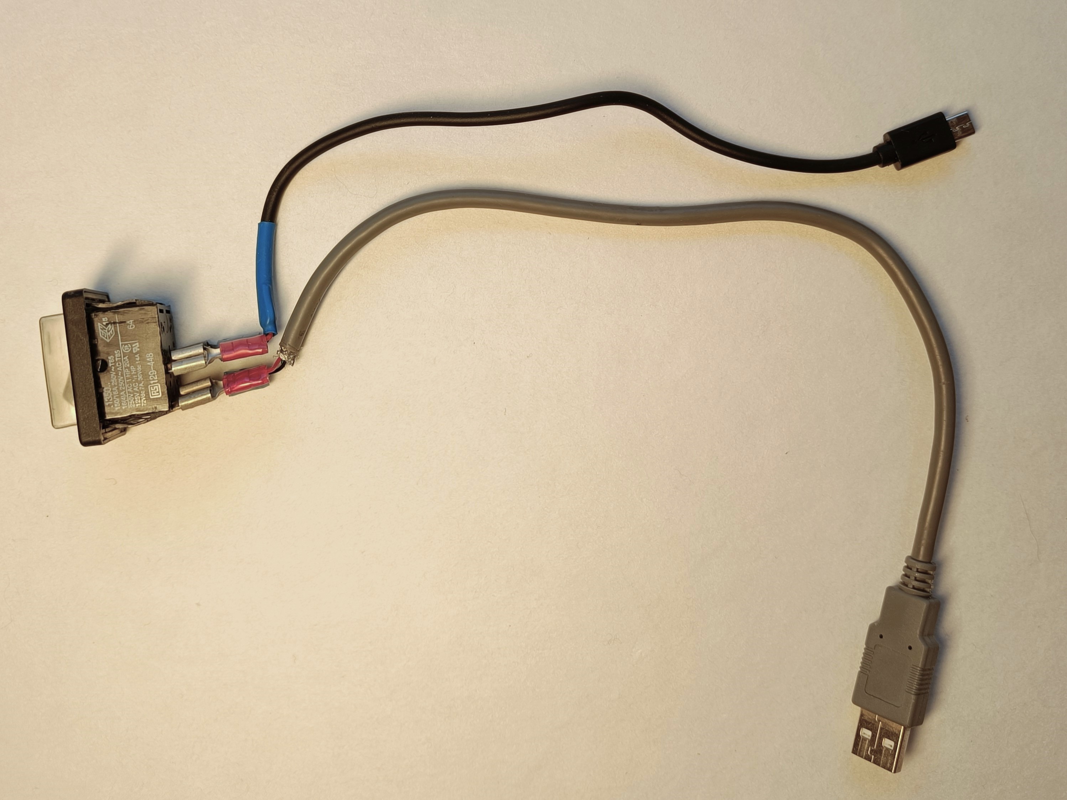
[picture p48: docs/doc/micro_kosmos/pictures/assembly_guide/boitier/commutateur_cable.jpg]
commutateur_cable
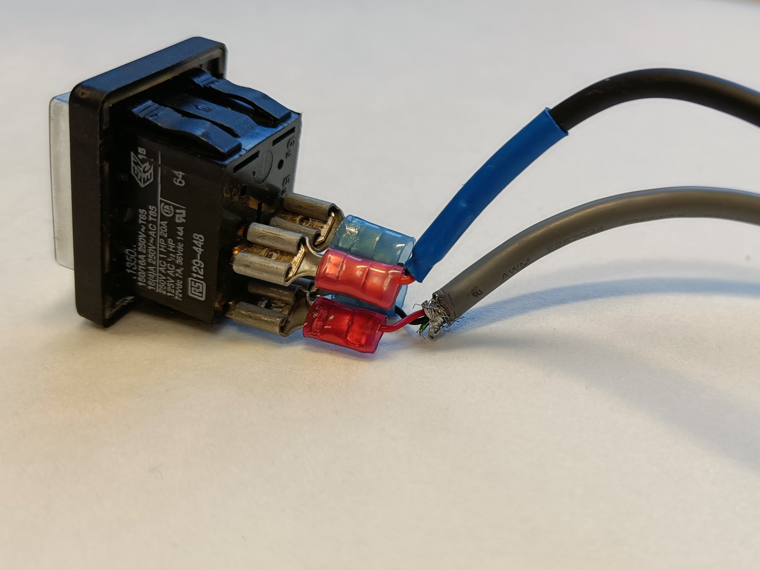
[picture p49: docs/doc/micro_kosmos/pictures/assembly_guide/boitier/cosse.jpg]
cosse
    

#### Relier un câble USB au ventilateur

???+ info

    Ce câble fera le lien entre le ventilateur et la raspberry. Brancher le ventilateur sur la carte pemet de l'alimenter et de le faire fonctionner.

- couper le câble USB à une trentaine de centimètre du branchement USB  
- enfiler la gaine thermo sur le câble (elle sera chauffée à la fin)   
- souder les câbles rouges ensemble et les câbles noirs ensemble  

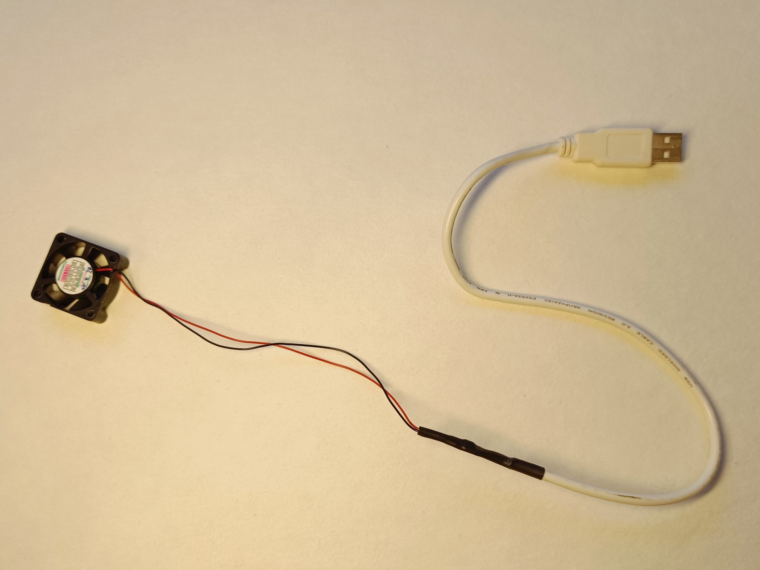
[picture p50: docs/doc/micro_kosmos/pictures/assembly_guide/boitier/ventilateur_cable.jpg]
ventilateur_cable
 

#### Relier des câbles de prototypage au bouton poussoir  

???+ info

    Ces câbles feront le lien entre le bouton poussoir et la raspberry.

- répéter les mêmes étapes que pour le câble USB et le ventilateur  

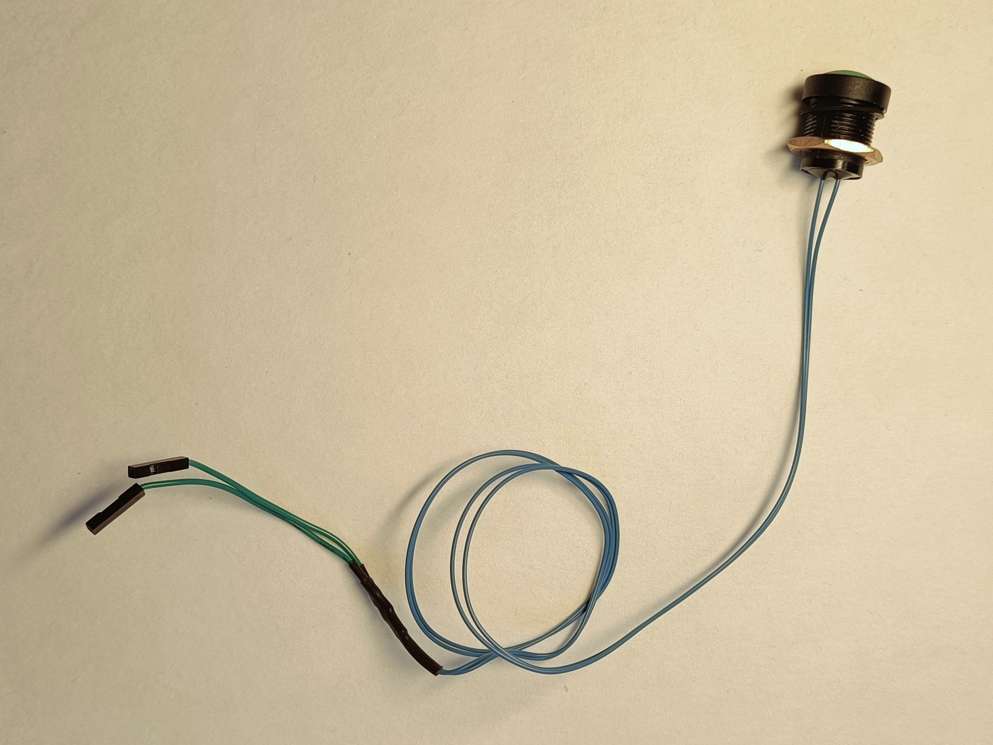
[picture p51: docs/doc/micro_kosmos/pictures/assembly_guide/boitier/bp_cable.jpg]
bp_cable


### Etape 2 - assemblage de la carte ethernet et de la carte raspberry  

???+ info

    La carte Ethernet permet de communiquer avec le caisson vidéo

- monter les supports sur la raspberry
- souder la barette noire sur la carte ethernet
- brancher carte ethernet sur la raspberry
- connecter la nappes sur l'éthernet et sur la raspberry  

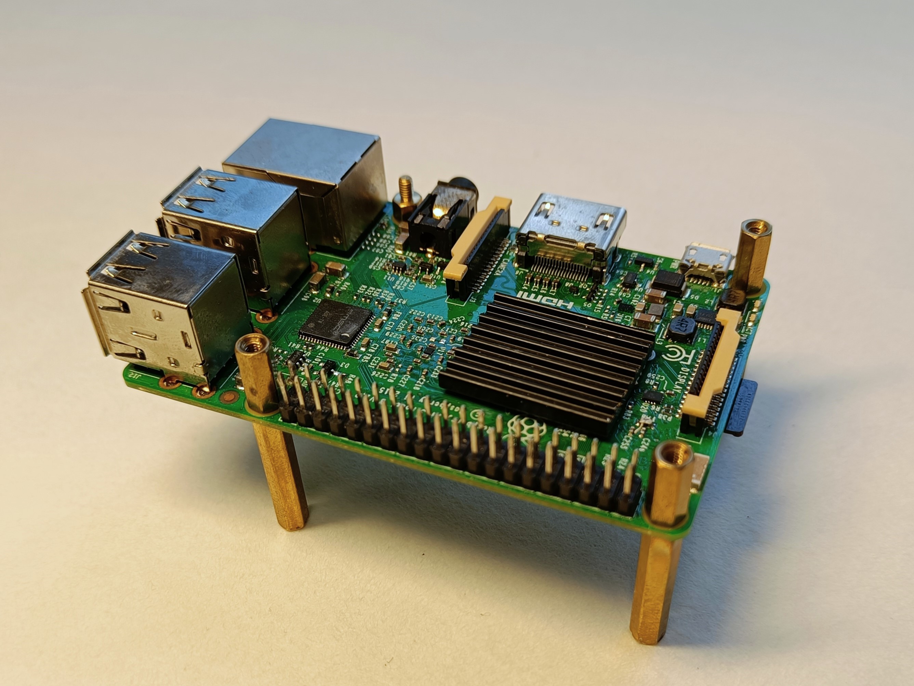
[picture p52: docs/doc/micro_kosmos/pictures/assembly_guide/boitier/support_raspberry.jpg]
support_raspberry
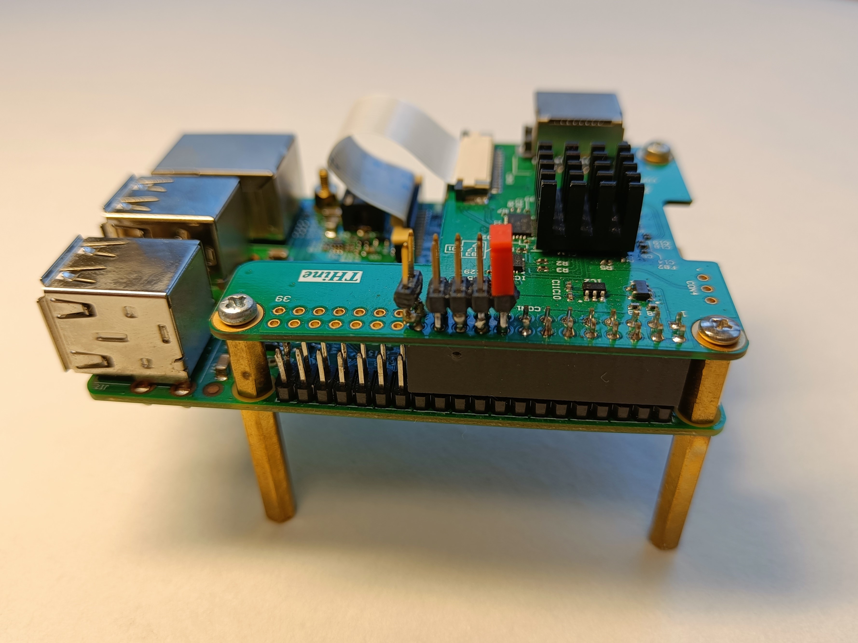
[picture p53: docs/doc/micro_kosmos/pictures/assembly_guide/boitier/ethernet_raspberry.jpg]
ethernet_raspberry
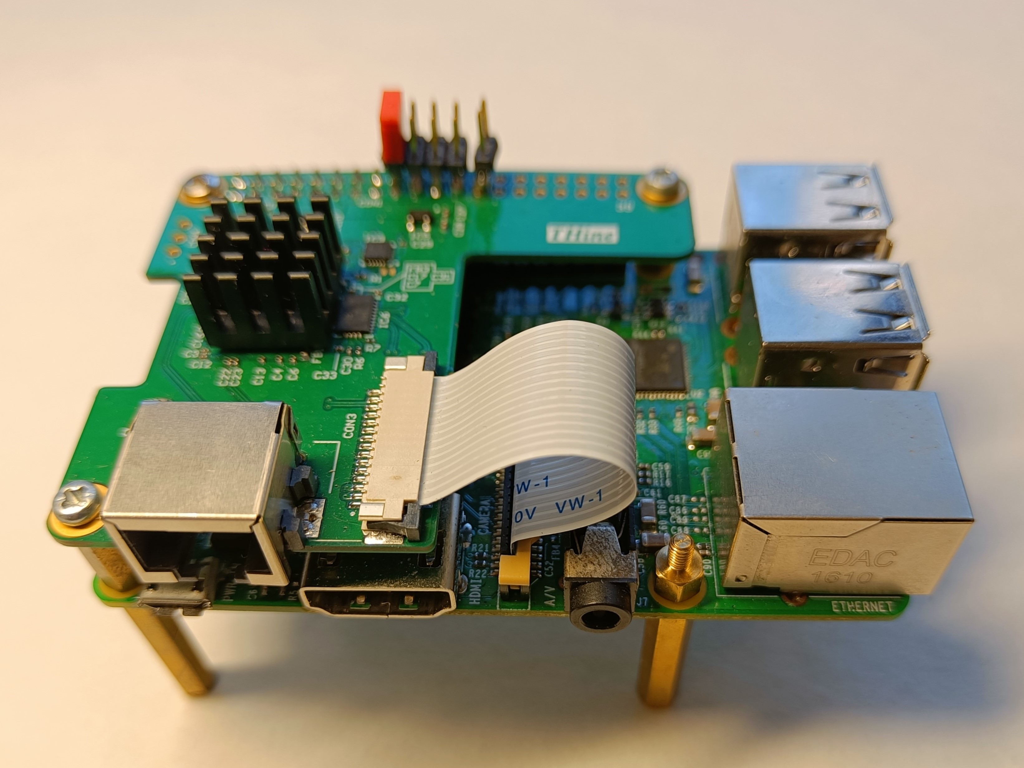
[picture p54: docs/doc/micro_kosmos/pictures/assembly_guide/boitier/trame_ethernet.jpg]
trame_ethernet
  

### Etape 3 - Perçage des côtés du boitier 

???+ info

    Ces ouvertures permettront de placer les connecteurs.

???+ tip

    Réaliser une ouverture supplémentaire pour que l'air puisse circuler et refroidir le système

    Si votre boitier est différent réfléchisser à la meilleur manière de l'organiser à l'intérieur

- percer des trous pour les connecteurs et leurs vis
  - (1) connecteur HDMI femelle/femelle : un trou de 22mm de diamètre et 2 trous de 3.5mm (vis)
  - (2) connecteur ethernet femelle/femelle : un trou de 27mm de diamètre
  - (3) bouton poussoir : un trou de 16mm de diamètre
  - (4) commutateur : un trou de 29mm * 22mm
  - (5) ventilateur : un trou de 26mm de diamètre et 4 trous de 3mm (vis)
  - (6) aération : un trou de 20mm de diamètre
  - (7) fixation raspberry au boitier : 4 trous de 2.5mm (vis)
  
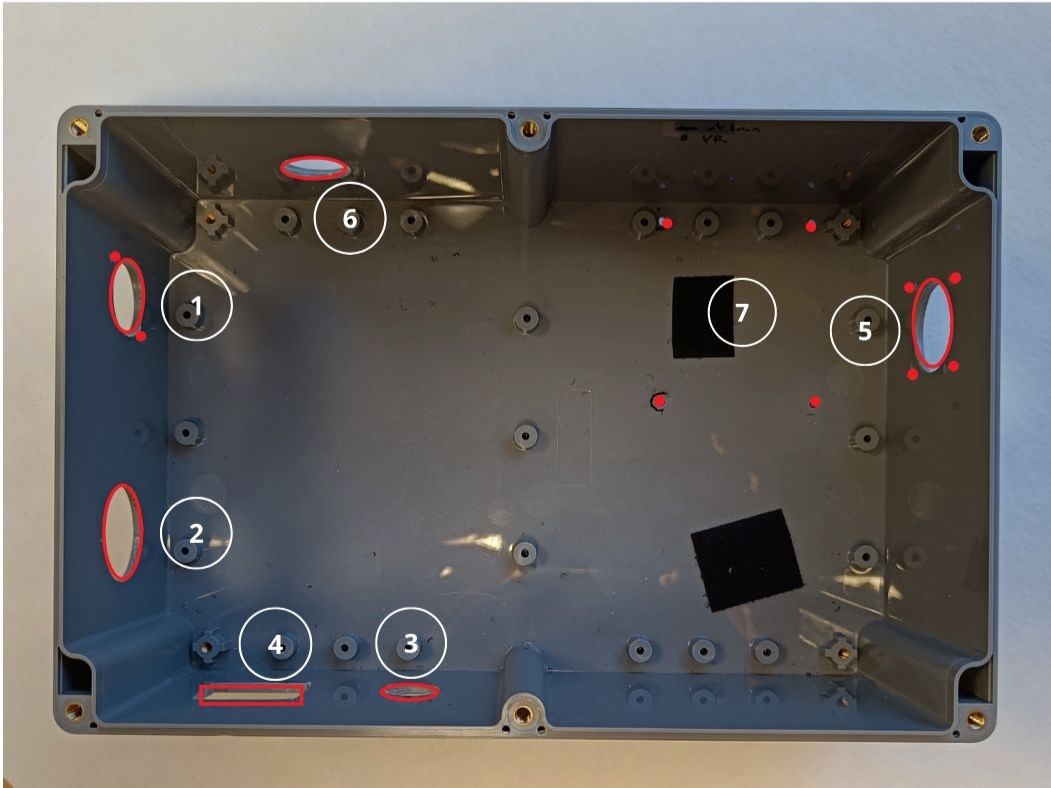
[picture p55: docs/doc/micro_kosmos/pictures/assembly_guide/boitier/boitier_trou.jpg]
boitier_trou


### Etape 4 - Fixation du receiver gaming, de la carte gps et du ventilateur dans le boitier

- fixer le receiver gaming et la carte gps à l'aide de velcro
- visser le ventilateur
- brancher le câble micro USB sur la carte gps, il sera difficile d'accès lorsque la carte raspberry sera fixée

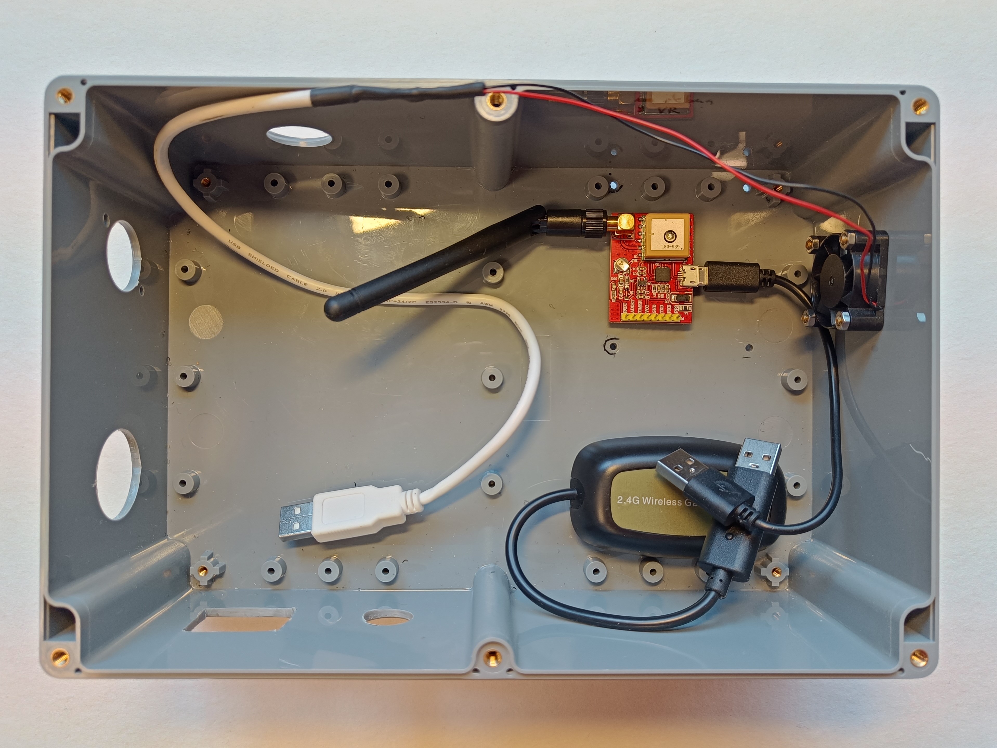
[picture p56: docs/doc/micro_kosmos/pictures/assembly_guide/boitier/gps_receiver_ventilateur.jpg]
gps_receiver_ventilateur


 ### Etape 5 - Fixation du clavier et de la batterie dans le couvercle  
 - fixer le clavier et la batterie à l'aide de velcro

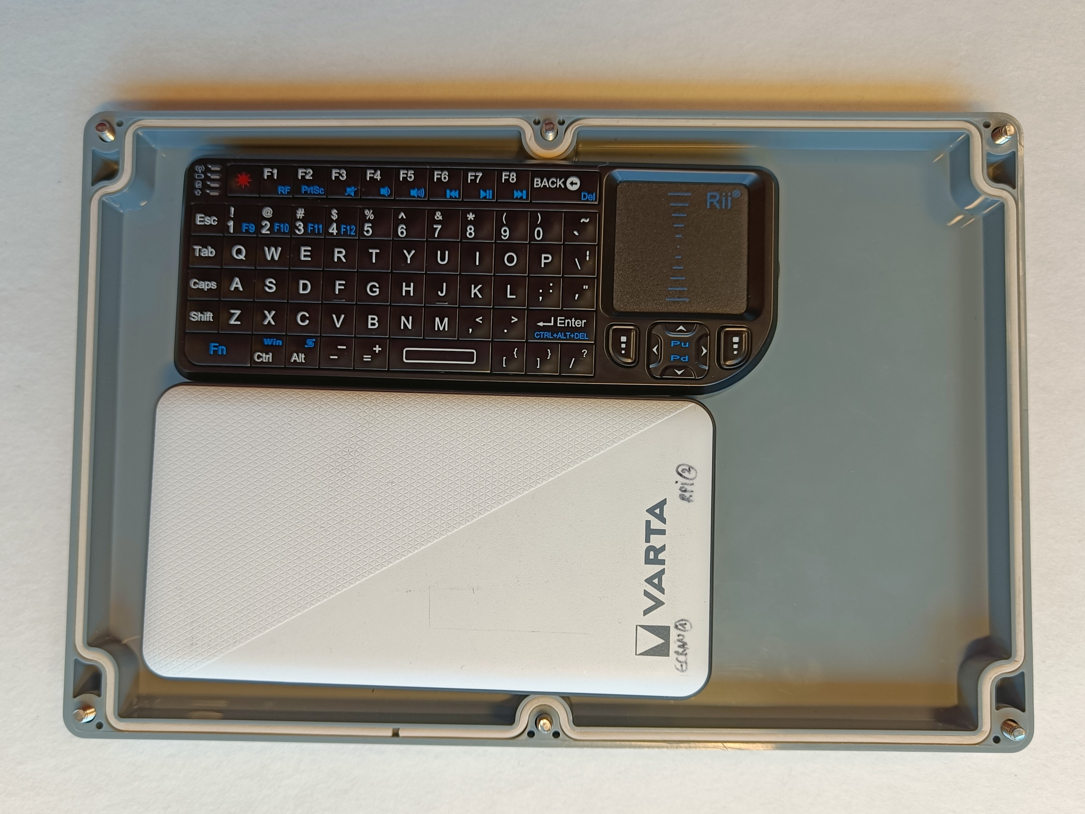
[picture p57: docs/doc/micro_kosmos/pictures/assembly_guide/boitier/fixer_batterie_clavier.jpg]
fixer_batterie_clavier
 

### Etape 6 - Fixation de la raspberry au boitier

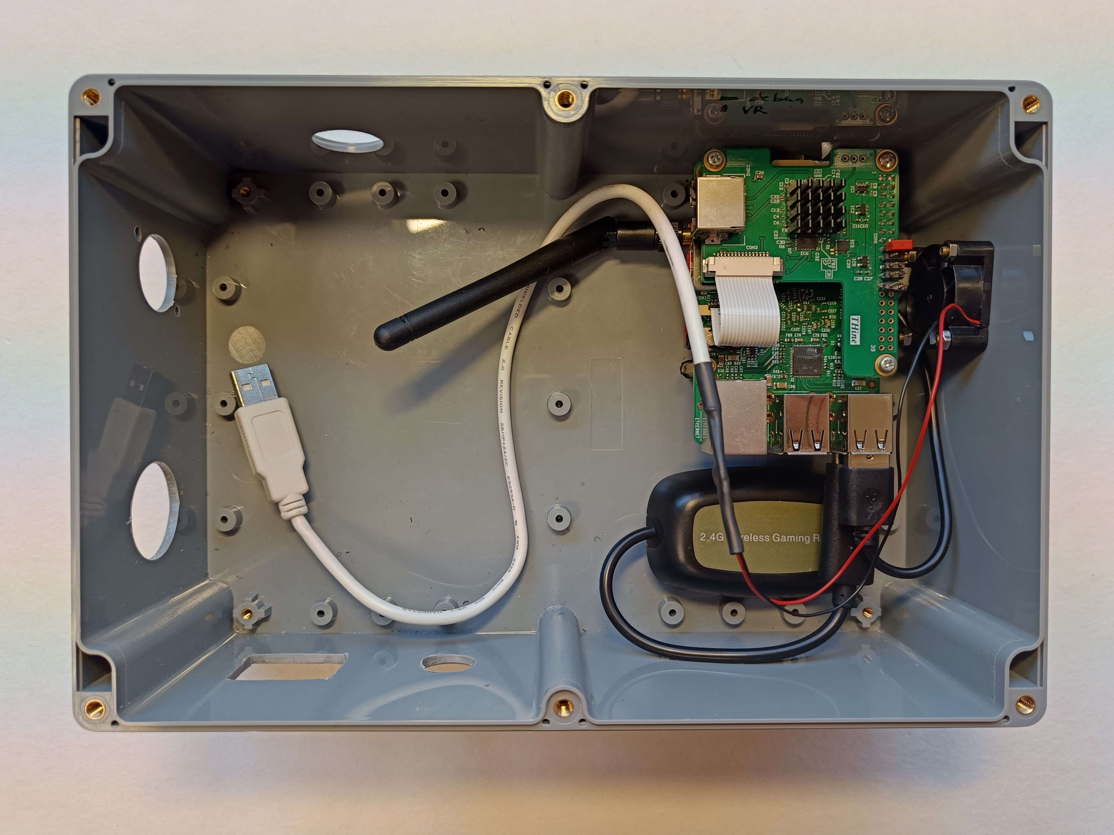
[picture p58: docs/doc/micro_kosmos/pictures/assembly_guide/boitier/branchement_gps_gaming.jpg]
branchement_gps_gaming


### Etape 7 - Fixation de l'interrupteur, du bouton poussoir, des connecteurs et réalisation des branchements

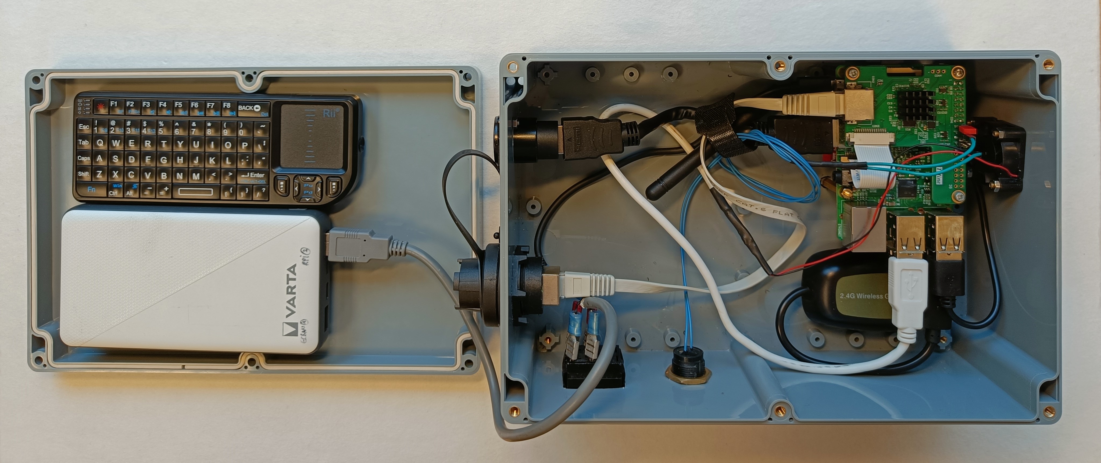
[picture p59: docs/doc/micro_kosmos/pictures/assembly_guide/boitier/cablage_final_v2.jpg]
cablage final


## 2. Assemblage du caisson vidéo

??? Matériel

    [Matériel caisson vidéo](../../../../hardware/micro_kosmos/04_materiel_caisson_video.md)

## 3. Assemblage du trépried

??? Outils  
    * imprimante 3D {[Etape 1](assembly-guide_fr.md#etape-1-impression-3d)}
    * foret M3, M6 {[Etape 2](assembly-guide_fr.md#etape-2-assemblage-de-la-partie-inferieur-du-trepied)}
    * meuleuse {[Etape 2](assembly-guide_fr.md#etape-2-assemblage-de-la-partie-inferieur-du-trepied)}

??? Matériel

    [Matériel trépied](../../../../hardware/micro_kosmos/07_materiel_trepied.md)

### Etape 1 - Impression 3D
Imprimer les pièces inférieurs et supérieurs du socle ainsi que les pièces de maintient du caisson vidéo.

### Etape 2 - Assemblage de la partie inférieur du trépied
 - Découper le tube en aluminium de manière à obtenir trois segments d'environ "500mm". Ces segments formeront les trois pieds.
 - Couper les extrémitées de chaque segment en biais (environ 45°).
 - Percer les tubes avec un foret de 6mm à environ 20cm du bord (un peu plus que la longueur des plombs que vous avez choisis). Ceci est la partie basse des pieds du trépied.
 - Percer deux trous à l'autre extrémité du tube. Un avec un foret de 3mm à environ 20mm du bord du tube et un autre à 100mm du bord. Les trous doivent traversés le tube de part et d'autre pour pouvoir y insérer des vis.
 - Percer les plombs avec un foret de 3mm perpendiculairement au trou déjà existant. Ce trou permettra de faire passer le serre câble pour maintenir la partie basse du plomb sur le tube.
 - Fixer les plombs sur la partie basse des pieds. Visser et ajouter un serre câble comme ci-dessous.

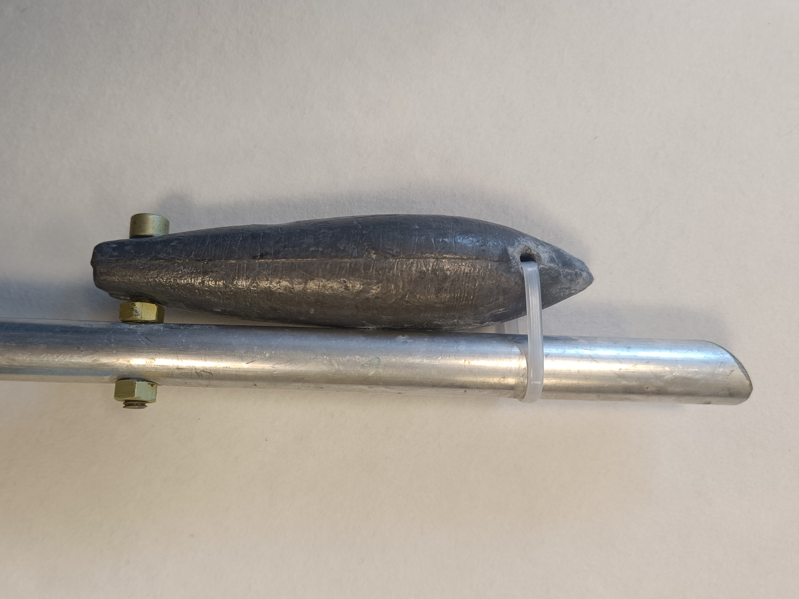
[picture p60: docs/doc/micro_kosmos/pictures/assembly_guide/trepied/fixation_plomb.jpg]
fixation_plomb


 - Couper le tête des clous, insérer les dans les trous réalisés à 100mm de la partie haute et plier les bords qui dépasse contre le tube. Ces clous servent de butées et empèchent la partie inférieur du socle de glisser.  
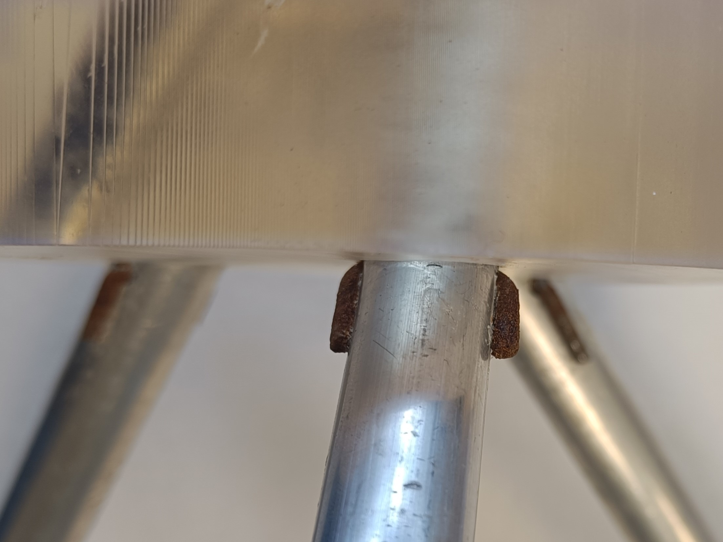
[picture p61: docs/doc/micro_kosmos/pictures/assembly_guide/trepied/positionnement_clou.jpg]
positionnement_clou


 - Insérer la partie haute des tubes dans le socle inférieur du trépied imprimée en 3D  
 - Faire passer un fil de fer dans les trous réalisés à 20mm de la partie haut. Ce fil sert également de butée et empèche la partie inférieur du socle de glisser hors de la pièce 3D.     
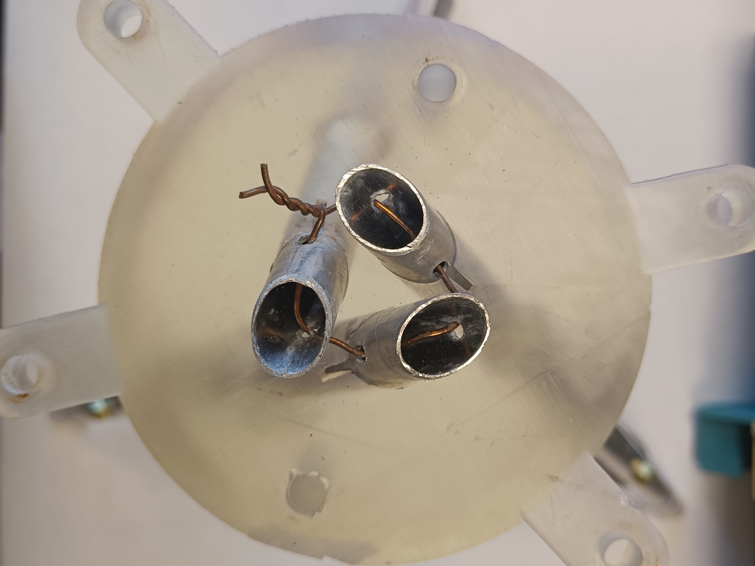
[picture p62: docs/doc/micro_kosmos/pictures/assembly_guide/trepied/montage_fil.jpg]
montage_fil

  
### Etape 3 - Assemblage de la partie supérieur du trépied

???+ info

    Un ber est une structure initialement placée sous les navires pour les supporter lors de la construction ou la réparation.

 - Coller les bandes de mousse à l'intérieur des bers. Attention à laisser les trous prévus pour les vis libres.
 - Percer 2 trous dnas la plaque métalique avec un foret M4 et un trou avec un foret M10. Il faut que les trous correspond aux trous déjà présent sur la partie centrale du socle supérieur imprimé en 3D;
 - Positionner la plaque métallique au dessus de la partie supérieur du socle et fixer l'anneau d'accroche M10 à la partie supérieur du socle.  
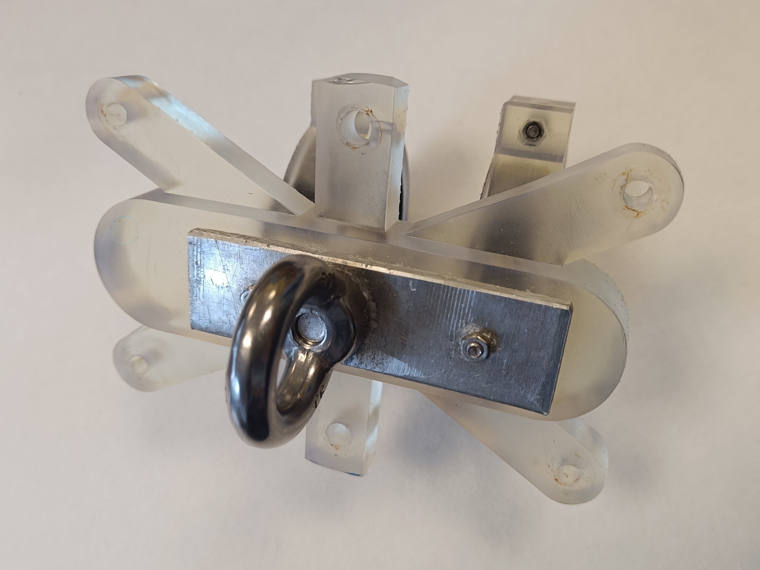
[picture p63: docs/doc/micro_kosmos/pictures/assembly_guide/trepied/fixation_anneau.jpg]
fixation_anneau

 
 - Visser le ber supérieur à la partie supérieur du socle avec des vis M4  
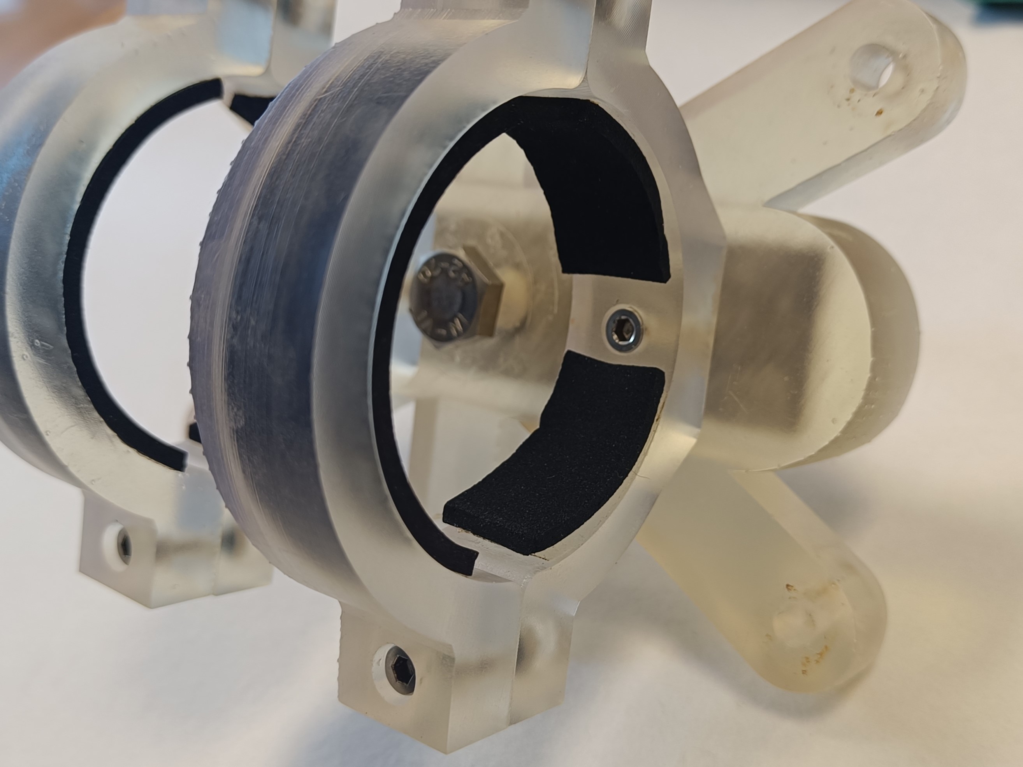
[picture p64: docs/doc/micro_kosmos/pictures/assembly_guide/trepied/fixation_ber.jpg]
fixation_ber


 - Visser le ber inférieur pour former le support du caisson vidéo. (Ne serrer pas avant d'avoir inséré le caisson vidéo.)

### Etape 4 - Assemblage de la partie haute et de la partie basse du trépied
 - Découper la tige filetée de manière à avoir 2 segments de 170mm et 4 segements de 145mm
 - inserrer des écrous nylstop de chaque côté des tiges filetées  
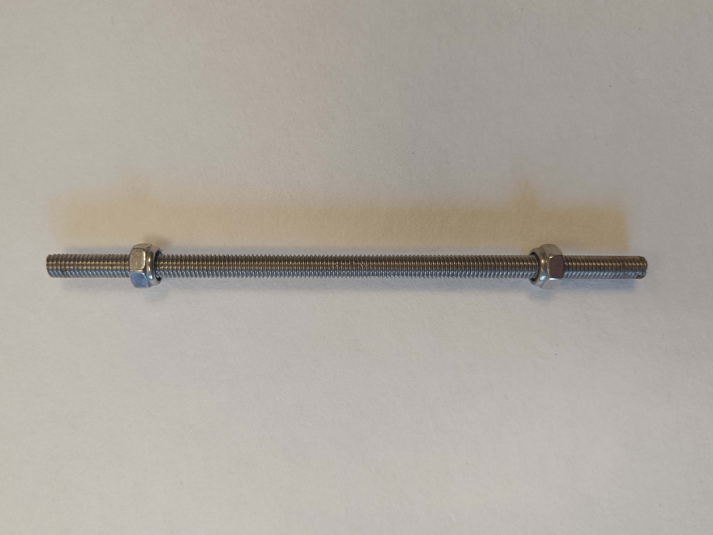
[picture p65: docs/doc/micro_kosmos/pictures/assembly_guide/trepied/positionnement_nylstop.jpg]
positionnement_nylstop


 - Lors du montage des écrous, placer des rondelles de chaque côté de la pièce imprimée pour la protéger. Insérer les tiges filetées dans le socle inférieur puis visser un écrou avec oreilles en dessous.  
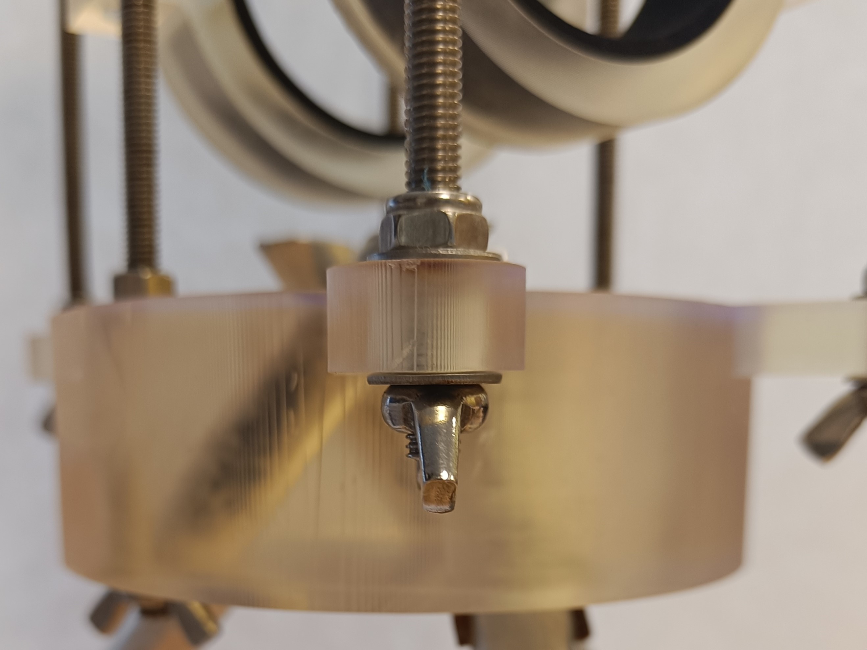
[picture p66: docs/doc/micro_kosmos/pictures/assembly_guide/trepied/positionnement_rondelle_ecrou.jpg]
positionnement_rondelle_ecrou


 - Insérer des rondelles sur les tiges puis positionner la partie supérieur du socle. Ajuster les écrous de manière à ce que le socle vienne se poser horizontallement.

 - Comme pour la partie basse, fixer le haut avec des écrous à oreilles  
   
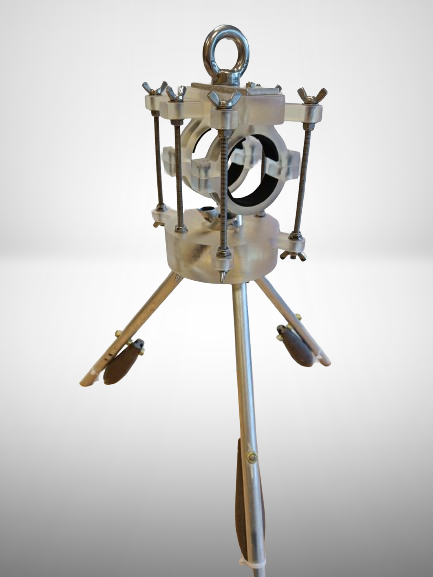
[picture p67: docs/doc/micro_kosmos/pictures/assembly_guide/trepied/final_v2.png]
imagefinale
   
   
## 4. Assemblage du casque

??? Outils
  
    * foret M2 {[Etape 3](assembly-guide_fr.md#etape-3-percer-la-coque-exterieur-du-casque)}

??? Matériel

    [Matériel casque](../../../../hardware/micro_kosmos/05_materiel_casque.md)
    
### Etape 1 - Impression 3D
Imprimer les pièces de suport de l'écran ainsi que celles du support de batterie.

### Etape 2 - Assemblage écran
 - Visser l'écran à son support
 - Mettre de la mousse sur les diagonales du support pour caler la carte
 - brancher un cable micro usb  
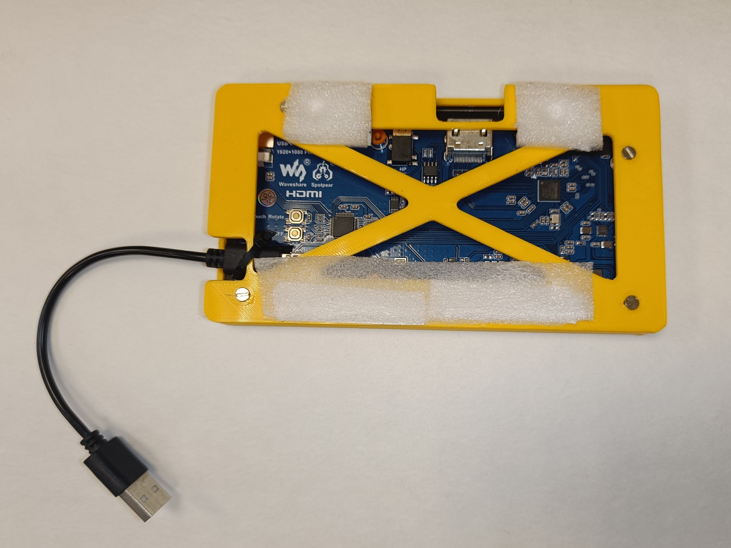
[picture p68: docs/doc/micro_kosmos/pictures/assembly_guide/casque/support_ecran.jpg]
support_ecran


### Etape 3 - Percer la coque extérieur du casque
 - Réaliser une ouverture sur le haut du casque pour pouvoir accéder à la prise hdmi de l'écran
 - Percer également l'avant de la coque pour pouvoir visser la partie basse du support de la batterie.  
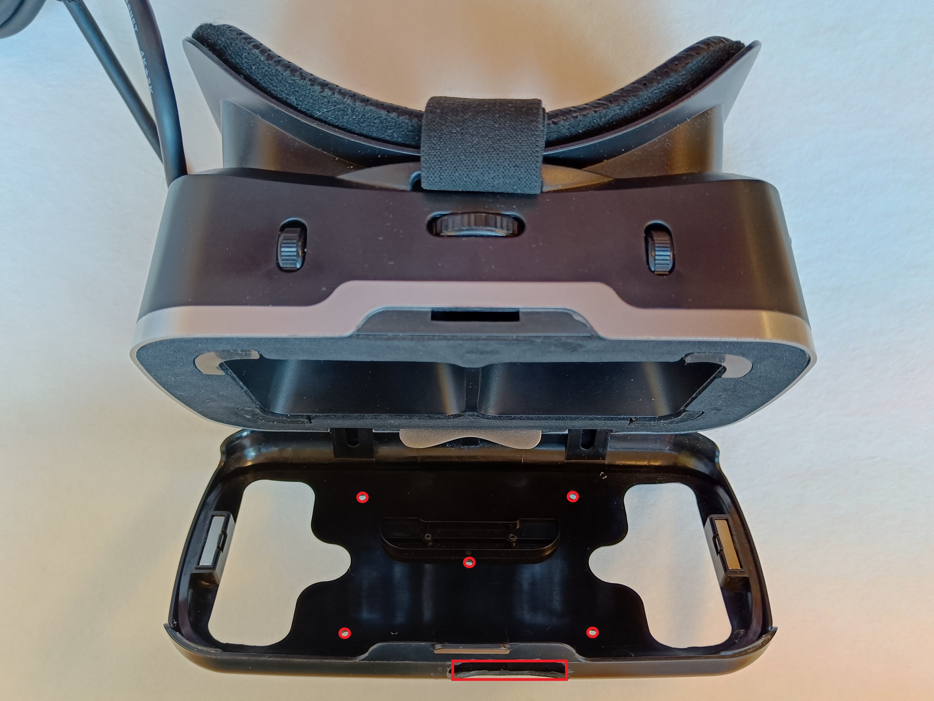
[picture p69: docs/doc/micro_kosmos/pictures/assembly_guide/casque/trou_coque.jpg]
trou_coque


### Etape 4 - Assemblage de la batterie

???+ info

    Sur les supports la mousse permet de caler les éléments.

 - Mettre de la mousse sur les diagonales du support inférieur et supérieur de la batterie

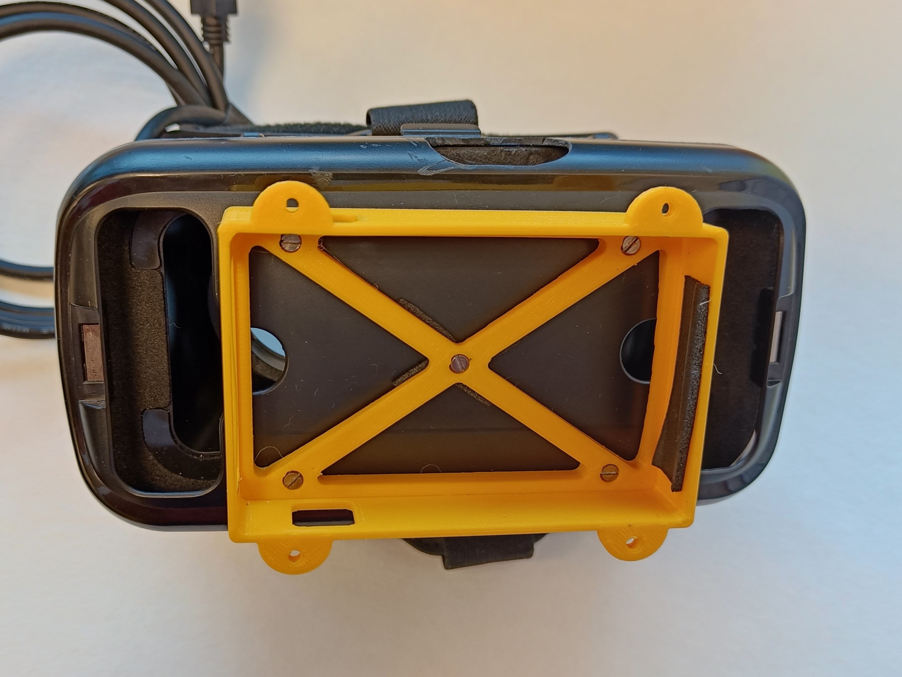
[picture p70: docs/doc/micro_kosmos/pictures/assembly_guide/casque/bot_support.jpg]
bot_support

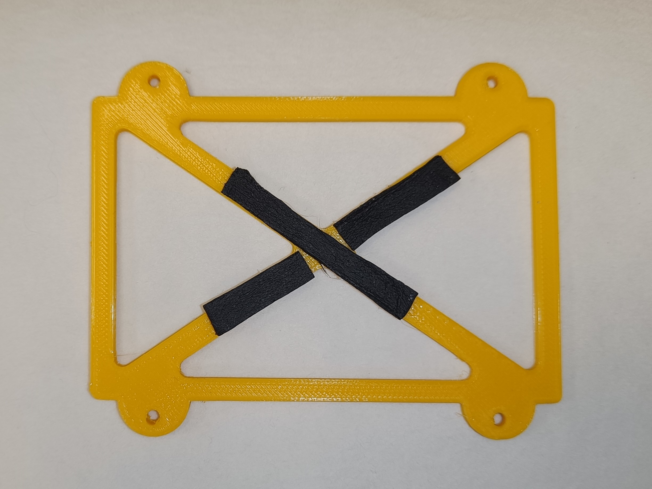
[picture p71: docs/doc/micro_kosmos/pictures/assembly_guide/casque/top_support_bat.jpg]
top_support_bat


 - Visser la partie basse du support de la batterie au casque
 - Placer la batterie à l'intérieur du support
 - Visser la partie supérieur du support pour le fermer

### Etape 5 - Asssemblage final
 - Mettre l'écran dans le casque
 - Fermer le casque
 - Brancher le cable hdmi et relier le cable usb à la batterie
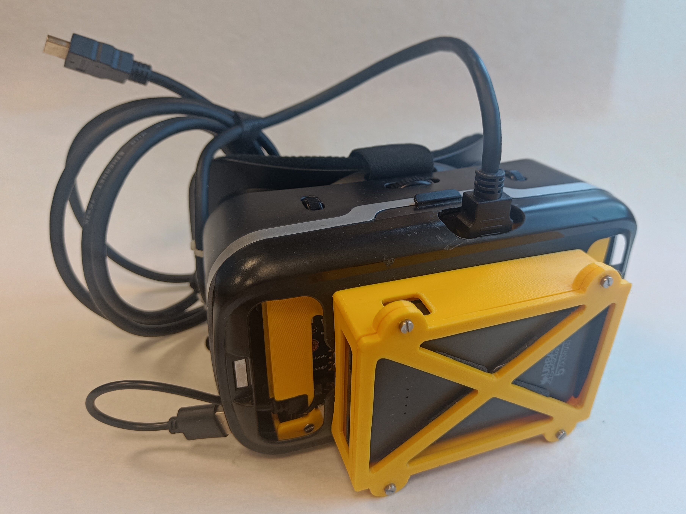
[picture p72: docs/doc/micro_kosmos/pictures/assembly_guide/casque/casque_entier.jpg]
casque_entier


## 5. Assemblage du câble

??? Outils
    
    * ex1
    * ex2
  
??? Matériel

    [Matériel cable](../../../../hardware/micro_kosmos/03_materiel_cable.md)

## 6. Assemblage de la paravane

??? Outils
  
    * ex1
    * ex2
  
??? Matériel

    [Matériel paravane](../../../../hardware/micro_kosmos/06_materiel_paravane.md)

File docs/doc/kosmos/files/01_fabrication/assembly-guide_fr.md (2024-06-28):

icon:material/cog
# KOSMOS_3.0

## 1/ Assemblage des composants intérieurs au caisson

### 1.1 Assemblage de la caméra :

* Rassembler, la Picam HQ, sa nappe \(câble plat\), la structure caméra I3, 4 vis M2,5\*10mm et 4 rondelles M2,5.

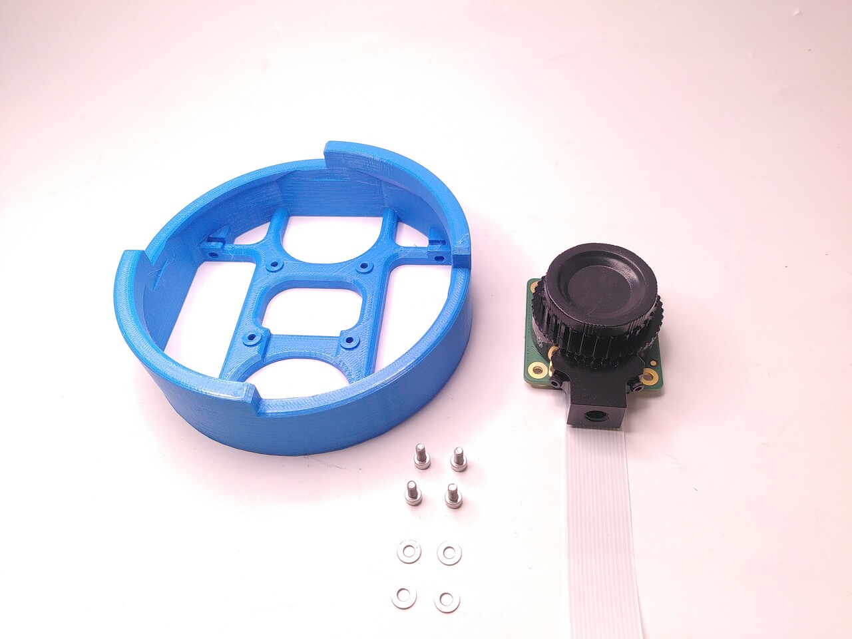
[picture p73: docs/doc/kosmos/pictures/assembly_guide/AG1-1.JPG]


* A l'aide d'une clé alen de 2mm, visser la caméra sur I3 à l'aide des 4 vis M2,5 et 4 rondelles. La caméra doit être positionnée comme présentée sur la photo ci dessous. La sortie de la nappe du côté opposé aux fixations.

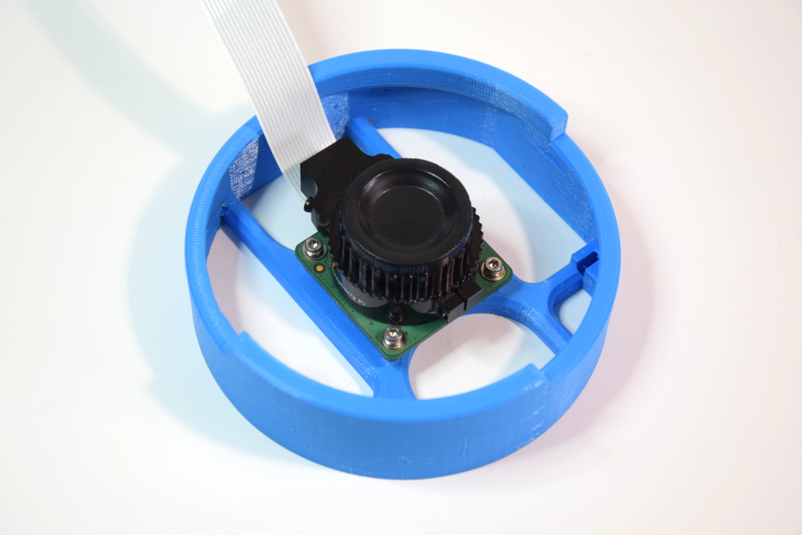
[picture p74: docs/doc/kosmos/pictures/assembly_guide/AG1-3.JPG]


### 1.2 Installation du convertisseur et de l'ESC :

* Rassembler, le convertisseur 12V vers 5V, la structure S1, l'ESC (contrôleur moteur brushless), 2 vis M3\*8mm et 2 colsons. 

* Visser avec les deux vis M3 le transformateur 12V vers 5V (Chuangruifa). Veiller à positionner les câbles vers l'intérieur de la platine S1.

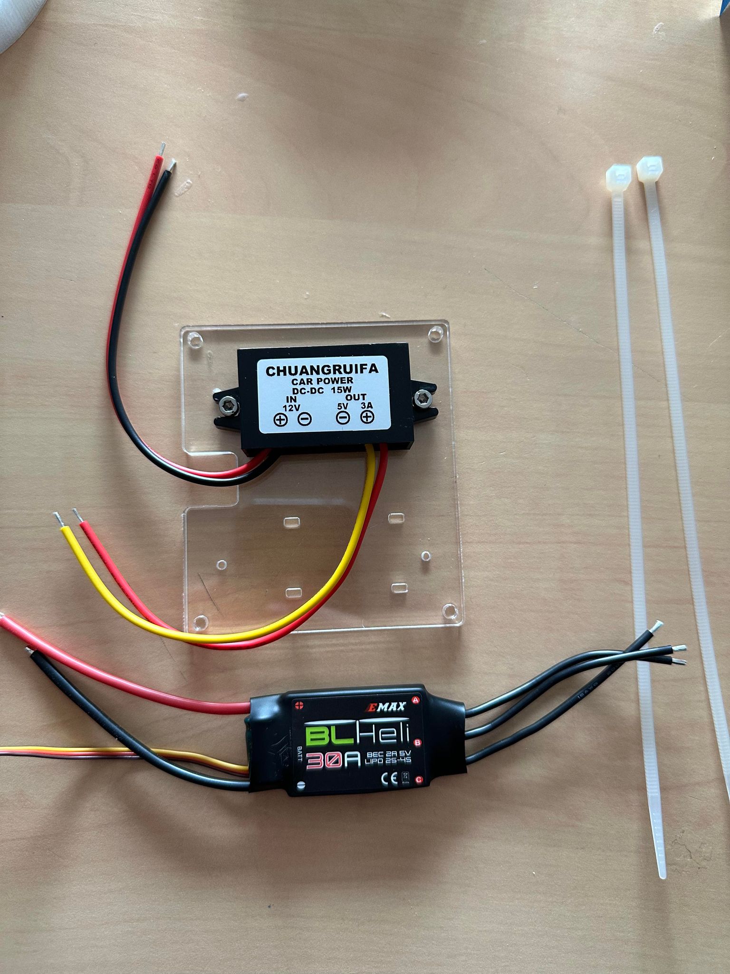
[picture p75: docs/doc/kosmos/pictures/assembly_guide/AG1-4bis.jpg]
AG1-4bis


* Installer l'ESC sous le convertisseur à l'aide des deux colsons. On veillera à positionner les câbles du BEC (2 fils sertis) et d'alimentation du coté de l'encoche de S1. Placer l'ESC avec les écritures vers la structure et les composants à l'opposé. L'ESC ne peut pas toucher la structure donc serrer bien les colsons à la structure pour que l'ESC ne puisse pas bouger.

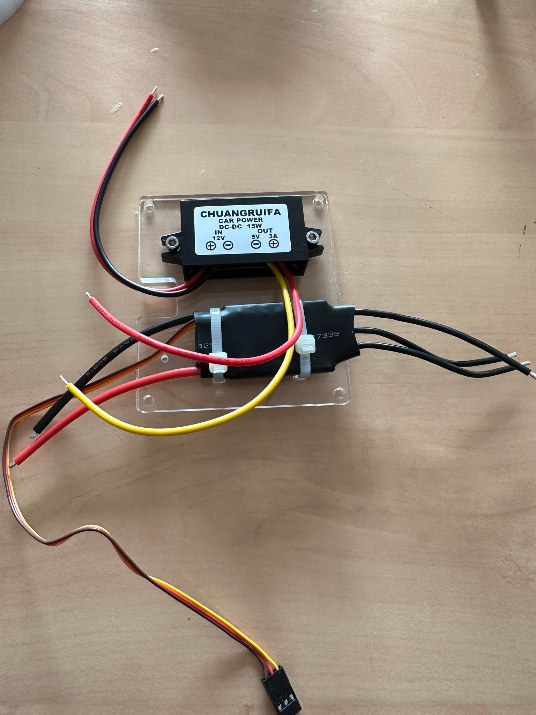
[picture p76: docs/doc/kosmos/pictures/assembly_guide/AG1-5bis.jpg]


### 1.3 Assemblage de la Raspberry :

* Rassembler, le support de la Raspberry, structure S1, la Raspberry Pi 4 modèle B, 4 entretoises en laiton M2,5\*10, 4 vis M2,5 6mm et 4 rondelles M2,5.

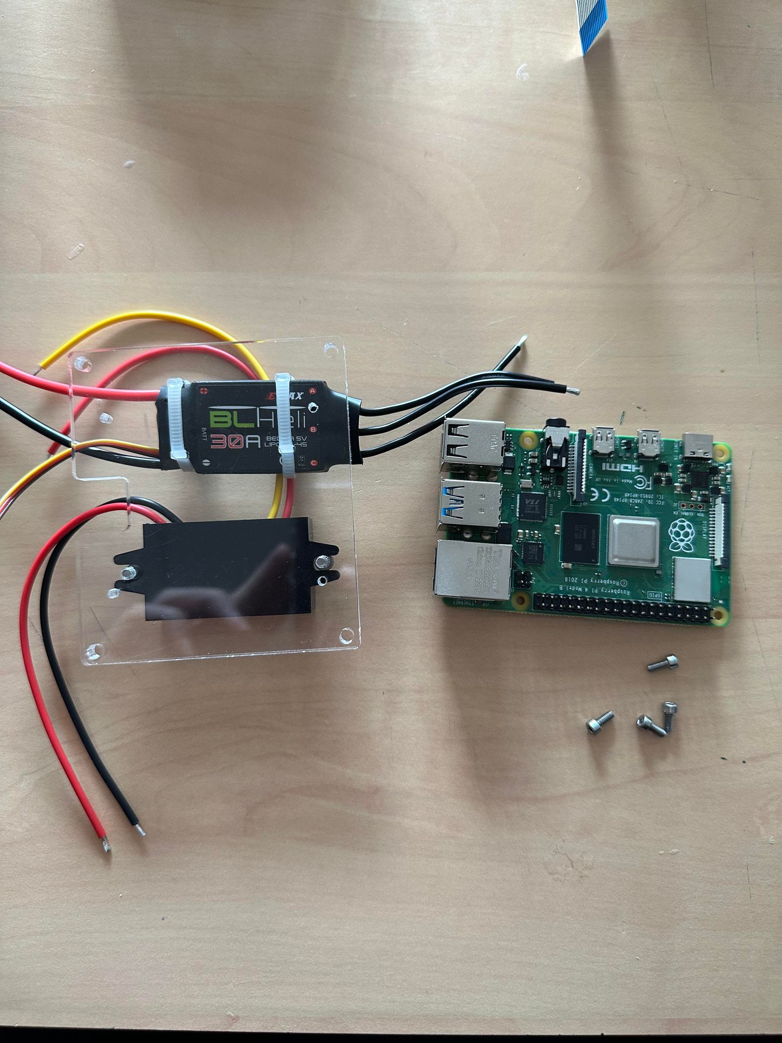
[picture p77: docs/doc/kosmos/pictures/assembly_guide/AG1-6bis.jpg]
AG1-6bis


* A l'aide d'une pince plate, visser les 4 entretoises sur les trous R1, R2, R3 et R4 \(cf photo ci dessous\).

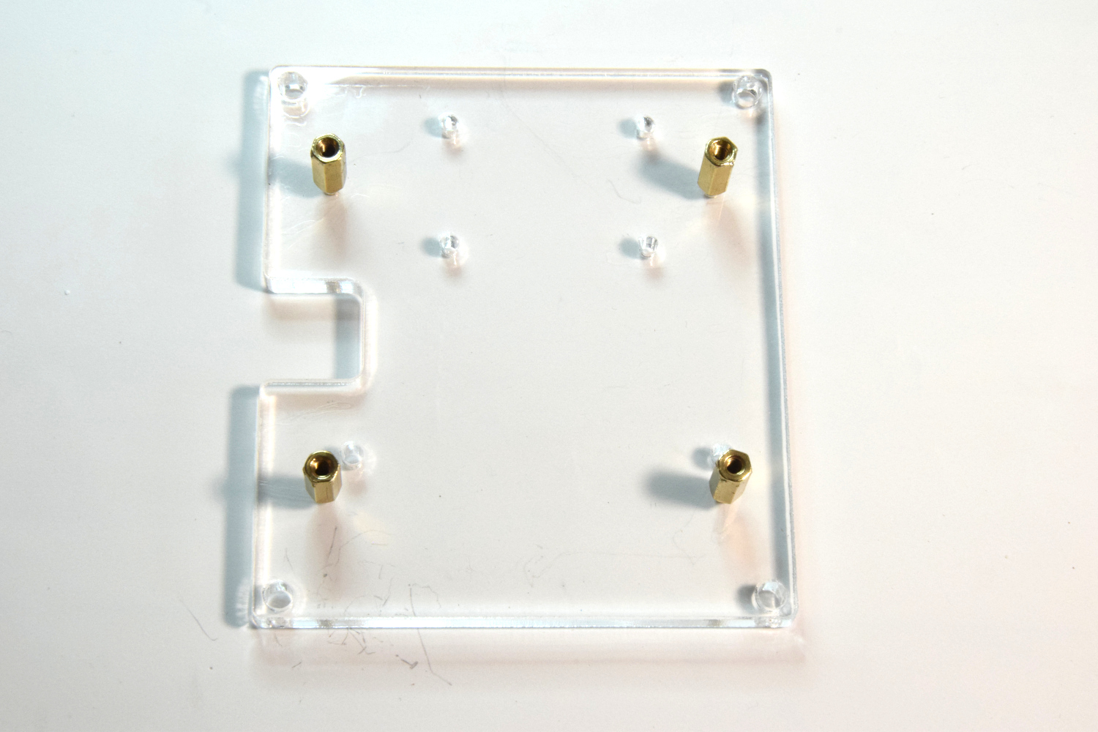
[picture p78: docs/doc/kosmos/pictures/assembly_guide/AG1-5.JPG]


* Enfin, à l'aide d'une clé alen 2mm, visser la raspberry sur son support \(cf photo ci-dessous\). Veiller au sens, l'encoche de la structure S1 doit être à l'opposée des connecteurs USB de la Raspberry. Disposer les rondelles entre la Raspberry Pi et les vis.

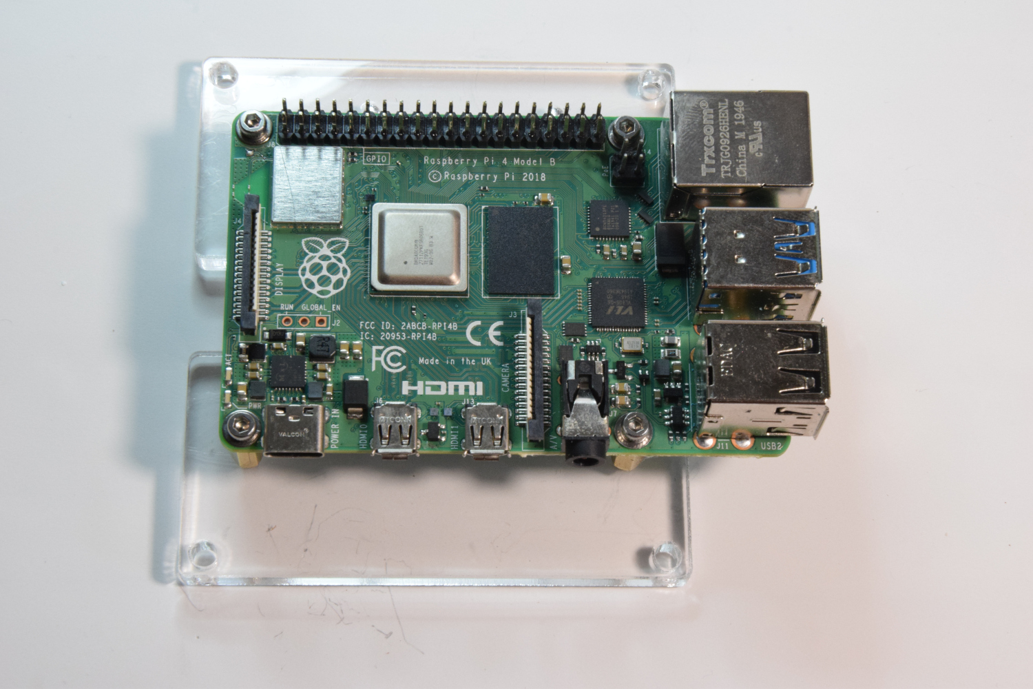
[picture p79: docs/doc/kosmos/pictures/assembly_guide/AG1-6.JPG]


### 1.4 Finalisation de l'assemblage interne :

* Rassembler la Raspberry et son support, la caméra et sa structure, la structure I1 et I2, 8 ecrous M3, 6 vis M3\*10mm, et 2 vis M3\*15mm, 2 vis M4\*30mm, 2 écrous M4.

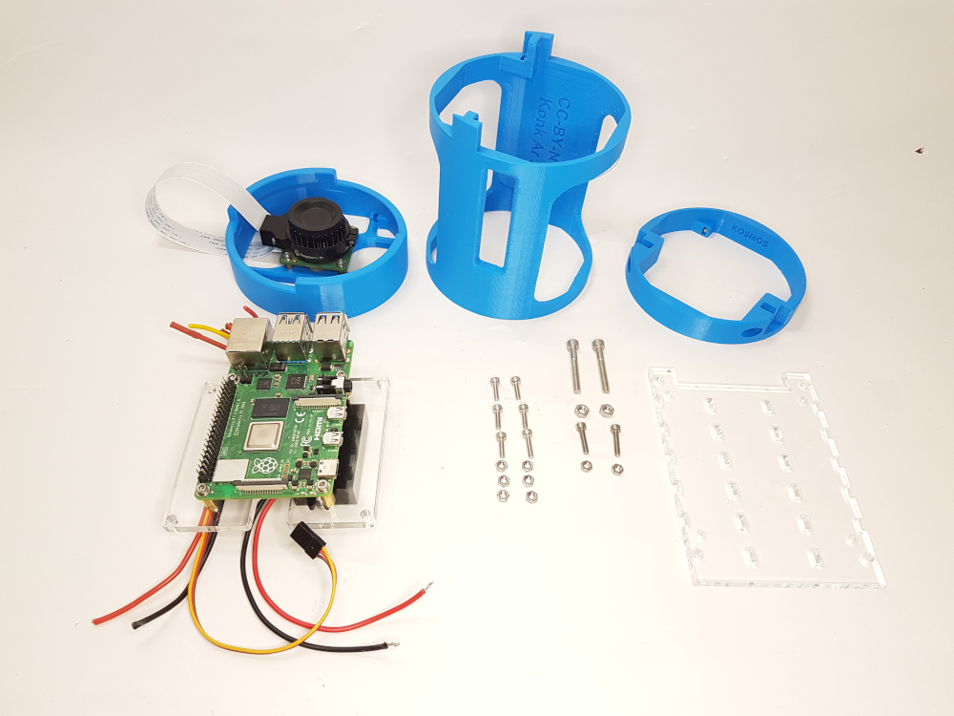
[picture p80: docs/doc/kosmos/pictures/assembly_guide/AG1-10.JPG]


* Insérer 4 écrous M3 dans les fentes prévus à cet effet sur la structure I1 \(cf photo ci dessous\)

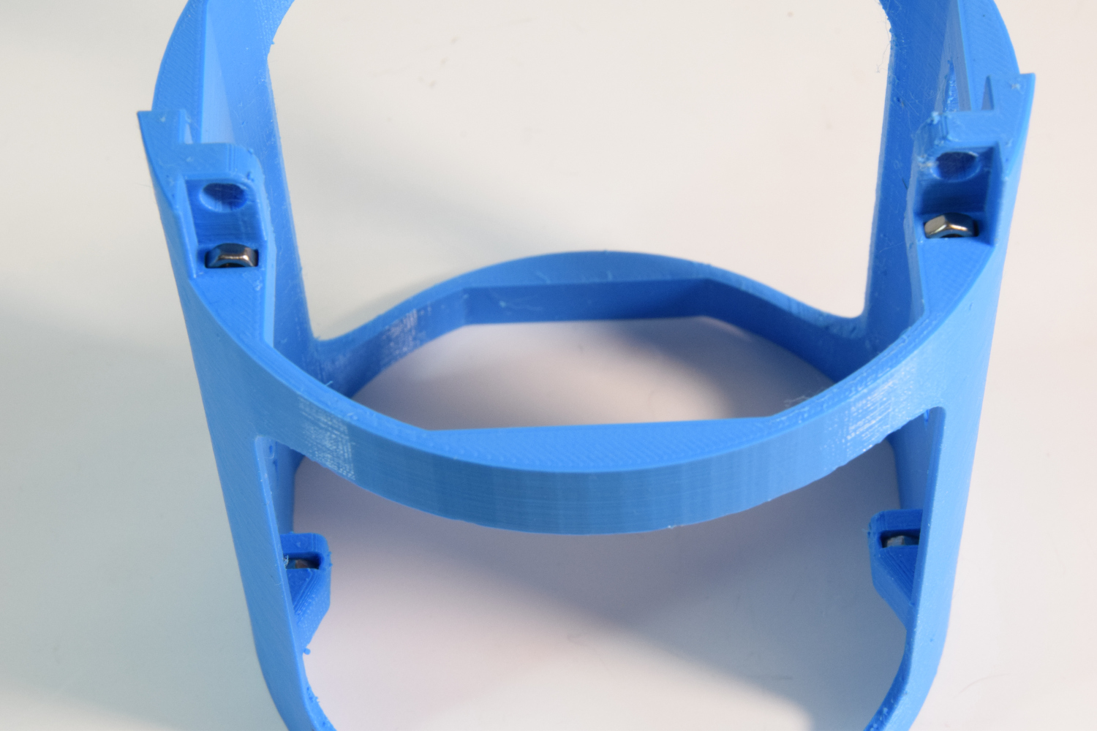
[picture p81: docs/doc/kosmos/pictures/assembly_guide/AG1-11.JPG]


* Visser la carte Raspberry pi 4 et son support S1 sur la structure I1 à l'aide de deux vis M3\*15mm en haut (Côté opposé aux connecteurs USB) et deux vis M3\*10mm en bas (côté des connecteurs USB). Attention au sens de la Raspberry \(cf photo ci-dessous\).

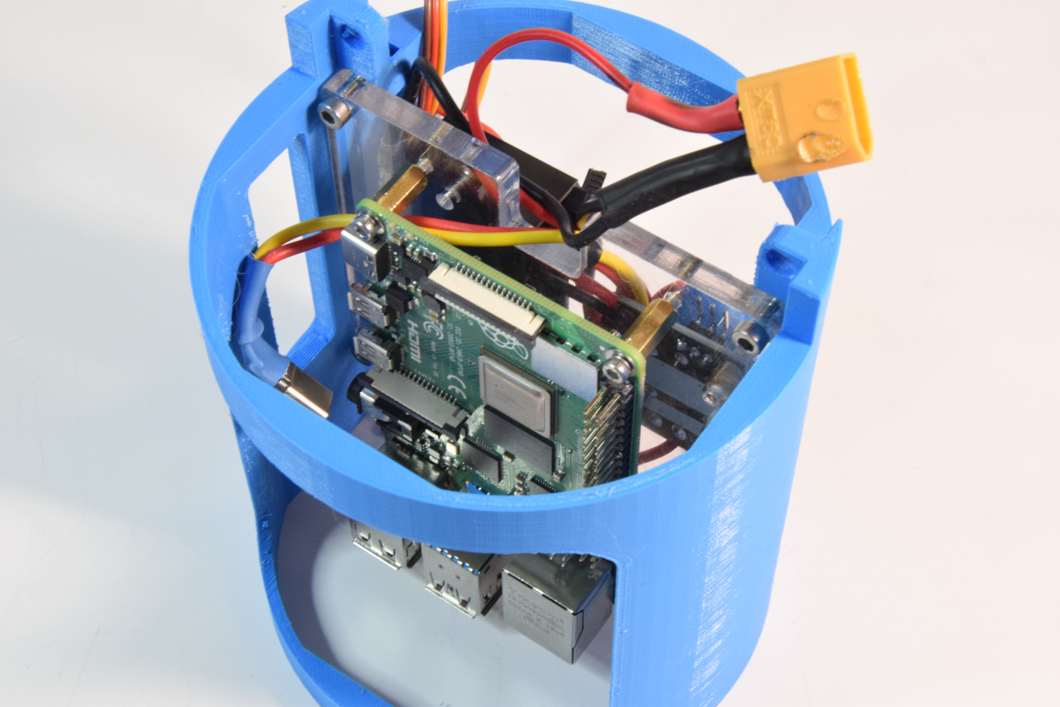
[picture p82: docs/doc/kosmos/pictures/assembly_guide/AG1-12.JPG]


* Insérer 2 écrous M3 sur la structure I2 et 2 autres sur la structure caméra I3.
* Visser la plaque en PMMA S2 à l'aide de 2 vis M3\*10mm sur la structure batterie I2. Attention à bien veiller au sens.

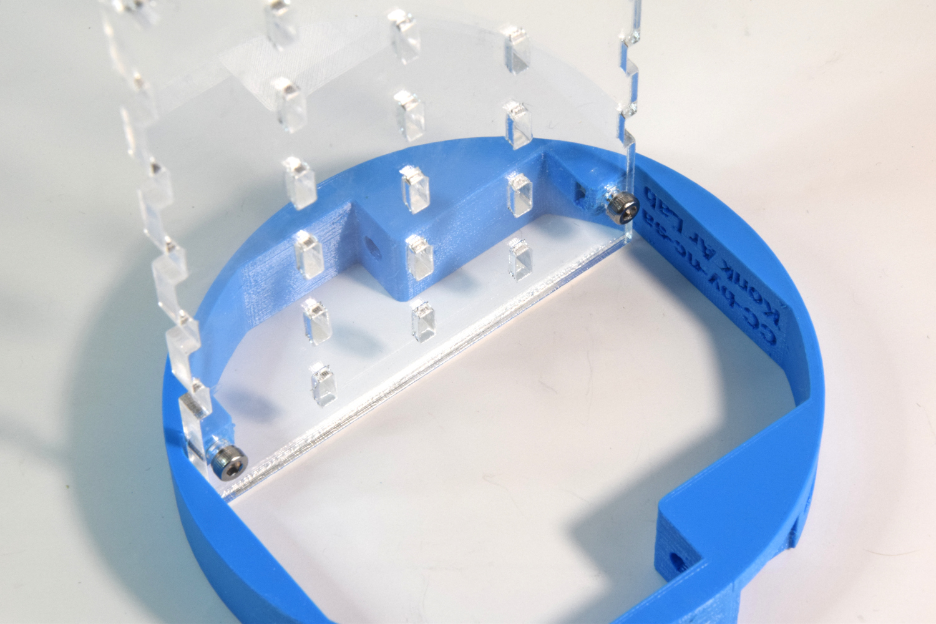
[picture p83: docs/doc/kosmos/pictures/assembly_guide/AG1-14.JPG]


* Visser l'autre extrémité de la plaque de PMMA S2 sur la structure caméra I3.

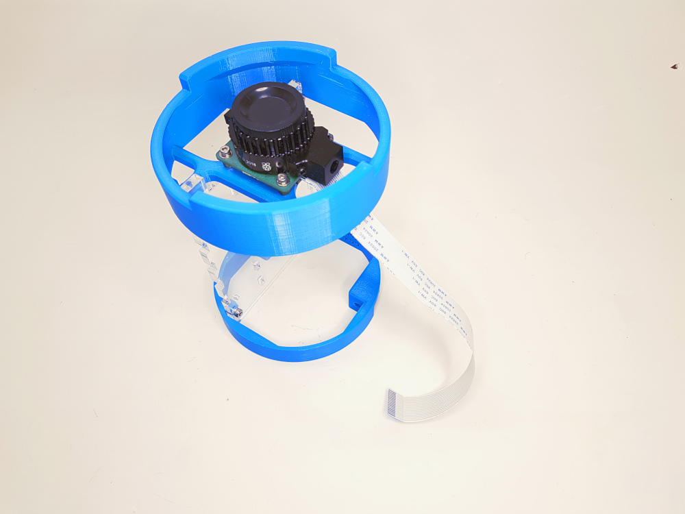
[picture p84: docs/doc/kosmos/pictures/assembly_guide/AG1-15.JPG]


* Assembler les deux parties précédemment assemblées. Veiller à passer les câbles au travers des pièces et à ne pas les abimer.
* Visser ces deux parties au moyen de deux vis M4\*30mm et de deux écrous M4. Serrer de manière à ce que la tête de vis ne puisse géner l'insertion du KOSMOS dans le tube.

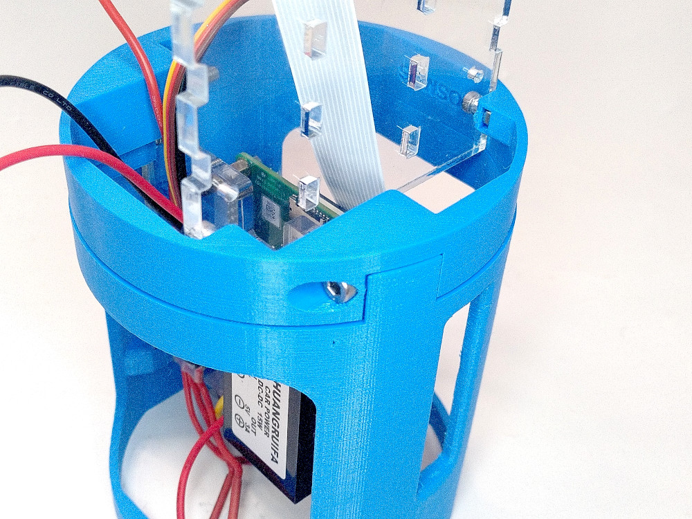
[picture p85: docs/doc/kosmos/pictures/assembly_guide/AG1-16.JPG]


* Brancher la nappe de la PiCam à la carte Raspberry. La carte porte une inscription "CAMERA" au dessus de ce connecteur , il est à proximité des connecteurs USB. Pour la connexion, lever \(sans ôter\) la partie noir du connecteur et placer le côté bleu de l'’extrémité de la nappe face aux connecteurs USB. Refermer la pièce de serrage noir. \(cf photos ci dessous\)

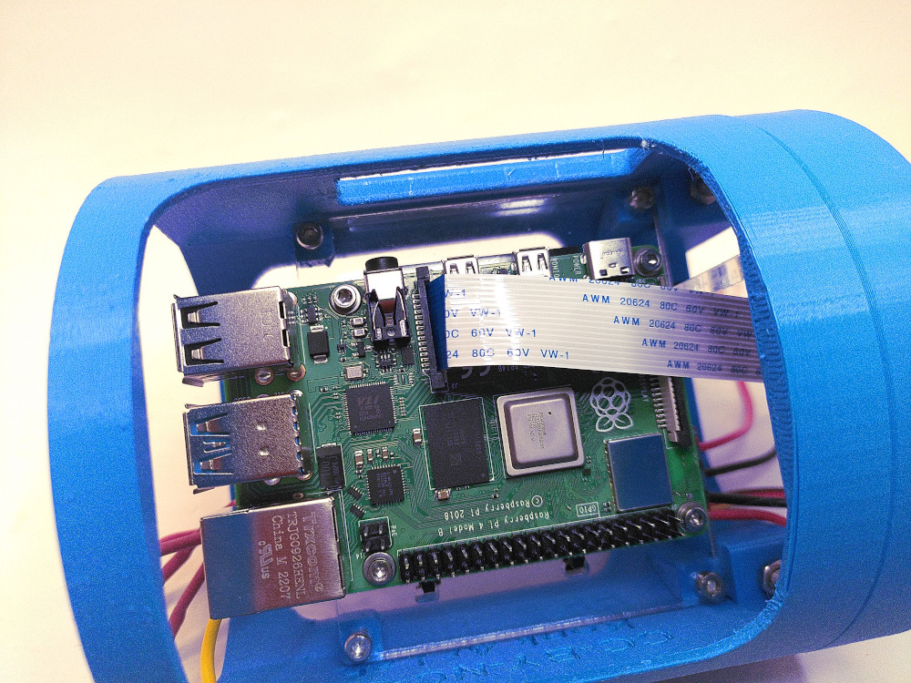
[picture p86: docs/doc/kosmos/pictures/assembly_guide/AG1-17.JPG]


### 1.5 Installation de la Batterie

* Rassembler la partie interne du KOSMOS, une batterie lipo 3s 2200mAh une rallonge de câble de recharge Lipo 3s et 2 colsons.

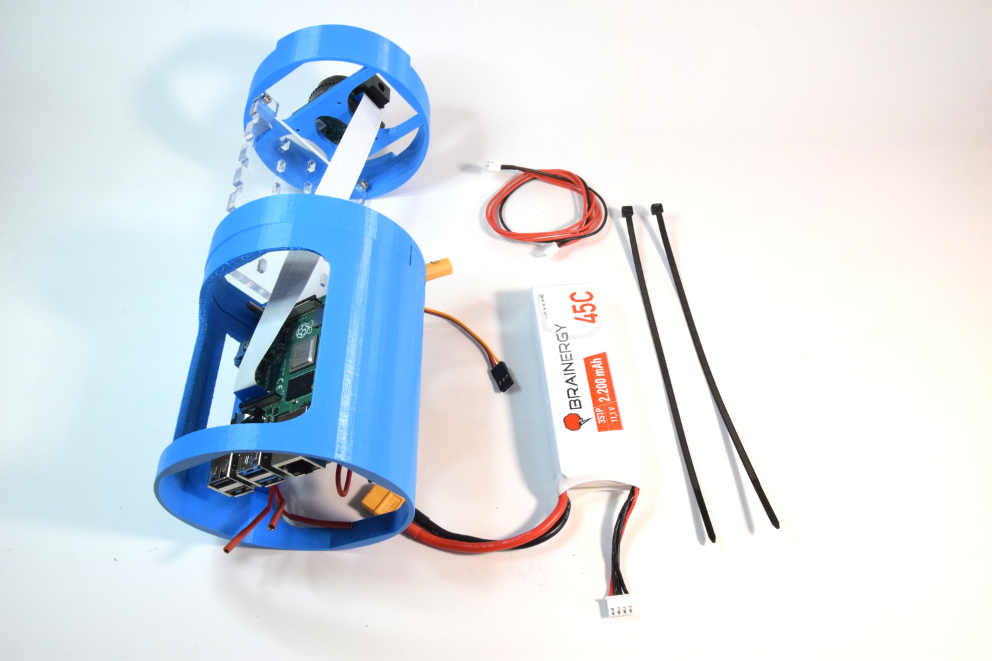
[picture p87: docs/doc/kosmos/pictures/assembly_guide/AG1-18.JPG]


* Positionner la batterie sur S2 sur un des deux flanc étroit.  Maintenir en place la batterie à l'aide de colsons. On préférera positionner les câbles du côté de la raspberry et de veiller à mettre la batterie en buttée sur la structure où est vissée la Picam. 

AG1-19

* Brancher le connecteur XT60 avec celui du circuit d'alimentation.
* Brancher la rallonge de rechargement au connecteur de la batterie. Ce câble circulera vers l'arrière en passant devant la Raspberry.

AG1-20

### 1.6 Câblages interne

Les étapes suivantes nécessitent des compétences en soudure électronique. Vous pouvez retrouver des conseils en annexes mais n'oubliez pas de bien recouvrir les soudures de gaines thermos-rétractable pour protéger des feux contacts. Il faut souvent veiller à insérer un morceau de gaine avant de souder. Le schèma suivant représente le circuit qui va être détaillé dans la partie 1.6. 

//Ici le schéma de montage du circuit d'alim//
AG1-21

 - Visser au moyen de 4 vis M3* 6mm, le PCB sur le dessus du KOSMOS à l'opposé de l'emplacement de la batterie. Connecter la nappe de 40 broches sur le connecteur dupont de 40 broches et l'autre extrémité sur les GPIO de la Raspberry. Attention à placer les deux extrémités de la nappe dans le même sens. Les deux connecteurs sont parallèles. 
AG1-22

 - Souder à la borne positive d'un connecteur XT60, un câble rouge (14AWG) d'une longueur de 220 mm. 

AG1-23

 - Souder à l'autre extrémité du câble un connecteur XT60 mâle qui servira à connecter le bouton de mise en tension. 

AG1-24

 - Souder à la borne négative du connecteur XT60 mâle deux câbles un fil de 200mm, Ainsi que le fil positif 12v du convertisseur (Chuangruifa). 

AG1-25

 - Étamer l'autre extrémité du fil de 200mm précédemment soudé et la visser sur le domino centrale (COM) du relai. Ajouter un fil de 100 mm sur ce même connecteur. 
 - Etamer le fil rouge de l'ESC et le brancher à la borne NO du relai.
 
AG1-26 

 - Raccorder ensemble les fils noirs de l'ESC et du convertisseur (12v) ainsi que un fil de 20mm. Raccorder ses trois fils au pôle négatif du connecteur XT60 femelle qui se raccorde à la batterie. 

AG1-27 

 - Sertir sur une prise JST le fil venant de la masse de la batterie et le fil positif venant du relai (borne COM). Positionner la masse de manière à ce qu'elle soit du coté de l'indicateur de batterie (ici fil vert). 

AG1-28 

 - Rallonger les fils de sortie 5v du convertisseur pour sertir une prise Dupont femelle. On utilisera un connecteur dupont 3 broches avec la masse au centre et le fil du positif à droite ou à gauche cela n'a pas d'importance. De cette manière il ne sera pas possible de brancher l'alimentation 5 v à l'envers. 

 - Couper le connecteur dupont de la prise de BEC de l'ESC (3 fils, jaune, rouge et marron ou noir). Y sertir un connecteur JST à deux broches. En excluant le fil rouge. Attention au sens. Le fil jaune destiné au signal doit être placé du coté de l'afficheur de niveau de batterie. 

AG1-30 
AG1-31 

 - Fabriquer un câble (rallonge du capteur de pression) de 180mm de long constitué de 4 fils (vert, blanc, rouge et noir). Sertir un connecteur JST 5 broches à une extrémité. Souder les fils sur un JST femelle à l'opposé. Attention à bien veiller à respecter, l'ordre, le sens du connecteur et les emplacement vides. 
                                                          
AG1-32 
AG1-33 

 - Fabriquer un câble (rallonge du capteur magnétique) de 180mm de long constitué de 3 fils (Jaune, rouge et bleu). Sertir un connecteur JST 4 broches à une extrémité. Souder les fils sur un JST femelle à l'opposé. Attention à bien veiller à respecter, l'ordre, le sens du connecteur et les emplacements vides. 

AG1-34 
AG1-35 

 - Brancher la rallonge du capteur de pression sur le connecteur prévu à cet effet. 
 - Brancher la rallonge du capteur magnétique à son emplacement. 
 - Passer ces deux câbles le long de la raspberry de manière à ce que les prises soient présentés à proximité des connecteurs USB de la raspberry. 

AG1-36 

 - Souder 3 connecteurs bananes au bout des trois fils de sortie de l'ESC

AG1-37 

### 1.7 Installation de l'objectif Edmund

 - Rassembler l'assemblage et l'objectif Edmund.
AG1-38 

 - Ôter le capuchon qui protège le capteur de la Pi cam, veiller à conserver la bague C-CS sur la monture de la Pi cam. 
 - Visser l'objectif Edmund sur le Pi Cam et lui ôter sa protection. Les réglages se feront par la suite. 
AG1-39 

## 2/ Assemblage du caisson

Pour l'assemblage du tube, il sera nécessaire de graisser \(graisse silicone de plongée\) certaines pièces pour à la fois assurer l'étanchéité et faciliter le démontage du tube étanche. Attention, il ne faut graisser que les pièces qui coulissent \(ex : Flange, bouchons, interrupteurs rotatifs\). Le graissage se fait au doigt et consiste à simplement huiler les surfaces qui doivent coulisser ou tourner tout en restant étanche.

### 2.1 Assemblage du bouton rotatif :

* Le bouton rotatif est livré démonté par Blue robotics. Rassembler le passe-coque, le bouton, les trois joints thoriques, le poussoir, les deux fils et l'écrou rouge.

AG2-1

* Placer le plus grand des trois joints thoriques dans la gorge du passe-coque.

AG2-2

* Au doigt, graisser les deux joints restants. Puis insérer les dans les deux gorges du bouton noir.

AG2-3

* Visser le bouton noir dans le passe-coque. Le vissage doit être facile. Si ce n'est pas le cas, il sera peut-être nécessaire de graisser d'avantage.

AG2-4

* Visser l'écrou sur le passe-coque.

AG2-5

* A l'extrémité opposé au bouton noir, visser le bouton poussoir. Préalablement on aura ôté l'écrou se situant sur le poussoir. Ce dernier n'a pas de fonction sur le KOSMOS. Dévisser légèrement le bouton noir de manière à ce que le poussoir soit ouvert \(surveiller à l'aide d'un multimètre sur le mode continuité\).
* Pour finir connecter les fils sur les broches du bouton poussoir.

AG2-6

### 2.2 Assemblage du bouchon vent :

* Le bouchon vent est livré démonté par Blue robotics. Rassemblez le passe-coque, le bouchon, les trois joints thoriques, le poussoir, les deux fils et l'écrou.

AG2-7

* Placer le plus grand des trois joints thoriques dans la gorge du passe-coque. Puis visser l'écrou.

AG2-8

* Insérer les deux petits joints thoriques dans les deux gorges du bouchon.

AG2-9

* Visser le bouchon sur le passe-coque en graissant légèrement à la graisse silicone les joints.

AG2-10

### 2.3 Assemblage du capteur de pression

* Le capteur de pression est livré démonté par Blue robotics. Rassembler le capteur dans son passe-coque, le joint thorique et l'écrou.

AG2-11

* Insérer le joint thorique dans la gorge et engager l'écrou sur le capteur.

AG2-12

### 2.4 Serrage des passes-coques sur le end cap aluminium

* Rassembler, le end cap en aluminium à 5 trous, les deux connecteurs cobalts femelles, ainsi que les trois passes-coques précédamment assemblés \(bouton rotatif, bouchon vent, et capteur de pression\).

AG2-13

* Visser les connecteurs cobalt sur deux trous voisins. Attention à veiller à positionner le joint du côté externe.

AG2-14

* Visser et serrer les 3 autres passe-coques. Serrer fort les 5 passes-coques. Pour le bouton rotatif, il sera nécessaire de dévisser le bouton poussoir pour l'insérer dans end cap. 

AG2-15

### 2.5 Assemblage du end-cap sur la flange

* Rassembler, le end-cap et ses passes-coques, une flange ainsi que les pièces fournies avec la flange \(3 joints thoriques, et un 6 vis M3\).

AG2-16

* Au doigts graisser légèrement les deux joints les plus épais.
* Insérer ses derniers dans les gorges prévues à cet effet.

AG2-17

* Insérer sans graisser le plus fin des joint thorique dans la dernière gorge de la flange.

AG2-18

* Visser le end-cap sur la flange à l'aide des 6 vis M3.

AG2-19

### 2.6 Assemblage du bouchon hublot

* Rassembler la seconde flange, ses 3 joints thoriques, le hublot \(end-cap clear\) et les 6 vis M3.

AG2-20

* Exactemment comme à l'étape précédente installer les 3 joints sur la seconde flange. Ne pas oublier le graissage des deux gros joints.
* Visser le hublot à l'aide des 6 vis M3.

AG2-21

### 2.7 Assemblage du détrompeur

Le détrompeur est une pièce bleu permettant d'insérer la caméra dans un sens défini dans le tube. Il est imprimé en 3D et se vis sur le bouchon hublot du caisson.

* Rassembler le bouchon hublot, le détrompeur \(I4\), et 4 vis M3\*20mm.

AG2-22

* Visser le détrompeur sur l'arrière du bouchon hublot.Il n'y a pas de sens à respecter sur cette étape.

AG2-23

### 2.7 connectiques

 - Souder un connecteur XT60 femelle sur le bout des deux fils provenant du bouton d'allumage étanche. 

AG2-26 

 - Souder trois connecteurs bananes mâles sur les 3 fils provenant d'un des deux connecteurs cobalt 3 pins. 

AG2-27

 - Sertir sur les trois fils du second connecteur cobalt un connecteur JST mâle. En veillant à bien respecter le positionnement des fils de manière à pouvoir le brancher sur la rallonge du capteur magnétique. 

AG2-28

 - Sertir les 4 fils du capteur de pression sur un connecteur mâle JST 4 broches. 
 
AG2-29

### 2.8 Assemblage final du tube

* Rassembler les deux bouchons et le tube acrylique.

AG2-24

* Dévisser totalement le bouchon du vent \(OK\) pour faire un appel d'air.
* Insérer chaque bouchon à une extrémité du tube. Il doivent s'insérer facilement \(dans le cas contraire ajouter de la graisse.
* Refermer le bouchon du vent.

AG2-25

* Pour ouvrir le caisson dans les étapes suivantes, commencer par ouvrir le vent, puis tirer bien dans l'axe le bouchon des passes-coques. Il n'est pas nécéssaire de regraisser à chaque fois. Cependant il faudra veiller à ne pas salir les parties graissées.

## 3/ Assemblage du réducteur

Le KOSMOS est une caméra sous-marine capable de pivoter dans un sens unique par pas de 60°. Ainsi elle observera un panoramique en sous-échantillonant par 6 plans vidéos  de 60° et 30s chacun.

La question de la motorisation a longuement posée problème. Par soucis de reproductibilité \(outillage standart d'un Fab Lab\), nous avons vite écarté la possibilité de réaliser une transmission mécanique par arbre traversant. Nous avons donc du trouver un autre moyen. Nous sommes donc partis d'un moteur de ROV capable de tourner dans l'eau. Seulement il s'agit d'un moteur Brushless qui donc tourne vite et déploie peu de couple.

Afin de réduire la vitesse et augmenter le couple d'entrainement, nous avons donc décidé d'utiliser un réducteur à 4 étages. La dernière roue entraine un bras qui fait tourner une croix de Malte. Cette dernière permet de réaliser un angle de 60° précisément lorsque la dernière roue effectue un tours complet. Afin de valider la position des engrenages. Nous avons ajouté un capteur magnétique \(contact reed\).

### 3.1 Préparation des engrenages

* Préparer les pièces pour monter les 3 premiers pignons. Pour cela, rassembler les P2 , P3 et P3.2, et 9 vis M2,5 \* 12mm.

AG1-1

* A l'aide d'un foret à métaux de 4mm et d'une perceuse \(à colonne de préférence\), élargir les 3 trous des trois pignons n°1 sur une profondeur permettant à la tête de vis de ne pas dépasser.
* A l'aide d'une clé alen de 2mm, assembler les trois trio de pignons comme présenté ci-dessous. On place un pignon P3.2 entre un P2 et un P3. La vis viendra tarauder le pignon P3.  Avant de serrer veillez à bien aligner la denture entre les pignons P3 et P3.2.

AG1-1bis
AG1-1ter

### 3.2 Assembler la croix de Malte

* Rassembler la croix de malte P4, une rondelle inox M8\*22mm, 4 vis M3\*18mm et la pièce R3.

AG1-2

* Assembler la croix de Malte en insérant la rondelle dans l'emplacement prévu à cet effet, entre la croix de Malte et la pièce R3. Visser avec les 4 vis à l'aide d'une clé alen de 2,5mm.

AG1-3
AG1-3bis

### 3.3 Découpe des entretoises et tiges filetés

* Couper 4 morceaux de tube inox à des longueurs différentes \(1\*42,5mm ; 1\* 49,2mm et 2\* 51,3mm\). On peut effectuer une première coupe au coupe tube puis finir au tour à métal. Veiller à bien ébarber les extrémités afin que la tige fileté s'incère facilement à l'intérieur du tube ;

* A l'aide d'une meuleuse ou à la scie à méteaux, couper 4 morceaux de tige filetée inox M8 de 1\*160mm et 3\*85mm de longueur. A l'aide d'une lime on s'assurera de redresser le filet afin qu'un écrou puisse se visser sans difficulté.

### 3.4 Assemblage de l'arbre primaire

* Rassembler la croix de malte précédemment montée, deux pignons, deux rondelles M8\_18mm, deux rondelles M10\_22mm, 2 écrous freins M8, la pièce R5, le morceau de tube d'inox de longueur 42,5mm et de la tige fileté M8 de longueur 160mm.

AG1-4

* Installer le tube dans la croix de malte, cette dernière viendra s'épauler sur la rondelle prise dans la croix de malte. Puis insérer une rondelle M10 ;

AG1-5
AG1-5bis

* Insérer un pignon \(petit pignon vers le bas\) puis une rondelle M10, puis le deuxième pignon \(petit pignon vers le bas\). L'entretoise doit dépasser de moins d'un millimètre.

AG1-6

* Visser un écrou frein sur la tige fileté à 85mm \(Ajouter de l'huile sur la tige pour faciliter le vissage\). Ajouter une rondelle M8 sur le coté opposé au frein de l'écrou.

AG1-7

* Insérer cette tige fileté à travers l'assemblage précédemment fait. L'écrou pré-vissé sera en buté sous la croix de malte séparé d'une rondelle M8.

AG1-8

* A l'opposé de la croix de Malte \(au dessus des pignons\) insérer une rondelle M8.

AG1-9

* Au dessus de la rondelle insérer la pièce R5.

AG1-10

* Serrer le tout par un écrou frein que l'on place au dessus du tout. Serrer fermement à l'aide de clés plates.  On pourra s'aider d'un écrou et contre-écrou pour visser correctement les écrous freins.

AG1-11

* Assurez-vous que les pignons tournent librement. La croix malte doit elle rester immobile.

### 3.5 Assemblage du bras de malte

* Rassembler les pièces 2\* P5.2 , P5 et la P2.2 ainsi que un aimant en néodyme carrée, 3 vis M2,5\*18mm et une vis M5\*20mm à tête fraisée ;

AG1-12

* A l'aide d'une perceuse à colonne et d'un foret de 4,5mm, percer la P2.2 pour loger la tête des 3 vis M2,5.
* A l'aide d'un foret de 10mm, percer la pièce P5 sur 2,5mm de profondeur pour loger la tête de la vis M5 ;
* Insérer 3 vis M2,5 dans les trois petits trous de la pièce P2.2. Insérer par dessus les deux P5.2 l'une sur l'autre. La tête de chaque vis M2,5 doit se loger dans la P2.2 et ne pas dépasser de cette dernière ;

AG1-13

* Visser par dessus la P5 qui sert de serrage, en veillant à ce que le logement de la tête de vis M5 soit à l'extérieur. A la colle chaude insérer l'aimant carrée dans son logement. Veiller à ce qu'il ne dépasse pas du tout du coté intérieur ;

AG1-14

* Rassembler le bras de malte que nous venons d'assembler,  une vis à tête fraisée M5\*16mm et une paille en inox de diamètre 5mm.
* Couper au coupe tube un bout de paille inox de 9mm de long et veiller à ce que la vis M5 s'y insère sans acros ;
* Visser la vis M5 en insérant entre la P2.2 et la P5 le tube inox 5mm. La tête doit se loger dans la pièce P5 et se visse dans la P2.2 ;

AG1-15

### 3.6 Assemblage de l'arbre secondaire

* Rassembler, le bras de malte précédemment assemblé, le tube inox 10mm\*49,2mm,  une tige filetée M8\*85mm, 4 rondelles M8\_18mm, 2 rondelles M10\_22mm, 2 écrous freins M8, la pièces R6, F1, F2, le dernier pignon et l'abre primaire ;

AG1-16

* Positionner l'arbre primaire sur F2 comme présenté ci-dessous. L'assemblage qui suis nécessite de faire jouer les deux arbres pour pouvoir enfiler les engrenages correctement ; \(Ajouter annotation des plaques + photos pas à jour \)

AG1-17
AG1-17bis

* Visser un  écrou neel stop M8 sur le bout de la tige filetée en laissant dépasser quelques millimètres. Insérer une rondelle M8 ;
* Passer la tige fileté à travers la pièce F2 par le trou indiqué en veillant au sens ;

AG1-18

* Passer une rondelle M8, l'entretoise inox 10\*49,2mm, l'entretoise en plastique R6  et enfin une rondelle M10 ; \(Ajout d'une étape pour détailler l'ajout du tube puis de R6\)

AG1-19

* Enfiler le pignon \(petit pignon vers le haut \) puis une rondelle M10 ;

AG1-20

* Enfiler le bras de Malte \(grand engrenage vers le bas\), et pour finir une rondelle M8,

AG1-21

* Refermer par la flasque F1  ;

AG1-22

* Sur l'arbre secondaire, on ajoute à la sortie une rondelle M8 puis on sert généreusement à l'aide de deux clés de 13 les deux écrous de l'arbre secondaire de manière à ce que les deux flasques soient maintenues en parallèle ;

AG1-23

* Surveiller que les deux arbres s'entrainent correctement en tournant à la main le grand pignon le plus éloigné de la croix de malte ;

* Rassembler, les deux tubes inox 10\*51,3mm, deux tiges filetées de M8\*85mm, 2 écrous freins M8 et 2 écrous M8 ;

AG1-24

* Visser un écrou frein à l'éxtrémité de chaque tige filetée. Laisser la tige fileter dépasser de l'écrou de quelques millimètres ;

AG1-25

* Insérer ces tiges à travers la flasque F1, insérer sur chaque tige entre les deux flasques un tube inox \(entretoise\), puis serrer au moyen des écrous M8.

AG1-26

### 3.7 Fixation du moteur

* Rassembler le moteur auquel on aura ôté l'hélice \(si livré avec\) en plastique au moyen d'une dremel, 6 vis M3\*8mm, 3 vis M3\*40mm, les pièces C3, P1 et R4 ;

AG1-27

* Visser la plaque C3 sur le moteur \(du coté où sortent les fils\). Attention à verifier qu'en positionnant les fils du moteur dans l'encoche de R4, les trous destinés à passer les vis M3\*40 s'alignent entre C3 et R4 ;

AG1-28

* Visser le moteur au réducteur sur F2 avec les vis M3\*40mm.  Les vis traverssent C3 et R4 pour se serrer dans F2 ;

AG1-29

* Visser le pignon P1 au bout du moteur au moyen de deux vis M3\*8mm ;

AG1-30

### 3.8 Montage des bers (supports du caisson)

* Rassembler les pièces du ber 2\*R1 et 2\*R1.2. Ainsi que 2 vis M5\*30mm,  2 vis à tête hexagonale M5\*20mm et 4 écrous à frein filet M5.

AG1-33

* Reproduire les étapes qui suivent deux fois.
* Installer la vis M5\*20mm à tête hexagonale de manière à former une charnière entre R1 et 1.2. Serrer à l'aide d'un écrou frein juste sufissament pour empêcher l'écrou de se désolidariser de la vis sans gêner l'ouverture du ber.
* Installer la vis CHC sur la fermeture du ber. On bloquera à l'aide de l'écrou frein M5.

AG1-34

### 3.9 Installation des Bers sur le réducteur

* Rassembler le réducteur, les deux bers précédemment montées, 4 vis à tête fraisée M5\*20mm et 4 écrous M5 de préférence à frein filet.

AG1-35

* A l'aide des vis et des écrous M5, fixer les deux bers sur le dessus du réducteur. Veiller à ce que l'ouverture se fasse dans le même sens sur les deux bers.

AG1-36

### 3.10 Installation du capteur magnétique

* Rassembler le capteur magnétique contact reed étanche, la pièce R2 et 4 vis M3*6mm.

* Au moyen d'un pistolet à colle, coller le capteur magnétique dans R2.
AG1-31

* Puis visser R2 sur F1 au moyen des 4 vis M3*6mm. 
AG1-32

* Solidariser les fils du capteur au réducteur au moyen de rilsans. Utiliser les trous prévu à cet effet. Laisser courir les câbles et les laisser ressortir par l'encoche sur F2. 
AG1-32bis

### 3.11 Installation des parois du réducteur

* Rassembler le réducteur, 19 vis M3\*14mm 19 écrous M3 ainsi que les 4 plaques C1 et C2.

AG1-37

* Positionner 4 vis M3\*14mm dans chaque trou des deux plaques C2. Engager pour chaque vis un écrou sur chacune des vis sans la serrer.
* Positionner Les 17 autres vis et écrous de la même manière sur le tour complet du réducteur \(les deux plaques en PMMA parallèles\). Positionner les écrous vers l'intérieur du réducteur.

AG1-38

* Installer les plaques C2 sur les deux côtés les plus courts du réducteur. Serrer les vis une à une en veillant à ce que les écrous viennent bloquer la plaque. Attention à serrer à tâton pour éviter de fendre le PMMA.

AG1-39

* Installer Les plaques C1 sur les deux côtés longs du réducteur. Comme à l'étape précédente, veiller à ce que les écrous viennent bloquer la plaque. Attention à serrer à tâtons pour éviter de fendre le PMMA.

AG1-40

### 3.12 Raccordement des connectiques capteurs 
 - Rassembler le réducteur, la pièce R8 et un câble étanche cobalt,
 - Insérer les trois fils du capteur ILS dans les trois trous de la pièce R8
 - Dénuder les fils du capteur,
 
AG3-41

 - Insérer le câble cobalt étanche. Pousser la gaine à travers la pièce R8 de manière à la bloquer. 
 - Dénuder les fils du câble,

AG3-42

 - Insérer des sections de gaine thermorétractable sur chaque fil du capteur.

AG3-43

 - Étamer chacun des fils dénudés. Enfin les souder en respectant les branchements suivants : **Noir sur noir, rouge sur bleu, jaune sur blanc**. 

AG3-44

 - Décaler les gaines thermorétractable de manière à isoler les 3 soudures et les rétracter au moyen d'un pistolet à air chaud. 

AG3-45

### 3.13 Raccordement des connectiques moteur
 - De la même manière que pour l'étape précédente, rassembler le réducteur, la pièce R6 et un câble étanche cobalt,
 - Insérer les trois fils du moteur dans les trois trous de la pièce R6
 - Dénuder les fils du moteur,
 - Insérer le câble cobalt étanche. Pousser la gaine à travers la pièce R8 de manière à la bloquer, 
 - Dénuder les fils du câble,
 - Insérer des sections de gaine thermorétractable sur chaque fil du moteur.
 - Étamer chacun des fils dénudés. Enfin les souder sans respecter de branchement particulier. 
 - Décaler les gaines thermorétractables de manière à isoler les 3 soudures et les rétracter au moyen d'un pistolet à air chaud. 

AG3-46

### 3.14 Étanchéification des connectiques et fixation
 - Préparer la résine époxy dans un récipient à part. Se référer aux spécifications du fabriquant pour le dosage entre résine et durcisseur. 
 - Positionner les pièces R8 et R6 à plat sur un morceau de bois vissé au moyen de deux vis à bois; S'assurer que les fils ne dépassent pas de l'épaulement. 

AG3-47

 - Couler la résine époxy dans les deux connecteurs R8 et R6 sans dépasser l'épaulement. 
 - Laisser sécher au moin 24h.
 - A l'aide de 4 vis M3*5mm, fixer les deux connectiques étanches sur le dessus du réducteur. 

AG3-48

 - Clarifier les câbles en les enroulants au moyen de rilsans. 

AG3-49

<br>
## 4/ Assemblage final du KOSMOS
Une fois toutes les sous-parties assemblées il ne reste plus qu'à faire l'assemblage final. Soit à insérer le KOSMOS dans son tube, le raccorder au connecteurs de la flange mais aussi à solidariser le tube sur le réducteur. 

### 4.1 Installation du KOSMOS dans son tube

 - Insérer la structure du KOSMOS (assemblage fait en partie 1) dans son tube en ôtant uniquement le bouchon munit des capteurs et connecteurs. Veiller à ce que les deux pièces bleus s'imbriquent correctement. 

AG4-1

 - Coucher le tube et sortir légèrement son contenu, rassembler aussi le bouchon en aluminium avec ses connecteurs et capteurs et la clé USB.

AG4-2

 - Connecter les deux connecteurs JST (3 broches pour l'ILS et 4 broches pour le capteur de pression), Attention, le câble de charge de la ou des batterie(s) doit resté non connecté. Il ne servira qu'au moment de charger la batterie.

AG4-3

 - Connecter les trois connecteurs bananes entre eux. Il n'y a pas d'ordre de branchement à respecter

AG4-4

 - Connecter les connecteurs XT-60 (jaune) entre eux ils permet de mettre en série le bouton de mise en tension.

AG4-5

 - Connecter la clé USB à un port USB 3.0 (bleus) de la Raspberry. Il s'agira de son emplacement préféré. Lors des étapes d'installation du software, il sera nécessaire de la débrancher. Cette clé USB sera par ailleurs le stockage des données ainsi que l'emplacement d'un fichier de paramétrage essentiel le "kosmos_config.ini" en l’absence de cette clé le KOSMOS ne pourra démarrer et ne pourra stocker ses données. 

AG4-6 

 - Refermer le tube en laissant coulisser la structure interne dans le tube acrylique. Puis insérer délicatement le bouchon pour fermer le tube en ayant au préalable dévissé le bouchon de purge "Ok". Si le bouchon en aluminium s’insère avec difficulté, veiller à avoir graissé correctement les joints comme précisé dans l'étape 2.8. 

AG4-7 

 - Une fois le bouchon refermé correctement, qu'aucun fil n'est coincé, refermer le bouchon vent "ok".

AG4-8 

### 4.2 Positionner des auto-collants
Les autocollants sont importants sur KOSMOS, ils permettent, de marquer la version du système, de guider aux bons assemblages, au bon démarrage et marquer la compatibilité entre un tube et son réducteur (le moteur à l'habitude de tourner avec un ESC spécifique, intervertir avec un autre KOSMOS pourrait entrainer des erreurs). 

On peut faire imprimer ces autocolants sur du vinyle à une société extérieur ou les fabriquer sois même au moyen d'une découpe vinyle ou plotter de découpe. 

Découper les autocolants dans du vinyle en utilisant les fichiers vectoriels contenu dans l'archive hardware/stickers. 
 - stickers_kosmos_name.svg : 4 fois en noir.
 - stickers_number.svg : Modifier le fichier pour nommer votre KOSMOS comme vous le souhaitez. Découper cette vignette en 2 exemplaires.
 - stickers_power_steps.svg : Une fois en blanc
 - stickers_wire_indicators.svg : Une fois d'une couleur Une autre d'une autre couleur

 - Sur la flange repérer quel connecteur cobalt 3 pin est destiné à recevoir le moteur (3 fils connectés à l'ESC), et quel connecteur est connecté à la carte électronique (ILS). 
 - Utiliser un anneau autocollant d'une couleur différente pour chaque connecteur.
AG4-9 

 - Utiliser les bandes autocollantes pour marquer les cales cobalts en veillant à ce que le câble du moteur porte la même couleur que le connecteur de cloison relié à l'ESC. Inversement pour le capteur ILS. 
AG4-10 

 - Placer 2 petits triangle blanc l'un sur la tranche du hublot et l'autre sur le corps du tube en PMMA. Ce marqueur permettra de fermer le tube dans le bon sens lorsque l'on démontera la flange du hublot. On pourra utiliser deux autres autocollants triangles pour s'assurer que le tube sera bien horizontale lorsque celui-ci sera placé sur le réducteur (caméra bien horizontale).
AG4-11 

 - Placer des autocollants KOSMOS et numéro de version Sur le tube (avant arrière) et sur les deux flancs (gauche / droite) du réducteur. 
AG4-12
AG4-13
 
 - Placer un autocollant de numéro d'instrument sur un coté du réducteur et un autre correspondant à la même référence sur le tube. 
AG4-14

### 4.3 Solidariser le tube sur le réducteur
L'étape suivante n'est pas forcément requise. Lors du transport du KOSMOS on préférera stocker le tube dans une caisse étanche molletonnée. Quand au réducteur qui sera très souvent humide, le stocker dans une caisse en plastique

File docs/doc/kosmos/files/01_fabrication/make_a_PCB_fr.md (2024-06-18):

icon:material/vector-polyline-edit
# Fabrication d'un PCB

## 1/ Matériel et outils nécessaires

### 1.1. Matériel
 - Une plaque cuivrée mono-couche de 80mm*95mm. 
 - Acide chlorydrique 23% (Magasin de bricolage)
 - Eau oxygénée (10 ou 30 volumes)
 - Papier de publicité (glacé)
 - Alcool à 90°
 - Dissolvant de maquillage
 - Acétone
 
### 1.2. Outils
 - Imprimante papier laser
 - Bac en plastique de récupération (ex : boite de glace)
 - Gants jetables
 - Scie à métaux ou dremel
 - Paire de ciseaux

## 2/ Gravure

### 2.1. Impression
 - Imprimer le PCB sur du papier glacé de type publicité avec l'imprimante laser. 
 - Découper les contours de l'empreinte.

### 2.2. Transfert des pistes sur la plaque de cuivre
 - Poncer la plaque cuivrée à l'aide d'un papier de verre très fin (1000). 
 - Nettoyer la surface cuivrée à l'aide d'alcool. Nettoyer jusqu'à ce qu'il n'y ai plus de traces sur l’essuie tout. 
 - Découper l'empreinte du PCB au ciseaux.
 - Dans le bac, verser du dissolvant à la surface de la plaque cuivrée. Bien répartir ce dernier afin qu'il prenne tout l'espace de la plaque. 
 - Sans attendre, déposer le papier glacé avec l'encre imprimée face au cuivre. 
 - Tamponner à l'aide d'un papier essuie tout. 
 - Laisser sécher la plaque une quinzaine de minutes de manière à ce que le papier ne soit plus du tout humide.
 - Une fois le papier totalement sec, très délicatement passer la plaque sous le robinet d'eau froide. Avec les doigts frotter de manière à dissoudre le papier. Seules les pistes doivent rester sur la plaque de cuivre. 

### 2.3. Gravure
 - Préparer une solution dont le volume permettra de recouvrir la plaque. Les concentrations sont 66% d'eau, 3,3% d'eau oxygénée et 30% d'acide chlorhydrique. 
 - Plonger la plaque dans la solution.
 - Laisser agir au moins une heure. Le cuivre apparent doit laisser place au support de couleur souvent jaune ou verte. Attention à ne pas laisser trop longtemps au risque que l'acide attaque les pistes).
 - Après gravure, rincer le circuit à l'eau.
 - Enfin effacer l'encre à l'aide d'un papier essuie tout imbibé d'acétone. 

## Liens connexes 

 - Préparation de la solution de gravure : https://arlontronique.wordpress.com/menu/graver-ses-propres-circuits-imprimes/
 - Transfert des pistes sur le cuivre : https://youtu.be/8joLK039fjk

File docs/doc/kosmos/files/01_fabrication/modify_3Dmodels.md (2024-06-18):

icon:material/rotate-3d
# Appropriation des modèles 3D pour modifications

Cette documentation détail l'usage desmodèles 3D modifiables partagés dans ce GitHub. Ce dossier se trouve au bout du chemin suivant : hardware/3Dmodels_editable. 
Les présents dossiers contiennent tous les fichiers nécéssaires pour modifier le dessin 3D du KOSMOS. Il est indispensable pour les modifier d'utiliser le logiciel [Autodesk Fusion 360, une licence gratuite pour usage personnelle suffira](https://www.autodesk.fr/products/fusion-360/personal-form).

Les fichiers Modifiables portent l’extension ".f3D". Tandis que les assemblages portent l'extension ".f3z".

## 1/ Hiérarchisation des dossiers
Le dossier d'archive (3D_KOSMOS) est organisé selon 4 sous-dossiers :
 - **Assemblages :** Contient les fichiers ".f3z" d'assemblages. Les fichhiers d'assemblages nécéssitent que tout les fichiers pièces compris dans l'assemblage soient déjà importés sur Fusion. 
 - **Intérieur :** Contient les fichiers 3D des pièces structurant les composants contenu dans le caisson. 
 - **Réducteur :** Contient l'ensemble des pièces servant à construire le réducteur
 - **Autres :** Contient les petites pièces qui ont été utiles au projets mais qui ne servent pas au KOSMOS directement. 

## 2/ Détails des fichiers 

### 2.1. Assemblages
 - **Assemblage_Axe_primaire_KOSMOS3-0.f3z :** Sous assemblage de l'arbre primaire celui contenant la croix de Malte. 
 - **Assemblage_ber_KOSMOS3-0.f3z :** Sous assemblage du ber_dessus et ber_dessous permettant de solidariser le réducteur au caisson. 
 - **Assemblage_croix_de_malte_KOSMOS3-0.f3z :** Sous assemblage, contenant la croix de malte seule. 
 - **Assemblage_Engrenage_KOSMOS3-0.f3z :** Sous assemblage d'un engrenage (petit et grend pignons).
 - **Assemblage_moteur_KOSMOS3-0.f3z : ** Sous assemblage, du moteur vissé sur son support et son pignon d'entrainement. 
 - **Assemblage_Reducteur_KOSMOS3-0.f3z :** Assemblage final du réducteur. 

*Notes : Il n'existe plus d'assemblage à jour de la structure interne et de son caisson.*

### 2.2. Intérieur
Les pièces de l'intérieur du caissons sont nommés "structures" pour les pièces cylindrique épousant l'intérieur du caisson.

 - **Structure_batterie_KOSMOS3-0.f3d :** Anneau permettant de lier le structure de la Raspberry avec le  support de batterie et PCB. 
 - **Structure_camera_KOSMOS3-0.f3d :** Pièce permettant de positionner la caméra. Elle recevra également le support de batterie. 
 - **Structure_hublot_KOSMOS3-0.f3d :** Anneau qui sera solidaridé à la flange du Hublot. Elle est un guide pour insérer l'intérieur du tube dans le bon sens. 
 - **Structure_raspberry_KOSMOS3-0.f3d :**  Pièce permettant de positionner le support de Raspberry dans le tube. 
 - **Support_batteries_PCB_KOSMOS3-0.f3d :** Plaque supportant les batteries et le PCB.
 - **Support_raspberry_KOSMOS3-0.f3d :** Plaque supportant la raspberry. Elle est vissé sur la structure correspondante.

### 2.3. Réducteur

 - **ber_dessous_KOSMOS3-0.f3d :** Le "ber" désigne traditionellement une pièce permettant de soutenir un bateau sur la terre et ainsi d'éviter qu'il ne se couche. Nous utilisons ce mot pour désigner la pièce qui permet de solidariser le tube du KOSMOS au réducteur. Elle se compose en 2 partie (dessus/dessous) et se comptent au nombre de 2 par système. 
 - **ber_dessus_KOSMOS3-0.f3d :** Il s'agit de la pièce complémentaire au be-dessous. 
 - **Bras_de_Malte_seul_KOSMOS3-0.f3d :** Le KOSMOS tourne sur lui même par 6 séquences de 60°. La croix de Malte est le mécanisme qui permet de transformer un mouvement de rotation continue en mouvement de rotation sacadé. Le Bras est la pièce menant la croix de Malte. 
 - **Carter_AvAr_KOSMOS3-0.f3d :** Cloison du réducteur avant et arrière. Elle n'a aucune utilité mécanique mais permet de fermer le réducteur et ainsi d'aviter l'intrusion de corps étranger. 
 - **carter_dessous_KOSMOS3-0.f3d :** Cloison du réducteur du dessous. Cette pièce est également une pièce structurant le réducteur.
 - **Carter_dessus_KOSMOS3-0.f3d :** Cloison du réducteur du dessus. Cette pièce est également une pièce structurant le réducteur. 
 - **Carter_GD_KOSMOS3-0.f3d :** Cloison du réducteur gauche et droite. Elle n'a aucune utilité mécanique mais permet de fermer le réducteur et ainsi d'aviter l'intrusion de corps étranger. 
 - **connecteur_ILS_KOSMOS3-0.f3d :** Les connecteurs sont des pièces à imprimer en 3D qui servent à placer des raccords de câbles électriques puis de les noyer dans la résine pour en garantir l'étanchéité. Celui-ci est destiné à faire les racords pour les câbles du capteur mgnétique.
 - **connecteur_moteur_KOSMOS3-0.f3d :** Comme la pièce précédente il s'agit d'un réceptacle pour une connexion électrique qui pourra être étanché au moyen de résine epoxy. A la différence que celui-ci est destiné aux câbles du moteur. 
 - **couvercle_connecteur_ILS_KOSMOS3-0.f3d et couvercle_connecteur_moteur_KOSMOS3-0.f3d : ** Il s'agit là de couvercles que l'on peut ytiliser pour fermer les connecteurs. Mais ils ne sont pas indispensables. 
 - **Croix_de_malte_seule_KOSMOS3-0.f3d :** Le KOSMOS tourne sur lui même par 6 séquences de 60°. La croix de Malte est le mécanisme qui permet de transformer un mouvement de rotation continue en mouvement de rotation sacadé. Il s'agit d'une pièce très importante. Pour en modifier les dimentions préférer le modèle "croix_malte_et_bras_parametrique_KOSMOS3-0.f3d" qui permettra de modifier les dimensions du bras d'un seul coup. En revanches les assemblages utilisent les fichiers du bras et de la croix seules.
 - **croix_malte_et_bras_parametrique_KOSMOS3-0.f3d :** Pour modifier les dimensions du bras et de la croix de Malte. 
 - **Entretoise_arbre_croix_de_malte_KOSMOS3-0.f3d :** Tube pour l'axe primaire. Ce modèle ne sert qu'à l'assemblage 3D. L'usiner dans un tube d'inox A4 de 10/8mm.
 - **Entretoise_arbre_secondaire_KOSMOS3-0.f3d :** Tube pour l'axe secondaire. Ce modèle ne sert qu'à l'assemblage 3D. L'usiner dans un tube d'inox A4 de 10/8mm.
 - **entretoise_dessus_arbre_secondaire_KOSMOS3-0.f3d :** Petite pièce à imprimer en 3D, elle sert à dissocier la rotation des engrenages de celle de la croix de Malte. (Arbre primaire pas secondaire)
 - **entretoise_moteur_KOSMOS3-0.f3d :** Pièce à imprimer en 3D, dont la hauteur précise permet d'aligner correctement le pignon du moteur avec le premier grand pignon. Il sert également à protéger le moteur de l'extérieur. 
 - **extrémité croix de malte_KOSMOS3-0.f3d :** Il s'agit d'une pièce importante elle sert à transmettre l'effort de la croix de Malte à la tige fileté permettant ainsi au KOSMOS de pivoter sur lui-même. Son diamètre doit-être ajusté pour limiter le jeu avec le carter du dessous sans empêcher la rotation de ces deux pièces l'ine par rapport à l'autre. Cette pièce gagnerai à être usiné dans une masse de plastique au tour par exemple. 
 - **extrémité croix de malte_KOSMOS3-0.f3d :** A ce jour nous n'avons jamais essayé de fabriquer cette dernière pièce à la fraiseuse. Cependant nous avions commencés à y réflaichir. Ce modèle est ce que nous avions fait. 
 - **GdPignon_bras_de_malte_KOSMOS3-0.f3d :** Pignon (engrenage) destiné à se visser avec le bras de Malte. 
 - **GdPignon_KOSMOS3-0.f3d :** Pignon (engrenage) de grand-diamètre donc il s'agit des pignons menées. 
 - **Moteur-F2838-350KV_KOSMOS3-0.f3d :** Moteur, pour assemblage uniquement. Cette pièce est à acheter. 
 - **Pignon_moteur_KOSMOS3-0.f3d :** Pignon à visser sur le moteur, c'est le pignon meneur. 
 - **Pt_Pignon_entretoise_KOSMOS3-0.f3d :** Sur KOSMOS 3.0, les engrenages sont constitués de 3 pignons vissés entre eux. 1 grand pignon dans lequel est logé la tte de vis, et deux petit. Dont un fait office de simple rondelle (la vis n'y fait que passer), la seconde sert d'écrou. 
 - **Pt_pignon_serrage_KOSMOS3-0.f3d :** Ce pignon à la différence du précédent à des trous de plus petit diamètre afin que les vis à méteaux taraude la plastique et maintienne les 3 pignon l'un contre l'autre. 
 - **Rondelle-rotation_arbre_croix_de_malte_KOSMOS3-0.f3d :** Une simple entretoise pour empêcher les pignons de coulisser sans les empêcher de tourner. 
 - **Support_capteur_ILS_KOSMOS3-0.f3d :** Cette pièce se visse sous le réducteur et permet de maintenir en place le capteur magnétique. 
 - **Support_moteur_KOSMOS3-0.f3d :** Cette pièce est un disque percé à usiner en plastique qui permet de solidariser le moteur au carter du réducteur. 

### 2.4. Autres
 - **Adaptateur_paralenz_caisson_moteur.f3d :** L'équipe en mer utilise encore parfois les vieux caissons moteur surmonté d'une caméra Paralenz. Ce modèle permet de raccorder le caisson moteur (vis de serrage) avec le support de la Paralenz. 
 - **Porte_aimant_KOSMOS3-0.f3d :** Petite pièce permettant de placer un aimant carré néodyme (que l'on trouve chez bureau vallée à côté du FabLab). Il permet une bonne prise en main en mer. 
 - **Presentation_pc_print_KOSMOS3-0.f3z :** Cet assemblage m'a permis de faire un visuel pour présenter toutes les pièce sà imprimer en 3D sur une seule image. Le rendu est visible dans l'étape de "Fabrication des pièces".

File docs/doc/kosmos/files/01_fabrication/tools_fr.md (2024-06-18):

icon:material/hammer-screwdriver
# Liste de l'outillage nécessaire
S'assurer avoir à disposition ces quelques outils et machines. Si vous n'avez pas ces machines à disposition dans votre atelier, ce sont les machines qui sont généralement présentes dans tout les Fab Lab

## 1. Les machines

|**Nom**|**Informations complémentaires**|
|---|---|
|Découpeuse laser|Peut-être remplacée par une fraiseuse numérique|
|Fer à souder|Ou poste à souder avec panne plutôt fine|
|Fraiseuse numérique CNC|Pour la découpe du POM. Si pas de CNC on pourra remplacer les pièces en POM par du PMMA découpé au laser. |
|Imprimante 3D|Pouvant imprimer du PETG et avec un plateau de 20*20cm minimum|
|Tour à métaux|Pour ajuster les entretoises en longueur|

## 2. Les outils  utiles
| **Nom** | **Informations complémentaires** | 
|---|---|
|Alimentation secteur pour raspberry pi|Alimentation 5v 3A par USB-C |
|Bâton de colle chaude | |
|Bobine d’étain | |
|Câble HDMi | |
|Chargeur de batterie Lipo 3s | |
|Clavier |USB |
|Coupe tube |De préférence pour Inox |
|Écran |Avec connecteur HDMi |
|Fraises de 2mm |A 2 dents et adaptées au POM et à la CNC utilisée |
|Jeu de clés à cliquet |Ou 2 clés plates de 13 |
|Jeu de clés allen | |
|Jeu de clés plates | |
|Jeu de limes | |
|Jeu de limes de précision | |
|Jeu de pinces coupantes | |
|Jeu de pinces plates | |
|Jeu de tournevis | |
|Jeu de tournevis de précision | |
|Meuleuse |Avec les disques nécessaires pour couper et meuler la tige filetée en inox A4. Ou scie à métaux avec de la patience|
|Mini perceuse/fraiseuse |Dremel ou équivalents avec ses outils |
|Pied à coulisse | |
|Pince à dénuder | |
|Pince à sertir les connecteurs dupont |S’achète généralement avec le kit de connecteurs dupont |
|Pince à sertir les connecteurs JST |S’achète généralement avec le kit de connecteurs JST |
|Pince brussel | |
|Pistolet à colle | |
|Pompe à dessouder |ou tresse à dessouder selon habitudes |
|Réglet | |
|Scie à métaux | |
|Souris |USB |
|Troisième main | |
|Tube de graisse silicone de plongée | |

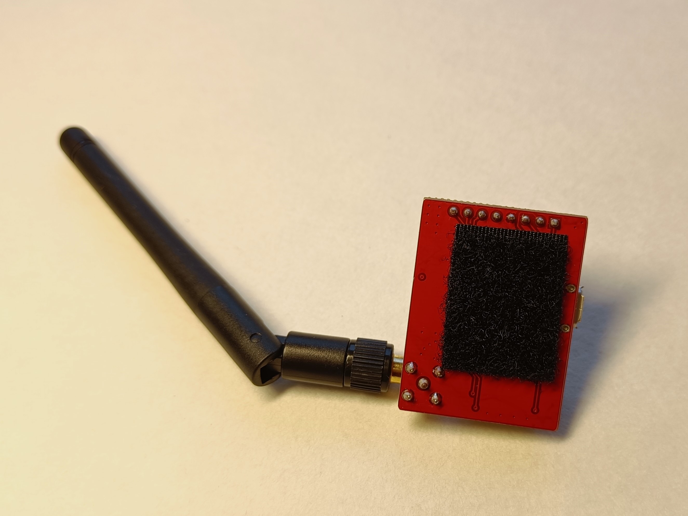
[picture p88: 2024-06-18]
docs/doc/micro_kosmos/pictures/assembly_guide/boitier/velcro_gps.jpg

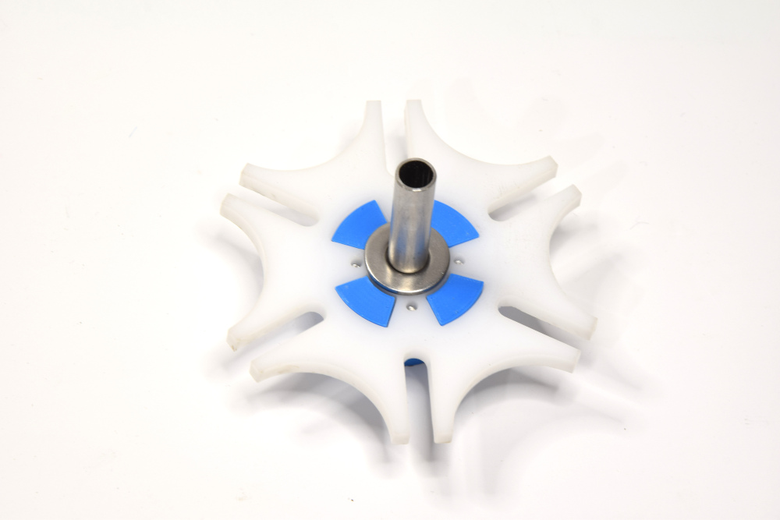
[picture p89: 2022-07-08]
docs/doc/kosmos/pictures/assembly_guide/AG3-5.JPG

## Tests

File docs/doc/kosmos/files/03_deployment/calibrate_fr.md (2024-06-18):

icon:material/gesture-spread
# Calibration du temps de pause

## 1/ Introduction
Cette notice permet de résumer la calibration du KOSMOS de manière à paramétrer la pause d’observation de 30 secondes par secteurs. 

La réalisation de la calibration du KOSMOS doit être effectuée **dans l’air, puis dans l’eau.**
La première calibration dans l’air permet de vérifier la cohérence du protocole d’observation :
Démarrage du moteur, passage d’un cran dans la croix de Malte, arrêt du moteur par l’ILS, et durée de la pause d’observation.
La seconde calibration dans l’eau permet d’obtenir une durée précise de la pause d’observation. En effet, dû à une importante différence de densité entre l’air et l’eau, le système de réduction ne se comportera pas de la même façon et le temps de calibration sera différent.

**Note :** Influence de l’eau sur le temps de rotation du kosmos

La présence de l’eau va considérablement contribuer à la perte de puissance du système de réduction. Cette résistance entre un fluide qui s’oppose au corps de l’engrenage s’appelle une perte par ventilation. L’expression du coefficient de perte par ventilation est ainsi directement fonction de la densité du fluide (rhô).
Par exemple la densité de l’air à Concarneau est d’environ rhô=1,195 kg/m3 (à  20° et 90% d’humidité). Tandis que la densité de l’eau à 10m est d’environ rhô=1 025,556 kg/m3 (avec 17,2°C, 35,2 psu et 2 bar). Nous avons donc un facteur 10 puissance 3.

NoticeDeCalibrationDuKosmosParametrerLa_Capture_dcran_de_20220825_160251_20220825161301_20220825161301

avec S une aire de référence, oméga la vitesse de rotation de l’engrenage, R le rayon de l'engrenage et C l’expression du coefficient de couple adimensionné déduit de l’équation de quantité de mouvement de Navier-Stokes.//""</center>""

## 2/ Paramétrage de la pause

La pause d’observation dépend de trois paramètres.
Ces paramètres sont modifiables par le réglage de trois variables présentes dans le code  :

 - **La durée de la pause**
La variable paramétrant la durée de la pause est présente dans le fichier **//kosmos_config.ini//** présent dans la clé de sauvegarde vidéo. 
Modifier la valeur **//SETT_MOTOR_STOP_TIME//** (ligne 12) pour changer le temps de pause, en secondes.
Il ne suffit pas de renseigner 30 secondes pour avoir un arrêt sur secteur de 30 secondes. Il faudra également déduire le temps nécessaire pour entraîner mécaniquement la caméra sur le secteur suivant. Ce temps à déduire est d’autant plus long que la vitesse de rotation du moteur est petite.
La variable **//SETT_MOTOR_STOP_TIME//** désigne donc le temps entre deux ordre de démarrage du moteur. 

 - **La durée de fonctionnement du moteur**
La variable paramétrant la durée de fonctionnement du moteur est également présente dans le fichier kosmos_config.ini présent dans la clé de sauvegarde vidéo. 
Modifier la valeur **//SETT_MOTOR_RUN_TIME//** (ligne 60) pour changer le temps de rotation du moteur.
Cette valeur désigne donc le temps nécessaire pour entraîner le kosmos sur son prochain cran de la croix de malte. Il peut varier de 6 à 20 secondes suivant la vitesse de rotation du moteur.
Cette valeur peut être surévaluée car le stop d’arrêt viendra empêcher le système de tourner de plus d’un cran.  

 - **L’arrêt de la rotation (Top d’arrêt ILS)**
La variable paramétrant l’arrêt de la rotation est présente dans le fichier **//kosmos_main.py//**
L’arrêt de la rotation se fera par le passage régulier d’un aimant dans le champ de détection du capteur ILS top d’arrêt.
Seulement, le champ de détection de l’aimant peut être plus ou moins important suivant les composants,  il est donc important de paramétrer la durée de détection de l’aimant par l’ILS. Si cette durée est trop longue, l’aimant risque d’être détecté deux fois, et le système marquera deux pauses sur le même secteur. 
Dans la procédure **//working()//** (ligne 103)
Une fonction **//time.sleep()//** est renseignée trois fois. 
Dans les parenthèses du **second appel de la fonction** (ligne 141), renseigner le temps pendant lequel l’ILS ne devra pas être détecté. Plus le temps renseigné est long, plus l’aimant aura une chance de sortir du champ de détection sans être détecté une nouvelle fois. Une durée de 4 secondes semble raisonnable. Renseigner alors **//time.sleep(4).//**
Attention à ne pas mettre un temps trop élevé de manière à éviter que le kosmos ne tourne de plusieurs crans.  

## 3/ Procédure :

 - Dans un premier temps, calibrer la durée de fonctionnement du moteur et l’arrêt de la rotation de manière à ce que le KOSMOS tourne et s’arrête secteurs par secteurs. (faire varier SETT_MOTOR_RUN_TIME et time.sleep).

 - Faire ensuite varier la durée de la pause de manière à obtenir 30 secondes de plan fixe par secteurs. (faire varier SETT_MOTOR_STOP_TIME). Il faudra prendre en compte le temps pris par le système de réduction entre le démarrage du moteur et l'entraînement du KOSMOS sur le prochain cran.

 - Ajuster les paramètres de manière à obtenir un système respectant les pauses de 30 secondes dans l'air. Faire ensuite le test dans l'eau et observer la différence de temps d'observation sur la vidéo enregistrée. Réduire le temps exédant en diminuant la variable SETT_MOTOR_STOP_TIME. 

On peut ainsi évaluer **SETT_MOTOR_STOP_TIME + SETT_MOTOR_RUN_TIME ≃ 30**

## Paramétrage de nos KOSMOS

**KOSMOS 1** :
``` 
SETT_MOTOR_STOP_TIME = 14
SETT_MOTOR_RUN_TIME = 20
time.sleep(4)
```

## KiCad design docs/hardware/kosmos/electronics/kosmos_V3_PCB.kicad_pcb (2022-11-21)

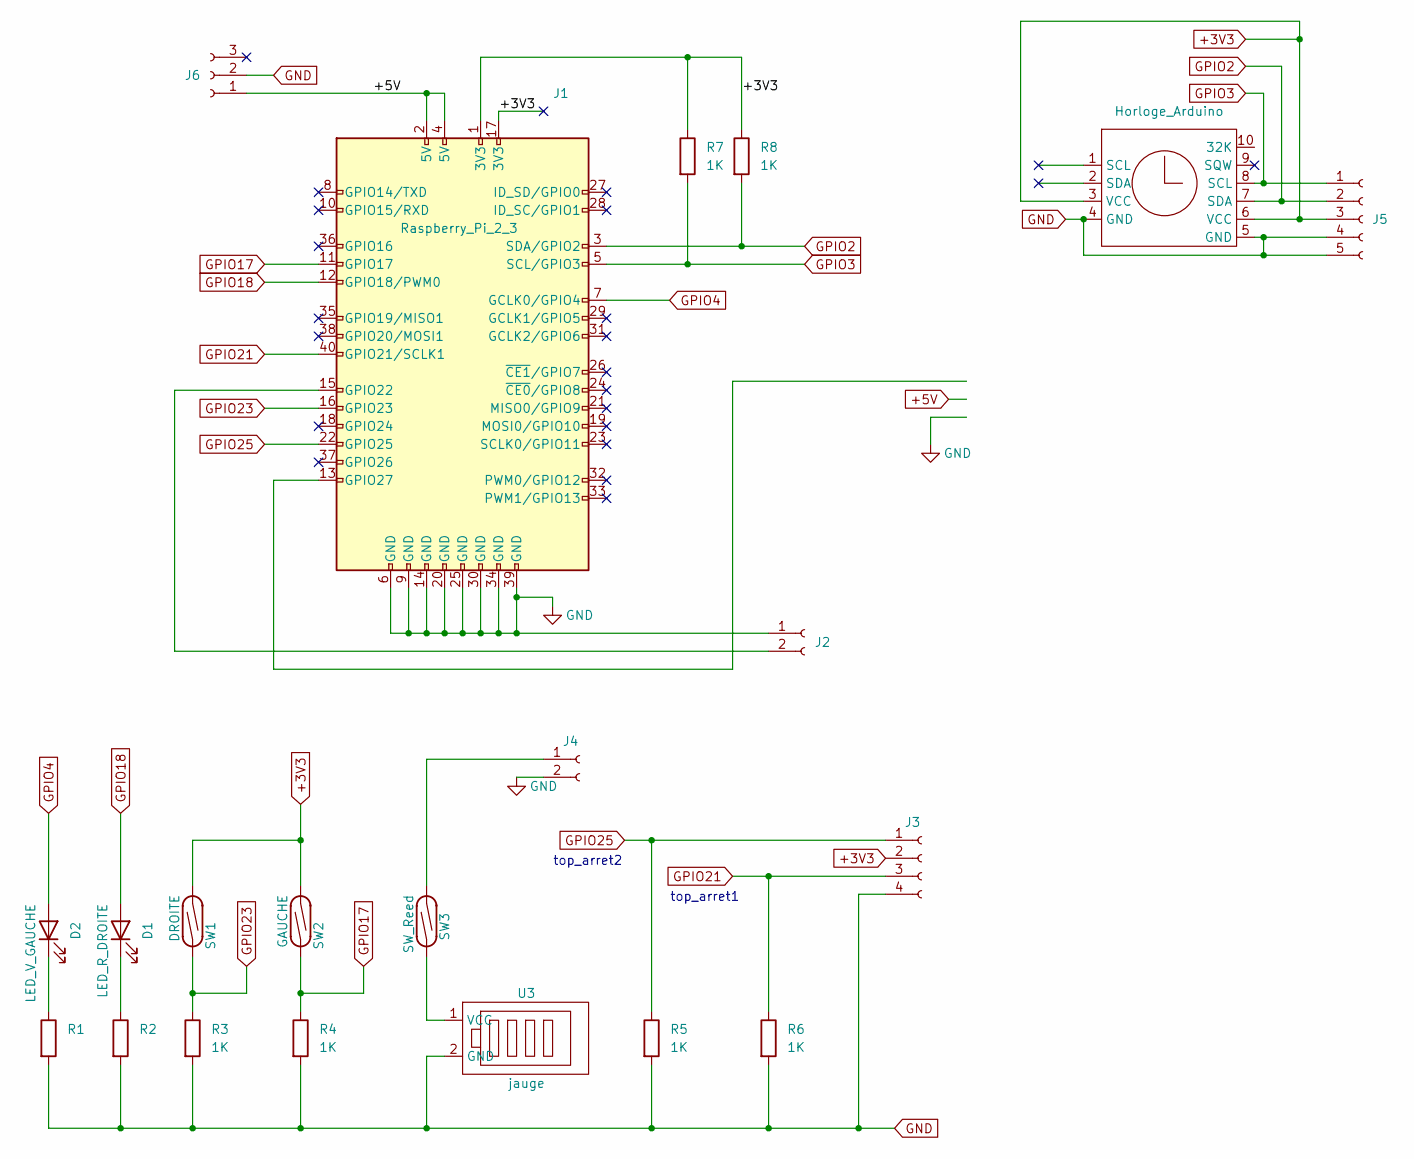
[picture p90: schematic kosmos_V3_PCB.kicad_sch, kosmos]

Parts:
D1: LED_R_DROITE; LED_D5.0mm_FlatTop
D2: LED_V_GAUCHE; LED_D5.0mm_FlatTop
J1: Raspberry_Pi_2_3; PinHeader_2x20_P2.54mm_Vertical
J2: CDE_ESP; PinHeader_1x02_P1.27mm_Vertical
J3: FACADE; PinHeader_1x04_P1.27mm_Vertical
J4: 12v_conv; PinHeader_1x02_P2.54mm_Vertical
J5: Conn_01x05_Female; PinHeader_1x05_P2.54mm_Vertical
J6: 5v_conv; PinHeader_1x03_P2.54mm_Vertical
R1, R2: (no value)
R3, R4, R5, R6, R7, R8: 1K; R_Axial_DIN0207_L6.3mm_D2.5mm_P10.16mm_Horizontal
SW1: DROITE; R_Axial_DIN0207_L6.3mm_D2.5mm_P15.24mm_Horizontal
SW2: GAUCHE; R_Axial_DIN0207_L6.3mm_D2.5mm_P15.24mm_Horizontal
SW3: SW_Reed; R_Axial_DIN0207_L6.3mm_D2.5mm_P15.24mm_Horizontal
U1: Horloge_Arduino; Rtc_arduino
U3: jauge; Jauge_arduino

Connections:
+3V3: J1.1 (3V3), J1.17 (3V3), J3.2, J5.3, R7.1, R8.1, SW1.2, SW2.2, U1.3 (VCC), U1.6 (VCC)
+5V: J1.2 (5V), J1.4 (5V), J6.1; also elsewhere on the board
GND: J1.6 (GND), J1.9 (GND), J1.14 (GND), J1.20 (GND), J1.25 (GND), J1.30 (GND), J1.34 (GND), J1.39 (GND), J2.1, J3.4, J4.2, J5.4, J5.5, J6.2, R1.2, R2.2, R3.2, R4.2, R5.2, R6.2, U1.4 (GND), U1.5 (GND), U3.2 (GND); also elsewhere on the board
GPIO2: J1.3 (SDA/GPIO2), J5.2, R8.2, U1.7 (SDA)
GPIO3: J1.5 (SCL/GPIO3), J5.1, R7.2, U1.8 (SCL)
GPIO4: D2.2 (A), J1.7 (GCLK0/GPIO4)
GPIO17: J1.11 (GPIO17), R4.1, SW2.1
GPIO18: D1.2 (A), J1.12 (GPIO18/PWM0)
GPIO21: J1.40 (GPIO21/SCLK1), J3.3, R6.1
GPIO23: J1.16 (GPIO23), R3.1, SW1.1
GPIO25: J1.22 (GPIO25), J3.1, R5.1
unnamed: D1.1 (K), R2.1
unnamed: D2.1 (K), R1.1
unnamed: J1.15 (GPIO22), J2.2
unnamed 15: J4.1, SW3.2; also elsewhere on the board
unnamed: SW3.1, U3.1 (VCC)

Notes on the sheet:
top_arret2
top_arret1

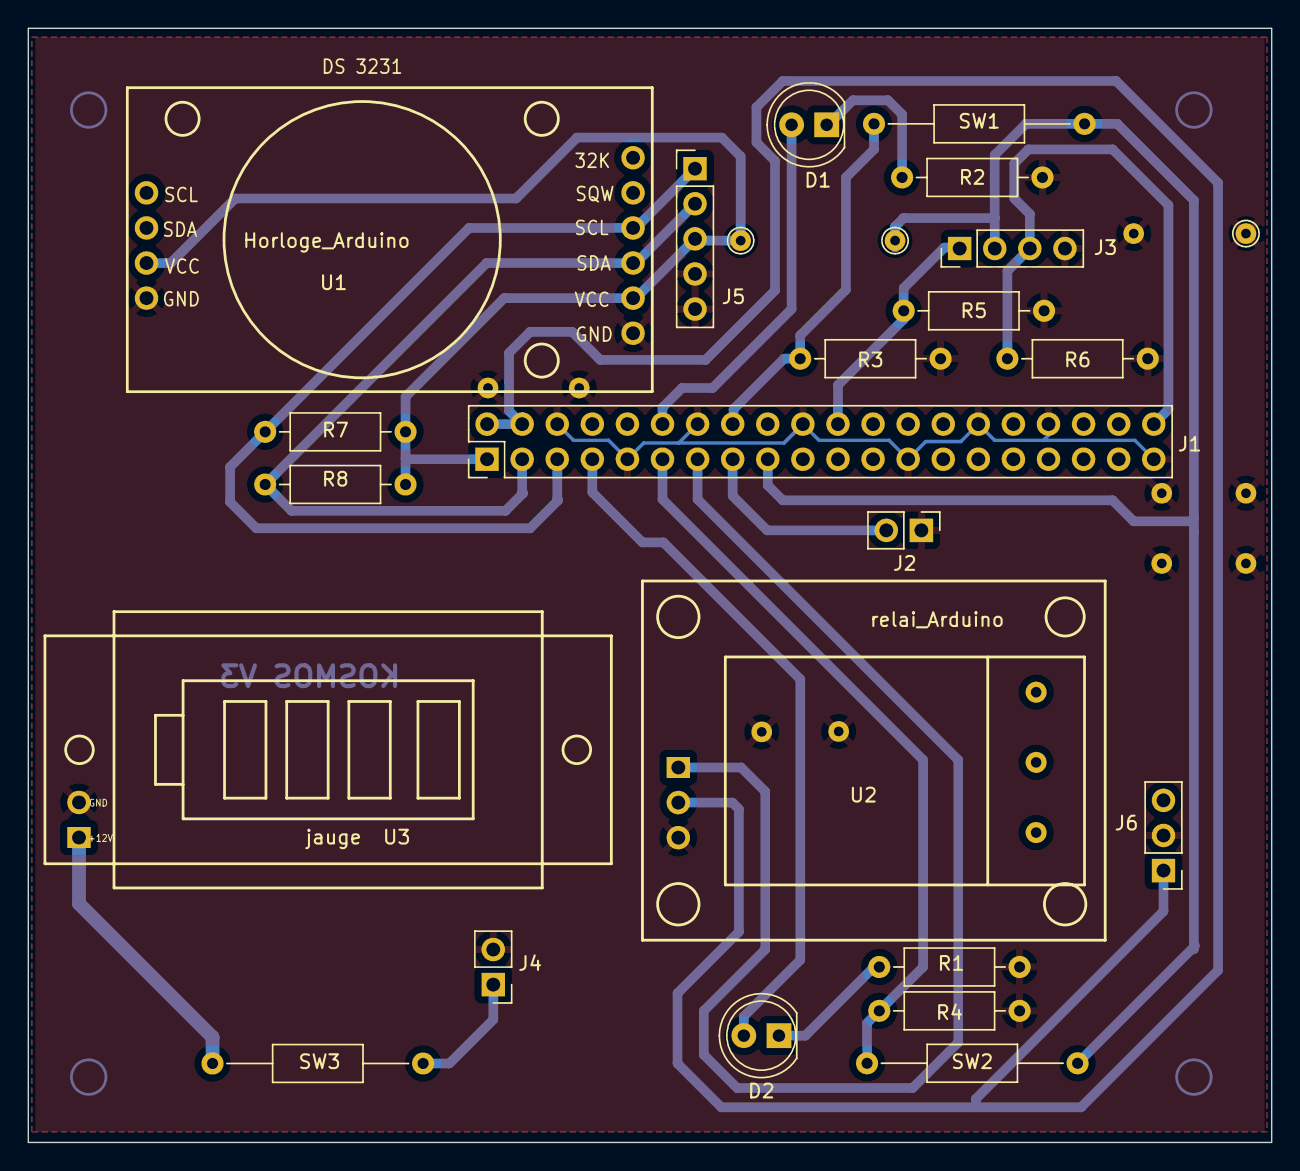
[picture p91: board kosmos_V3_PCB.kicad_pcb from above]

Board: 2 copper layers, 90.0 x 80.6 mm, 22 parts (0 on the bottom side), 16 nets.

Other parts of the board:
J?: 12v_conv; PinHeader_1x02_P2.54mm_Vertical
J?#2: 5v_conv; PinHeader_1x03_P2.54mm_Vertical
U2: relai_Arduino; Relai_arduino

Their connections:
+5V: J?#2.1, U2.2 (VCC); also elsewhere on the board
GND: J?.2, J?#2.2, U2.3 (GND); also elsewhere on the board
unnamed 15: J?.1; also elsewhere on the board

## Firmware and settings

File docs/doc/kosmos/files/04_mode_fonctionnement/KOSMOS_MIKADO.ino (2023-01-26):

//Rentrez le temps d'enregistrement correspondant au temps rentré dans le kosmos_config.ini
int temps_rec=15;
//La sécurité permet d'être sur de ne pas éteindre le KOSMOS avant le shutdown
int securite=3;
//Rentrez les horaires de lancement de l'enregistrer sous le format ( Heure1, Minute1, Heure2, Minute 2, ....)
byte const Heure_dep[]={8,30,10,30,13,37,14,57,15,50,16,43,17,1,20,20};
#include "RTClib.h" //on inclut la librairies pour utiliser l'horloge RTC
//on crée un Serial
#include <SoftwareSerial.h>
const int rx=3;
const int tx=4;
SoftwareSerial mySerial(rx,tx);
RTC_DS1307 rtc;
//On ajoute au temps d'enregistrement la sécurité pour éviter le problème mis en avant plus haut
int time=temps_rec+securite; 
void setup () {
  //Lancement du thread
  mySerial.begin(115200);
  pinMode(1,OUTPUT); // La broche 1 est définie en sortie GPIO
  // Attente de la connection serie avec l'Arduino
  while (!mySerial);
 
  // Lance le communication I2C avec le module RTC et attend que la connection soit operationelle
  while (! rtc.begin()) {
    mySerial.println("Attente du module RTC...");
    delay(1000);
  }
 
  // Mise à jour de l'horloge du module RTC avec la date et l'heure courante au moment de la compilation de ce croquis
  rtc.adjust(DateTime(F(__DATE__), F(__TIME__)));
 
  mySerial.println("Horloge du module RTC mise a jour");
}
 
void loop () {
    DateTime now = rtc.now();
    char heure[10];
 
    // Affiche l'heure courante retournee par le module RTC
    // Note : le %02d permet d'afficher les chiffres sur 2 digits (01, 02, ....)
    //sprintf(heure, "Il est %02d:%02d:%02d", now.hour(), now.minute(), now.second());
    //mySerial.println(heure);
    for (int i=0;i<24;i+=2){ // on vient tester les différentes valeur dans la liste d'heure rentrée au-dessus
      if ( now.hour()==Heure_dep[i] && now.minute()==Heure_dep[i+1]){ //Lorsque l'heure et la minute sont égales à une horraires rentrée plus haut on rentre dans une boucle infinie
        while(1){ 
          DateTime now = rtc.now(); //on réactualise l'heure
          if ((Heure_dep[i+1]+time)<60){ // C'est le cas général : on ne change pas d'heure en ajoutant "time"
            if (now.hour()==Heure_dep[i] && now.minute()==Heure_dep[i+1]+time){ 
              break; // si l'heure et la minute correspondent au temps de départ plus "time" on sort de la boucle while
            }
          }
          else{ // on gère l'exception du changement d'heure.
            int Heure_arr=Heure_dep[i]+1; // On passe à l'heure d'après
            int Minute_arr=(Heure_dep[i+1]+time)%60; // on garde les minutes restantes
            if (now.hour()==Heure_arr && now.minute()==Minute_arr){ 
              break; // si l'heure et la minute correspondent au temps de départ plus "time" on sort de la boucle while
            }
          }
          digitalWrite(1,HIGH); // Tant qu'on est dans la boucle infinie, on met la position du GPIO à "HIGH" -> on allume la raspberry
        }
      }
      digitalWrite(1,LOW); // Sinon on laisse éteint la raspberry
    }
}

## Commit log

2022-07-06 rename to assembly-guide_fr
2022-07-06 ajout de la liste de matériel
2022-07-06 ajout des fournitures
2022-07-06 Suppression de materiels, tools et intro
2022-07-06 ajout de la photo de garde
2022-07-06 ajoiut de la photo de garde
2022-07-07 Mise a jour des numéros de parties
2022-07-07 Ajout des images étape 2
2022-07-08 ajout de la licence
2022-07-08 Ajout de photos AG etape 1
2022-07-11 Ajout de la photo du kosmos
2022-07-11 doc d'utilisation de git
2022-07-12 Ajout des modèles 3D intérieurs
    [I1_KOSMOS_V3-0.stl, I2_KOSMOS_V3-0.stl, I3_KOSMOS_V3-0.stl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]
2022-07-12 ajout des fils 3D intérieurs
    [I1_KOSMOS_V3-0.stl, I2_KOSMOS_V3-0.stl, I3_KOSMOS_V3-0.stl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]
2022-07-12 Ajout des pièces 3D extérieurs
    Il manque les connecteurs des deux passes câbles
    [R1.2_KOSMOS_V3-0.stl, R1_KOSMOS_V3-0.stl, R2_KOSMOS_V3-0.stl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]
2022-07-12 Ajout des flasques et carters
2022-08-09 Mise à jour des photos pour l'assemblage intérieur
2022-08-09 Changement des photos pour l'assemblage intérieur
2022-08-12 changement de quelques images
2022-08-12 Quelques images fusion pour l'assemblage du réducteur
2022-08-26 Ajout de la calibration
    Merci Maël
2022-08-26 Add calibrate.md
2022-09-22 Update avec la doc V1 des connectiques internes
2022-09-22 Ajout des photos pour la doc du cablage intérieur
2022-09-22 ajout shèma de montage des connectiques alim
2022-09-23 Ajout des photos pour connectique end cap
2022-09-26 Ajout software
    [pyvenv.cfg]
2022-09-27 ajout de l'install du soft
2022-09-28 Ajout des visuels pour les pièces R
2022-09-28 Détails des pièces extérieurs
2022-09-28 Corrections erreurs de frappe
    Corrections erreurs de frappe
    Yves
2022-09-29 Mise a jour des pièces extérieur 3D
    [R7-2_KOSMOS_V3-0.stl, R7_KOSMOS_V3-0.stl, R8-2_KOSMOS_V3-0.stl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]
2022-09-30 Ajout du tableur des fournitures
    [materials.ods]
2022-10-04 Mise à jour pièce I3 (adapté à l'objectif Edmund)
    [I3_KOSMOS_V3-0.stl]
2022-10-05 ajout des photos pour partie 4.1
2022-10-05 Ajout de la partie 4.1
2022-10-05 Ajout des photos pour 4.1
2022-10-05 Mise a jour de la liste de matos
    Vis du capteur magnétique extérieur
    [materials.ods]
2022-10-24 Ajout de la doc pour le sourcing
    [materials.ods, sourcing_kosmos30_fr_221024.ods]
2022-10-26 Ajout dans AG de la connectique etanche
2022-10-29 Check by Yves
    Corrections de quelques fautes d'orthographe
2022-11-04 Ajout de fichiers autocollants
2022-11-10 MAJ nomenclature et doc
    [kosmos_V3_PCB.kicad_pcb, sourcing_kosmos30_fr_221024.ods]
2022-11-21 je sais plus
    [kosmos_V3_PCB-B_Courtyard.gbr, kosmos_V3_PCB-B_Cu.gbr, kosmos_V3_PCB-B_Mask.gbr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]
2022-11-23 correction de qqes typos
2022-11-28 redac de l-intro
2022-12-01 Update README.md
    qqes modfs de forme
2023-01-16 Ajout des fichiers 3D modifiables et guide
    [Adaptateur_paralenz_caisson_moteur.f3d, Assemblage_ber_KOSMOS3-0.f3z, Assemblage_croix_de_malte_KOSMOS3-0.f3z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]
2023-01-26 Ajout de doc draft pour mode micado
2023-02-08 Soudure PCB
2023-02-09 modif lien R1-2
    [R1-2_KOSMOS_V3-0.stl]
2023-02-09 mise à jour sourcing
    [sourcing_kosmos30_fr_221024.ods]
2023-02-10 finish soudure PCB
2023-02-10 finish soudure PCB2
2023-04-12 correction faute d'orthographe page intro pour tester la contribution à la doc
2023-04-12 modification de la taille de la vis trop petite pour l'assemblage de la caméra
2023-04-19 on échange 2 étapes car on ne peut pas mettre les colsons car la raspberry gêne
2023-04-19 rajout de nouvelles photos de l'assemblage structure S1, esc et convertisseur sans la raspberry (cohérence), comme nous n'avions pas d'entretoise nous avons fait fixé la raspberry seulement avec des 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
2023-04-19 remplacement des photos sur la readthedoc
2023-04-19 erreur d'écriture pour l'ajout des photos
2023-04-19 modification du texte explicatif pour la fixation de l'ESC due au changement de modèle d'ESC et les vis données encore trop petites pour la fixation (encore une fois, n'ayant pas les entretoises nous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
2023-12-07 Rename README.md to index.md
    Le nouveau read the doc demande la présence dans le dossier docs, d'un fichier index.md
2023-12-07 Update mkdocs.yml
    Il y a ici :
    - J'ai ajouté le lien vers le dépot github comme ca sur le read the doc il y aura un lien direct vers le dépôt.
    - Read the doc bug quand il vois le plugin "i18n" donc je l'ai viré.
2023-12-07 Update .readthedocs.yaml
    Là c'était différent de mes dépot alors je teste
2024-06-18 new branch
    [Adaptateur_paralenz_caisson_moteur.f3d, Assemblage_ber_KOSMOS3-0.f3z, Assemblage_croix_de_malte_KOSMOS3-0.f3z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]
2024-07-08 modification du processus de msie au point de la caméra
2024-07-26 modif focus camera + assembly guide µkosmos
2025-09-23 Mise à jour de la check-list
    création d'une check-list PRÉPARATION et d'une check-list MATÉRIEL
2025-10-14 ajout de la doc 4.0
2025-10-14 mise à jour de version template (Jinja2 et MkDocs Material)
2025-10-14 ajout de la page KOSMOS_4.0
